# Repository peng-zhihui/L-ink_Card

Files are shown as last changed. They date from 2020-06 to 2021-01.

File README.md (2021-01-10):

# [L-ink]电子墨水屏NFC智能卡片
> 这是为了解决个人使用IC卡时遇到的一些痛点设计的一个迷你NFC智能卡片，基于STM32L051和ST25DV。
>
> 想着既然要自制这玩意那就往炫酷了做，于是很自觉地把电子墨水屏也加上了，顺手也写了个配套APP用于显示内容定制。
>
> 总之是个比较有意思的小项目，方案不算复杂，第一版设计也存在一些值得改进的地方，后续有空会继续优化方案设计的。

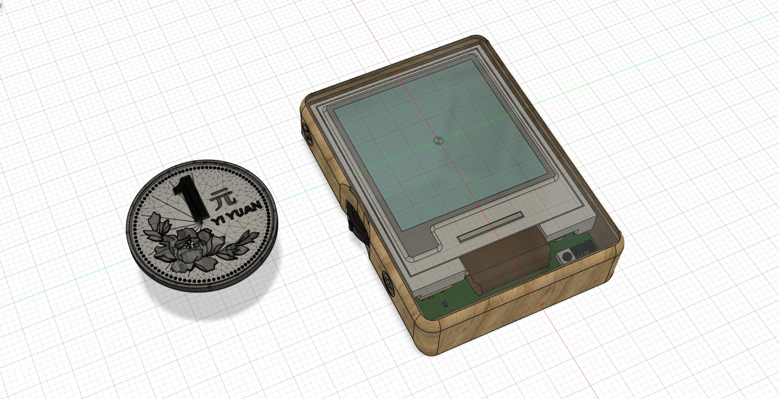
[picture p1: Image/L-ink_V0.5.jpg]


## 演示视频

B站指路：https://www.bilibili.com/video/BV1Cf4y1y7KT/

## 项目文件说明

* **Hardware**：source里面是电路原理图和PCB文件，使用Altium Designer打开；release里面是gerber文件可以直接发给厂家打样，也包含了元器件BOM表（部分IC不太常用可能要单独购买）。
* **Firmware**：STM32L051的固件，我提供了Clion和Keil两个版本的工程文件，源码内容是一致的，分两个版本只是因为个人对Clion爱得深沉。
* **3D Model**：屏幕架和外壳的3D文件，step格式一般3D建模软件都能打开编辑，STL格式用于直接3D打印。
* **DAP-Link**：自己设计的下载调试器的硬件和固件源码，也包括预编译的hex固件，如果你有J-Link或者ST-Link之类的下载器就不用这个了。
* **Android**：配套的APP安装包。

## 固件编译说明

STM32因为使用了L0系列的MCU，所以如果你是第一次在你的电脑上开发STM32L0，那么需要先装一下L0的固件支持包，有两种方式：

1. 使用STM32CubMX安装：

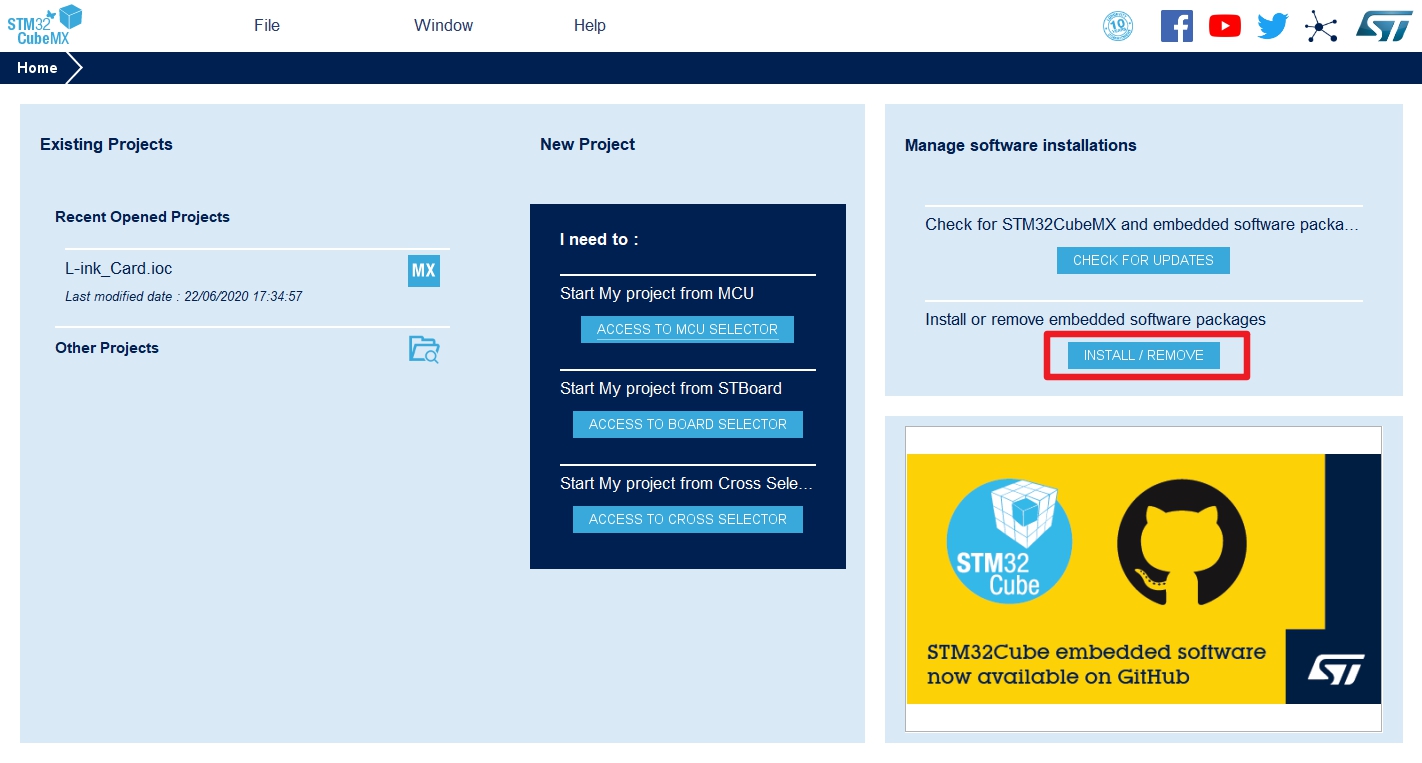
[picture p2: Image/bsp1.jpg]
   

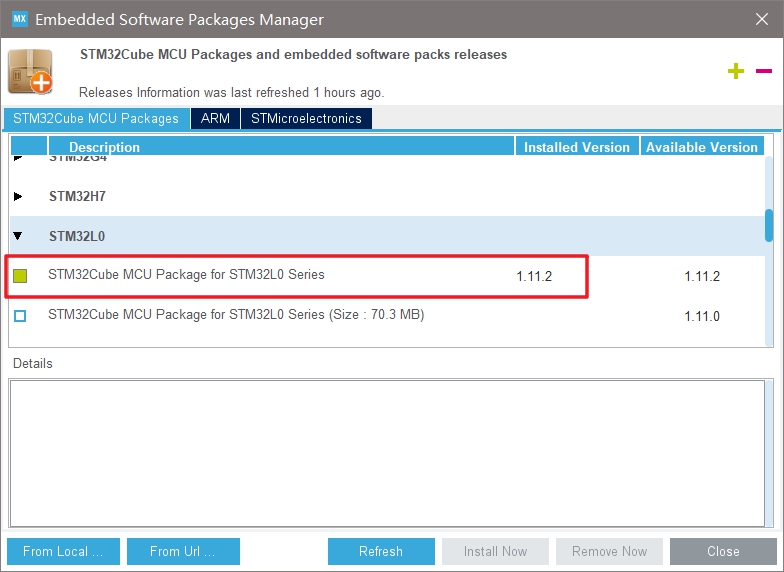
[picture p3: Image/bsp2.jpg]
   

2. 使用Keil的Package Installer安装：

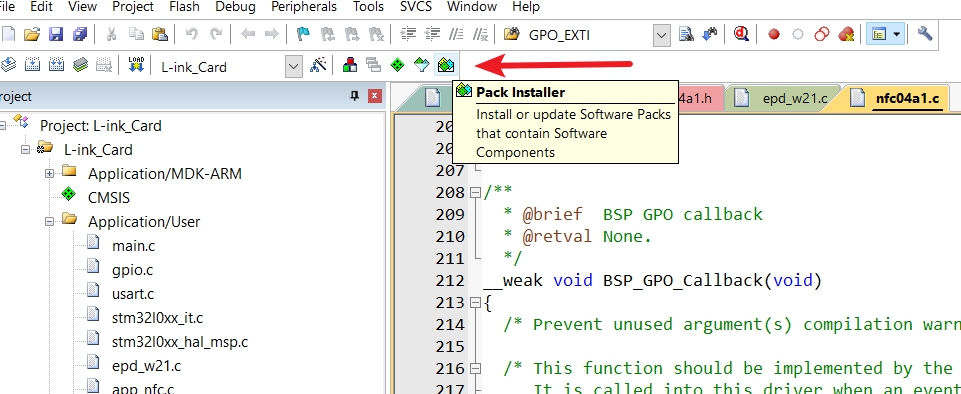
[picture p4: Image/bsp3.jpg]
   

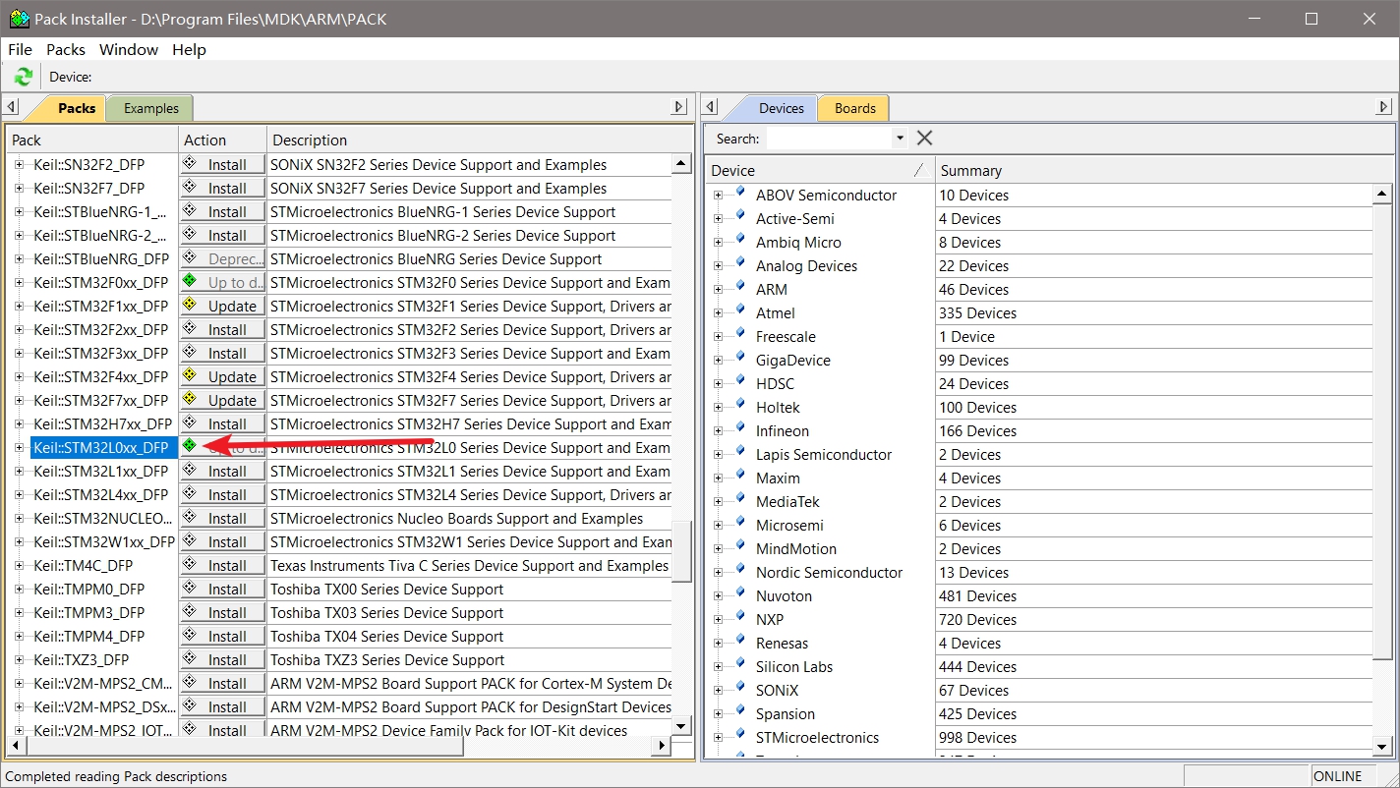
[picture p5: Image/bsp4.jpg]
   

然后就不会报头文件的错误了。

有几点注意的：

* 如果想在Clion中编译工程的话可以参考我这篇教程：https://zhuanlan.zhihu.com/p/145801160
* Clion中OpenOCD默认是使用ST-Link下载，其他下载器自己修改工程目录下的stlink.cfg文件

## 关于硬件方案

硬件方案比较简单，主要IC就两个--STM32和ST25DV，电子墨水屏是200x200的单色屏幕，我是买的微雪的（注意如果是买的几年前的库存，那驱动芯片会有点区别导致代码不通用，只要是新款的应该都没问题）。

ST25DV作为NFC的PHY通过I2C总线和STM32通信，主要作用有两个：能量采集以及NFC通信。注意，ST25DV只是负责和手机进行NFC通信，而不负责IC卡的读写功能，因为**ST25DV只支持ISO 15693的RFID协议，而我们常用的IC卡（M1卡）是ISO 14443协议的**，所以并不能直接使用这颗芯片进行IC卡模拟。

IC卡的模拟功能这一版中实现得比较简单，就是直接集成了多颗UID芯片（很便宜，1~2元一片），然后和ST25DV共用NFC天线，卡片的切换是通过拨轮换挡实现的。好处在于，你可以把L-ink当作多张独立卡片的合集处理，复制和刷卡都是很直接的（使用PM3或者PN532等模块读取原卡信息并写入L-link）。当然缺点就是添加的卡片一多，按键的数量就要增加（因为每一档对应一张卡）。

所以我也在改进方案，后面可能会使用支持ISO 14443协议的ST95或者ST25T系列的芯片来实现软件层面的IC卡模拟功能。

另外下一个版本的硬件方案**我会把黑白的电子墨水屏换成彩色的**。

## 关于配套APP

Android APP目前只是实现了功能，这是基于我以前做的一个算法验证框架APP改的，UI还没有重新做设计，可以等后续更新。

工程文件的话我后面可以把其中的核心功能模块封装成Module，然后给个Sample Project供参考使用，工作太忙等我缓过这阵子先~

## 教程整理中...

有问题先看Issue（包括已经close的），另外

#### 跟项目工程无关的问题不要发在Issues里面！跟项目工程无关的问题不要发在Issues里面！跟项目工程无关的问题不要发在Issues里面！

聊天内容可以给我发评论或者私信（B站、知乎），我看到的话基本都会回复，issue里面发的话所有watch项目的人都会收到邮件，会对大家产生困扰的！

---

**以下是[simonire](https://github.com/simonire)修改的版本，适配新款的屏幕驱动，修改拨轮为五维按键，有需要的可以参考：**

https://github.com/simonire/L-ink_Card



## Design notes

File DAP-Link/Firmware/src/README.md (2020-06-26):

DAPLink (https://armmbed.github.io/DAPLink/)

Arm Mbed DAPLink is an open-source software project that enables programming and debugging application software running on Arm Cortex CPUs. Commonly referred to as interface firmware, DAPLink runs on a secondary MCU that is attached to the SWD or JTAG port of the application MCU. This configuration is found on nearly all development boards. Enumerating as a USB composite device, it creates a bridge between your development computer and the CPU debug access port. DAPLink enables developers with:
* MSC - drag-n-drop programming flash memory
* CDC - virtual com port for log, trace and terminal emulation
* HID - CMSIS-DAP compliant debug channel
* WEBUSB HID - CMSIS-DAP compliant debug channel

More features are planned and will show up gradually over time. The project is constantly under heavy development by Arm, its partners, numerous hardware vendors and the open-source community around the world. DAPLink has superseded the mbed CMSIS-DAP interface firmware project. You are free to use and contribute. Enjoy!

For more detailed usability information [see the users guide.](docs/USERS-GUIDE.md)

## Compatibility
There are many ARM microcontroller-based Hardware Interface Circuits (HICs) that DAPLink interface firmware runs on. These can be found as standalone boards (debugger) or as part of a development kit. Some branded circuits that are known to be IO compatible are:
* [NXP OpenSDA based on K20, K22 and KL26](http://www.nxp.com/products/software-and-tools/run-time-software/kinetis-software-and-tools/ides-for-kinetis-mcus/opensda-serial-and-debug-adapter:OPENSDA)
* [NXP LPC-Link2 based on LPC11U35 or LPC4322](https://www.nxp.com/support/developer-resources/hardware-development-tools/lpcxpresso-boards:LPCXPRESSO-BOARDS)
* [Segger J-Link OB based on Atmel SAM3U](https://www.segger.com/products/debug-probes/j-link/models/j-link-ob/)

## Releases
There are many board builds (board = HIC + target combination) created from this repository. Quarterly releases will contain new features and bugfixes. Standalone bugfixes are released once reported, verified and fixed. Both quarterly and bugfix releases will result in the build number being incremented. Many development kits and products ship with DAPLink interface firmware or are capable of running DAPLink firmware. **[The current release builds and instructions for updating DAPLink interface firmware is hosted on the DAPLink release site.](https://armmbed.github.io/DAPLink/)** Release notes and previous release builds can be found under GitHub releases.

## Contribute

We welcome contributions to DAPLink in any area. Look for an interesting feature or defect [under
issues](https://github.com/ARMmbed/DAPLink/issues), or start a new thread to engage with the
developers and maintainers.

Please see the [contribution guidelines](CONTRIBUTING.md) for detailed requirements for
contributions.

To report bugs, please [create an issue](https://github.com/ARMmbed/DAPLink/issues/new) in the
GitHub project.

## Develop
Information for setting up a development environment, running the tests or creating a release build [can be found in the developers guide.](docs/DEVELOPERS-GUIDE.md)

## License
DAPLink is licensed with the permissive Apache 2.0 license. See the [LICENSE](LICENSE) file for the
full text of the license.

Copyright © 2006-2019 Arm Ltd

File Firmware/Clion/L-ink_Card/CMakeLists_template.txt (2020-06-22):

#THIS FILE IS AUTO GENERATED FROM THE TEMPLATE! DO NOT CHANGE!
SET(CMAKE_SYSTEM_NAME Generic)
SET(CMAKE_SYSTEM_VERSION 1)
cmake_minimum_required(VERSION 3.7)

# specify cross compilers and tools
SET(CMAKE_C_COMPILER_WORKS 1)
SET(CMAKE_C_COMPILER arm-none-eabi-gcc)
SET(CMAKE_CXX_COMPILER_WORKS 1)
SET(CMAKE_CXX_COMPILER arm-none-eabi-g++)
set(CMAKE_ASM_COMPILER arm-none-eabi-gcc)
set(CMAKE_AR arm-none-eabi-ar)
set(CMAKE_OBJCOPY arm-none-eabi-objcopy)
set(CMAKE_OBJDUMP arm-none-eabi-objdump)
set(SIZE arm-none-eabi-size)

SET(LINKER_SCRIPT ${CMAKE_SOURCE_DIR}/STM32L051K8Tx_FLASH.ld)

#Uncomment for hardware floating point
#SET(FPU_FLAGS "-mfloat-abi=hard -mfpu=fpv4-sp-d16")
#add_definitions(-DARM_MATH_CM4 -DARM_MATH_MATRIX_CHECK -DARM_MATH_ROUNDING -D__FPU_PRESENT=1)

#Uncomment for software floating point
#SET(FPU_FLAGS "-mfloat-abi=soft")

SET(COMMON_FLAGS
        "-mcpu=cortex-m0 ${FPU_FLAGS} -mthumb -mthumb-interwork -ffunction-sections -fdata-sections \
    -g -fno-common -fmessage-length=0 -specs=nosys.specs -specs=nano.specs")

SET(CMAKE_CXX_FLAGS_INIT "${COMMON_FLAGS} -std=c++11")
SET(CMAKE_C_FLAGS_INIT "${COMMON_FLAGS} -std=gnu99")
SET(CMAKE_EXE_LINKER_FLAGS_INIT "-Wl,-gc-sections,--print-memory-usage -T ${LINKER_SCRIPT}")

PROJECT(L-ink_Card C CXX ASM)
set(CMAKE_CXX_STANDARD 11)

#add_definitions(-DARM_MATH_CM4 -DARM_MATH_MATRIX_CHECK -DARM_MATH_ROUNDING -D__FPU_PRESENT=1)
add_definitions(-DUSE_HAL_DRIVER -DSTM32L051xx)

file(GLOB_RECURSE SOURCES "startup/*.*" "Packs/*.*" "Drivers/*.*" "Src/*.*" "BSP/*.*")

include_directories(Drivers/BSP/ST25DV Drivers/BSP/E-Paper-Display Inc Drivers/STM32L0xx_HAL_Driver/Inc Drivers/STM32L0xx_HAL_Driver/Inc/Legacy Drivers/CMSIS/Device/ST/STM32L0xx/Include Drivers/CMSIS/Include Drivers/BSP/Components/ST25DV Drivers/BSP/NFC04A1 Drivers/BSP/Drivers/BSP/NFC04A1)

add_executable(${PROJECT_NAME}.elf ${SOURCES} ${LINKER_SCRIPT})

set(CMAKE_EXE_LINKER_FLAGS
        "${CMAKE_EXE_LINKER_FLAGS} -Wl,-Map=${PROJECT_BINARY_DIR}/${PROJECT_NAME}.map")

set(HEX_FILE ${PROJECT_BINARY_DIR}/${PROJECT_NAME}.hex)
set(BIN_FILE ${PROJECT_BINARY_DIR}/${PROJECT_NAME}.bin)

add_custom_command(TARGET ${PROJECT_NAME}.elf POST_BUILD
        COMMAND ${CMAKE_OBJCOPY} -Oihex $<TARGET_FILE:${PROJECT_NAME}.elf> ${HEX_FILE}
        COMMAND ${CMAKE_OBJCOPY} -Obinary $<TARGET_FILE:${PROJECT_NAME}.elf> ${BIN_FILE}
        COMMENT "Building ${HEX_FILE}
Building ${BIN_FILE}")

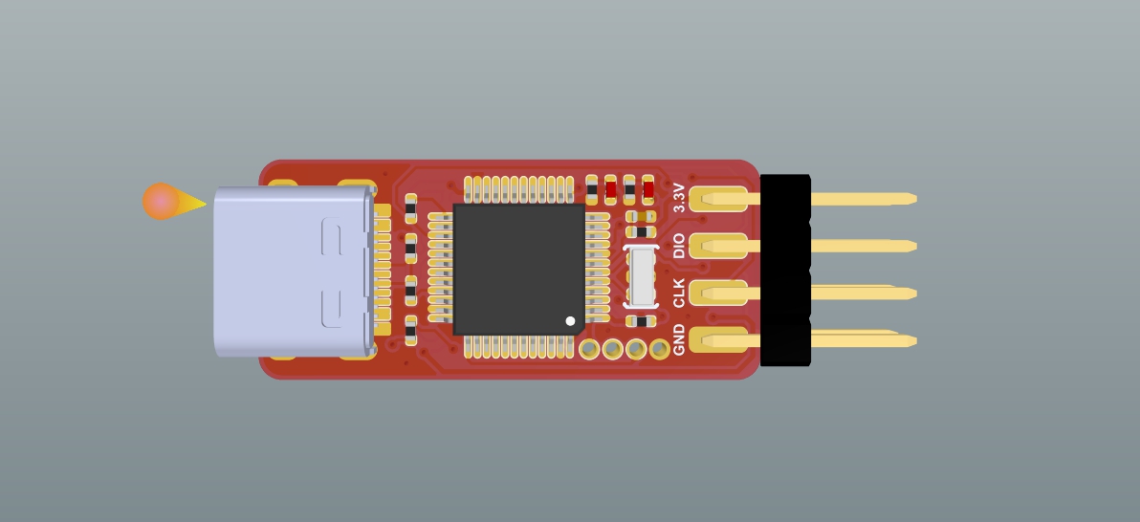
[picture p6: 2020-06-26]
DAP-Link/image.jpg

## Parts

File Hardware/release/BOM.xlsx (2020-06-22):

Comment | Description | Designator | Footprint | LibRef | Quantity
Battery | Battery | Battery1 | CR2032-1 | Battery | 1
10uF | Capacitor | C1 | CAP_0402 | 电容-0402 | 1
10nF | Capacitor | C2 | CAP_0402 | 电容-0402 | 1
0.1uF | Capacitor | C3, C6, C7 | CAP_0402 | 电容-0402 | 3
1uF | Capacitor | C4, C5, C8, C9, C10, C11, C13, C14 | CAP_0402 | 电容-0402 | 8
4.7uF | Capacitor | C12 | 0603-CAP | 电容-0603 | 1
color? | LED | D1 | LED_0402_BLUE | LED_0402 | 1
二极管-5819W | 40V | D2, D3, D4 | SOD-123 | 二极管-5819W | 3
FFC_0.5_24 | FFC | FFC1 | FFC_0.5_24_INK | FFC_0.5_24_INK | 1
跳线 | Resistor | J1 | 0402-0R | 跳线 | 1
TACT 2P | Button | K1 | ButtonTACT_3x4x2_180H | ButtonTACT_3x4x2_180 | 1
68uH | 磁珠 | L1 | 2520-L | 电感-2520 | 1
4.7uH | 磁珠 | L2 | 0805-L | 电感-0805 | 1
HDR1x4_2.0 |  | P1 | HDR 4_2 | HDR1x4_2.0 | 1
MOSFET-N | N-Channel MOSFET | Q1 | SOT23-3 | MOSFET-N | 1
10K | Resistor | R1, R6, R11 | RES_0402 | 电阻-0402 | 3
1K5 | Resistor | R2, R3 | RES_0402 | 电阻-0402 | 2
20K | Resistor | R4 | RES_0402 | 电阻-0402 | 1
1K | Resistor | R5, R7 | RES_0402 | 电阻-0402 | 2
3K | Resistor | R8 | RES_0402 | 电阻-0402 | 1
NC | Resistor | R9 | RES_0402 | 电阻-0402 | 1
0R | Resistor | R10 | RES_0402 | 电阻-0402 | 1
3R | Resistor | R12 | RES_0402 | 电阻-0402 | 1
WHEEL_SWITCH | LDO | S1 | WHEEL_SWITCH | WHEEL_SWITCH | 1
ST25DV16K-JFR6D3 | RFID Transponder IC 13.56MHz ISO 15693 I?2C 1.8V ~ 5.5V 12-UFDFN Exposed Pad | U1 | PSON50P-302X302X60-13N | ST25DV16K-JFR6D3 | 1
STM32L051K8 |  | U2 | QFN-32 | STM32L051K8 | 1
TPS61221DCKT | Boost Switching Regulator IC Positive Fixed 3.3V 1 Output 200mA _Switch_ 6-TSSOP, SC-88, SOT-363 | U3 | SOT65P210X110-6N | TPS61221DCKT | 1

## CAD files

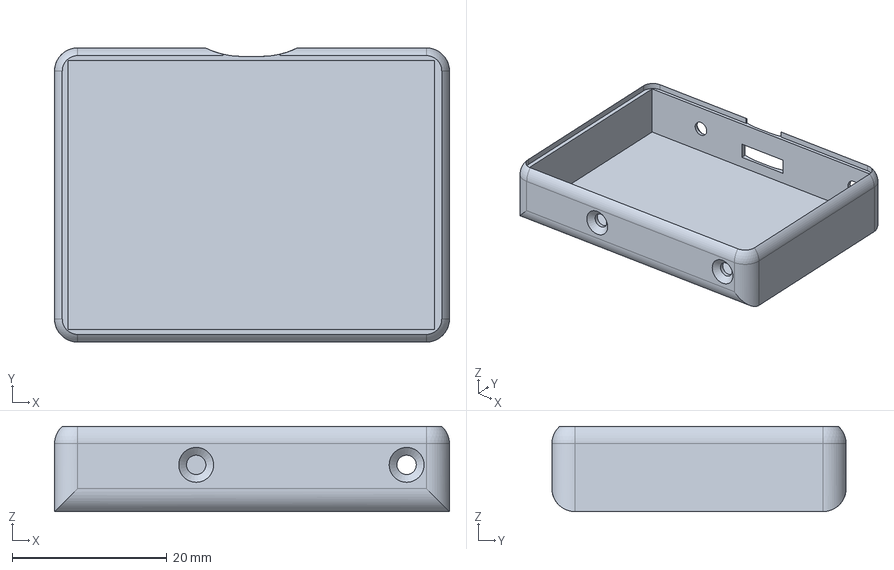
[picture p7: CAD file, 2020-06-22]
3D Model/1.discrete version/case.step
51.0 x 38.0 x 11.0 mm

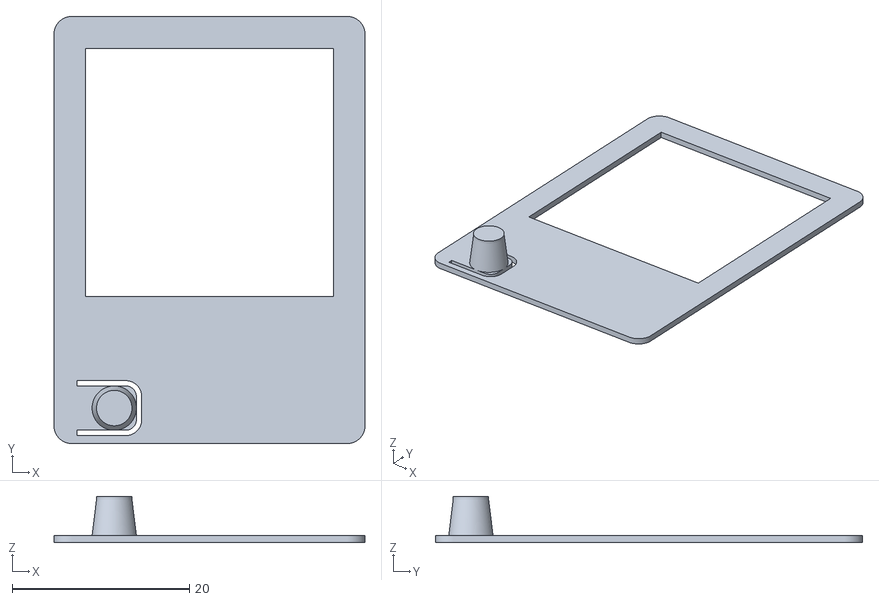
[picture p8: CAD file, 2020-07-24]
3D Model/2.unibody version/L-ink-up.STL.stl
35.1 x 48.2 x 5.20

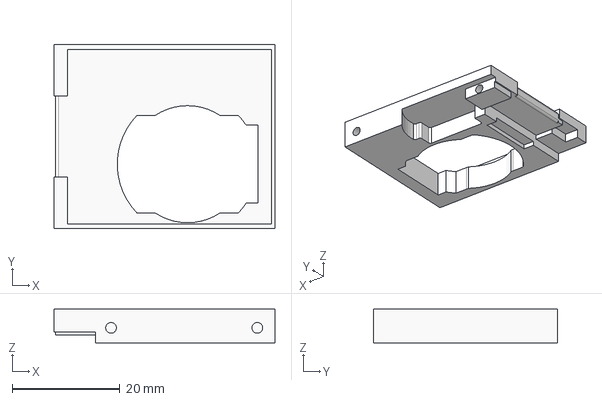
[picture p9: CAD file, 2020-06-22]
3D Model/1.discrete version/stand.step
41.0 x 34.2 x 6.30 mm

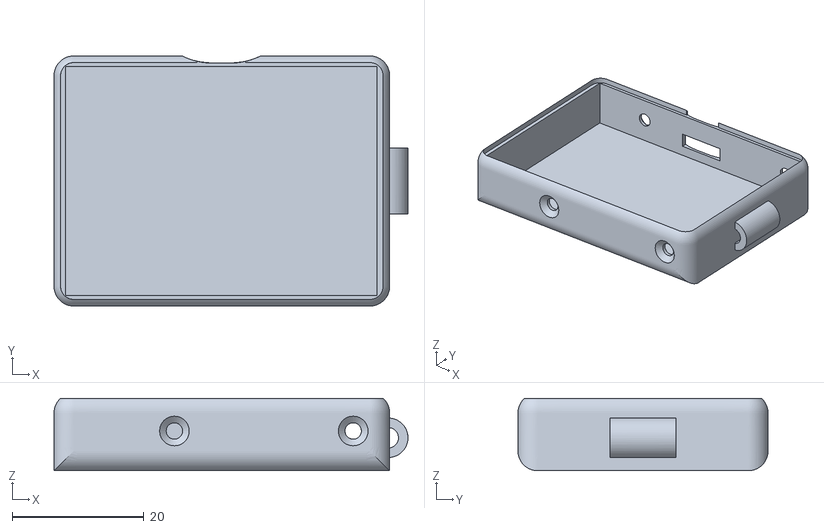
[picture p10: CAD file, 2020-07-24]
3D Model/2.unibody version/case with hook.stl
53.8 x 38.0 x 11.0

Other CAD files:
3D Model/2.unibody version/stand.stl
3D Model/1.discrete version/case.stl
3D Model/1.discrete version/stand.stl

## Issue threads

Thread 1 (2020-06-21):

感谢大佬开源，关注大佬很久了，视频都是跪着看完的~~

luxunchina, 2020-06-21:
这个迷你NFC卡片超酷的啊，有木有？可以复制任意卡片的功能我真是酸了，好想有一个，奈何动手能力极差，希望各位关注此项目的老板做好后给个链接，我想直接买个成品，跪谢~

WHYEX3, 2020-06-21:
3分钟前？readme热乎乎

San12341, 2020-06-21:
我也想直接买成品。

WHYEX3, 2020-06-21:
> 我也想直接买成品。

+1，如果教程我能看懂的话且成本低，我想自己搞一个

peng-zhihui, 2020-06-21:
感谢关注~项目也还是有一些不完善的地方的，后面有空我会继续更新方案的哈

ahdiua, 2020-06-22:
> 感谢关注~项目也还是有一些不完善的地方的，后面有空我会继续更新方案的哈

三连啦，就等大佬发教程

XenoAmess, 2020-06-22:
> 感谢关注~项目也还是有一些不完善的地方的，后面有空我会继续更新方案的哈

硬件和C我这边帮不上忙
如果安卓端放源码的话 可以试试。。。

xdeng, 2020-06-22:
求成品链接，我要买十个。急需。

peng-zhihui, 2020-06-22:
不属于Issue的不要发在这里哈~

Closed 2020-06-22.

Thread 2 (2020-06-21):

大佬能否分享一下android app工程文件

hanjianwei92, 2020-06-21:
大佬能否分享一下app的工程文件

baolintian, 2020-06-21:
+1

peng-zhihui, 2020-06-21:
> 大佬能否分享一下app的工程文件

工程文件的话因为这是我以前做的一个框架改的，而这个框架有用在我们公司的项目里面，所以不知道好不好分享出来。不过我后面可以把其中的核心功能模块封装成库，然后给个Sample Project供参考，等我忙过这阵子吧。

bosssyyyy, 2020-06-21:
大佬能否上传一下ASCII版本的ad文件，目前没有购买安装ad无法转换文件类型

Closed 2020-06-22.

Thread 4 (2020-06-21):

main函数里面的所有头文件报错（file not found）是什么原因呀？

Xuyinsong, 2020-06-21:

peng-zhihui, 2020-06-21:
keil工程还是clion，应该是你工程配置的问题，先保证基础工程（比如新建一个LED点灯工程）能跑通再说。

Xuyinsong, 2020-06-21:
我用的是clion，就是按照您上次分享的博文配置的，有在板子上试过LED灯和串口是可以的。我下载工程文件后就直接用clion打开的，然后就出现了找不到文件的错误，我是第一次用这个，所以配置的问题不是很明白。

peng-zhihui, 2020-06-21:
Clion里面tools-cmake-reset cache... 然后重新编译试试看，另外因为芯片是STM32L0，需要在STM32CubeMX软件的首页选择“INSTALL or REMOVE embedded software...”里面安装L0的支持包

Xuyinsong, 2020-06-22:
可以了，嘿嘿！文件放到桌面就可以编译了，在硬盘的文件夹就会报错，不知道什么原因。

orzMaster, 2020-06-22:
你是不是放在中文目录下了.

Xuyinsong, 2020-06-22:
是的，可能是这个原因

Closed 2020-06-22.

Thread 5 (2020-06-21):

对nfc有个疑问

Guet-Bantao, 2020-06-21:
任意复制卡片的话，不会冲突吗？
比如多个卡片信息都存在同一扇区

peng-zhihui, 2020-06-21:
仔细看一下硬件工程文件，简单地说目前IC卡的信息是存在每个单独的UID芯片（很便宜大概1~2元一个）上的，ST25有两个作用，一个是能量采集，一个是负责作为手机和MCU通信的桥梁（NFC-PHY）；也就是可以理解为L-ink里面是有多个芯片，共用一个线圈，靠开关切换。之所以这么设计，是因为ST25DV支支持ISO 15693协议，而我们常用的IC卡是ISO 14443协议的，所以并不好直接进行模拟。当然也不排除以后会更新方案完善IC模拟功能，现阶段这个方案对我来说是够用的啦。

peng-zhihui, 2020-06-21:
> 任意复制卡片的话，不会冲突吗？
> 比如多个卡片信息都存在同一扇区

仔细看一下硬件工程文件，简单地说目前IC卡的信息是存在每个单独的UID芯片（很便宜大概1~2元一个）上的，ST25有两个作用，一个是能量采集，一个是负责作为手机和MCU通信的桥梁（NFC-PHY）；也就是可以理解为L-ink里面是有多个芯片，共用一个线圈，靠开关切换。之所以这么设计，是因为ST25DV支支持ISO 15693协议，而我们常用的IC卡是ISO 14443协议的，所以并不好直接进行模拟。当然也不排除以后会更新方案完善IC模拟功能，现阶段这个方案对我来说是够用的啦。

jagobaby33, 2020-06-22:
目前市面上的门禁系统大部分只是读取卡片的uid，所以可以方便复制，如果碰到cpu加密或者hid的iclass卡，应该就没办法了

Closed 2020-06-22.

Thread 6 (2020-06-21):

请问怎么把nfc 复制进去???

Wuanson, 2020-06-21:
好像没有看到具体的操作流程,不是按住某个键 ,然后把卡靠近,就可以了????

peng-zhihui, 2020-06-21:
是使用读卡器读取原卡和复制到L-ink里面的，你可以把L-ink当作一个组合了多张IC白卡的设备，就正常复制就行了。我是使用PM3，也可以买个PN532之类的模块，二十多块钱很便宜的。

Wuanson, 2020-06-21:
明白了,谢谢大佬讲解.是我理解错了.哈哈哈

doube1008, 2020-07-21:
> 我是使用PM3，也可以买个PN532之类的模块，二十多块钱很便宜的。

能放个链接么 看淘宝PM3都是大几百的

Closed 2020-06-21.

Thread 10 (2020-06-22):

大佬求教

Shuhaoalex, 2020-06-22:
大佬我是CS专业的，有编程方面的能力，但看你的项目还是一脸懵逼。想求教一下如果想从零基础开始到能设计出像这样的项目，大概需要怎么去点科技树。。。。

XenoAmess, 2020-06-22:
目测主要得点单片机相关的技能点
如果你模电和数电课学的很开心的话可以考虑深入。。。
反正我是放弃硬件了233

peng-zhihui, 2020-06-22:
这个可以看一下我往期的视频和知乎的文章，不属于Issue的不要发在这里哈

Closed 2020-06-22.

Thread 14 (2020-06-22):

我用立创app导入,报错UTF-8编码问题

wangbokun, 2020-06-22:
文件需为UTF-8编码的ASCII格式文件，这个可以调整吗

liangling11411, 2020-06-22:
这个用AD打开没什么问题，我用我用立创导入也有编码问题

peng-zhihui, 2020-06-22:
找个AD软件转换一下吧，立创的我没怎么用过

wangbokun, 2020-06-23:
用AD软件的话，硬件去哪里下单制作， 因为立创有在线下单定做硬件，比较方便,对于我这种小白用户而言.

BH6AOV, 2020-06-23:
utf-8的ASCII在 #17
打样的话导出pcb设计文件给商家就行

wangbokun, 2020-06-23:
a

> utf-8的ASCII在 #17
> 打样的话导出pcb设计文件给商家就行
老哥666，我去试试.

Closed 2020-06-22.

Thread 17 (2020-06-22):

麻烦大佬上传ascii编码的Altium文件

bosssyyyy, 2020-06-22:
麻烦上传一份ascii编码的ad文件，目前我使用的编辑软件不支持ad二进制文件导入。

BH6AOV, 2020-06-22:
您用的立创EDA吧😅我也是，目前在网上找到的官方解决方案没一个成功的，我已经被逼着开始下AD17了233333

bosssyyyy, 2020-06-22:
是(  eda对新手比较友好(((   为了魔改一下两层板去折腾安装ad🌚

BH6AOV, 2020-06-22:
我也是折腾的没办法了(((((((
立创的EDA确实对我这个新手很友好，就是听前辈说立创设计出来的文件有时候去别的软件上会出问题2333333

BH6AOV, 2020-06-22:
http://club.szlcsc.com/article/details_44111_1.html
这个是立创官方给的解决方法，但是我试了之后发现并没有什么卵用🙄

bosssyyyy, 2020-06-22:
那个方案是针对ascii编码下没选择utf-8解决的，这个是二进制编码(好像是)，需要转成ascii。不知道hex直接转有没有用(盲猜没有用，文件头尾什么的也给转了)

BH6AOV, 2020-06-22:
是的，，，我放弃抵抗了，在网上找了个ad17的iso正在下载着呢，3.67GB不挂梯子都下不动（挂了也没快多少）睡醒了应该就差不多下完了

Sorakage033, 2020-06-22:
用AD17转换了一下，转换成ASCII格式会损失一部分信息，直接导入进立创EDA会报DRC错误
链接：https://pan.baidu.com/s/1sIx4CawBqthK2uwkYVPijw
提取码：dp1h

BH6AOV, 2020-06-22:
> 用AD17转换了一下，转换成ASCII格式会损失一部分信息，直接导入进立创EDA会报DRC错误
> 链接：https://pan.baidu.com/s/1sIx4CawBqthK2uwkYVPijw
> 提取码：dp1h

老哥，稳！

wangbokun, 2020-06-23:
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

立创的零件不全呀，只有三个匹配，14个不行，大佬们，还有其他渠道可以打印板子吗?

BH6AOV, 2020-06-23:
> 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
>
> 立创的零件不全呀，只有三个匹配，14个不行，大佬们，还有其他渠道可以打印板子吗?

他说的是有14个型号没匹配上让你手动选一下不是说没有啊23333333

wangbokun, 2020-06-23:
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

嗯嗯.  这个倒是的，我看到有些可以选，我是硬件小白，不知道选哪个替换合适，会不会出现不兼容.

BH6AOV, 2020-06-23:
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

立创里面那些同规格同封装的器件区别基本就是生产厂家和价格的区别23333，只要封装、参数一样理论上是不会出现不兼容的

wangbokun, 2020-06-23:
嗯嗯，好的，那我就准备下个单试试. 电池座那个推荐的产品就有问题，直接给推荐的是5v家用那种电池座，我给换掉了.

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

Sorakage033, 2020-06-23:
> 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
>
> 立创的零件不全呀，只有三个匹配，14个不行，大佬们，还有其他渠道可以打印板子吗?

打板的话不用pcbdoc，直接在嘉立创上传gerber文件就行了

Closed 2020-06-22.

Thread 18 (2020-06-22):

啊 这个实在是太好玩了   我要尝试做一个试试

qi765235401, 2020-06-22:
膜拜大佬！

hwdef, 2020-06-23:
这种无意义的issue。。。。为什么要发呢。。。

XenoAmess, 2020-06-23:
> 这种无意义的issue。。。。为什么要发呢。。。

因为作者做了个视频到B站。。。
然后B站用户怎么说呢小孩子挺多的2333

hwdef, 2020-06-23:
@XenoAmess
如果是因为做视频发到了b站的话，，，这种“啊 这个实在是太好玩了 我要尝试做一个试试”，发到视频评论也行啊。。。。
为什么要来污染issue呢。。。。。

peng-zhihui, 2020-06-23:
项目无关的问题不要发Issue哈，看来我得去readme说明一下...

Closed 2020-06-23.

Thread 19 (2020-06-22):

关于复制加密M1卡的问题

BH6AOV, 2020-06-22:
请问大佬，有些加密了的手机无法复制的那种M1卡要如何复制啊，手持PN532。家里小区门禁卡手机没法复制，fcuk也跑不动

hwdef, 2020-06-23:
仔细看视频，加密卡不能复制是因为手机系统限制，，，这个开源硬件并没有限制。。。。另外不是这个开源硬件相关的问题发到issue里也不好吧。。

BH6AOV, 2020-06-23:
是的，现在的问题不是说问如何复制，问的是怎么复制进L-ink。
在 #7 里up提到用的是PM3和PN532，配套也就是fcuk来跑，问题是有的加密的卡fcuk是跑不出来的

peng-zhihui, 2020-06-23:
拿不到原卡数据的话可能没办法，可以换个设备试试看，我用PM3目前是没有遇到过解不出的卡的

BH6AOV, 2020-06-23:
> 拿不到原卡数据的话可能没办法，可以换个设备试试看，我用PM3目前是没有遇到过解不出的卡的

感谢解答，回头我去试试

Closed 2020-06-23.

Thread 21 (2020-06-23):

关于S1的型号

irongu, 2020-06-23:
bom和sch中都没有s1的准确型号，在某宝上搜了一下拨轮开关、滚轮开关之类的关键词，找到的都是编码器或者有定位柱的自复位开关，明显与footprint不符。
所以请问能否提供一下s1的型号或者更详细的描述，以便于正确的找到对应元件，谢谢。

peng-zhihui, 2020-06-23:
搜 拨轮开关

fu至本段内容₴6jlF1EYHktZ₴咑幵👉淘tao寳👈或点几炼接https://m.tb.cn/h.VLnWz3Z?sm=e9f89f 至流览器【MP3 MP4 手机 拨轮按键 小头拨轮开关 6脚贴片开关 (2个)】

Closed 2020-06-23.

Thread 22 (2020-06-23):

STM32L051和ST25DV的具体型号

Lauv-who, 2020-06-23:
我在官网看到有很多型号，不知道要买哪个[](url)
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希望能解答下，谢谢

wangbokun, 2020-06-23:
> 我在官网看到有很多型号，不知道要买哪个
> 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
> 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希望能解答下，谢谢

大佬，你这个是在哪里下单的呢.我也准备弄一个.

Lauv-who, 2020-06-23:
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

我没下单，不知道能不能买以及购买数量的限制，产地是有中国的

Teng-NUKE, 2020-06-23:
BOM表里有具体型号和封装

Lauv-who, 2020-06-23:
> BOM表里有具体型号和封装

谢谢

peng-zhihui, 2020-06-23:
ST25DV64K，STM32L051K8U6

peng-zhihui, 2020-06-23:
> 我在官网看到有很多型号，不知道要买哪个
> 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
> 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希望能解答下，谢谢

ST25DV64K，STM32L051K8U6

Lauv-who, 2020-06-23:
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

谢谢大佬

doublemarkpro, 2020-06-25:
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

您好，看原理图RFID芯片用的是ST25DV16K，这里您回复又是64K，以哪个为准呢?

peng-zhihui, 2020-06-25:
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

其实都可以，区别只是EEPROM大小不同而已，最好是买64K哈

doublemarkpro, 2020-06-25:
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

好的，元器件已买，pcb自己简单修改了一下已经交去做板，3d打印也交给第三方做去了，另外请教一下，您b站视频中的最后是盖上了一块亚克力外壳吗？这个有无开源尺寸图呢？厚度需要做几个毫米的？谢谢。

Lauv-who, 2020-06-25:
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

大佬在哪里配的单呀，找了很多家都配不齐，谢谢

Closed 2020-06-25.

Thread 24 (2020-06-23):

pcb挖槽位置

Lauv-who, 2020-06-23:
这个在哪开呀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

peng-zhihui, 2020-06-23:
IC0和IC1右边那两个框

Lauv-who, 2020-06-23:
> IC0和IC1右边那两个框

了解，谢谢

Lauv-who, 2020-06-23:
> IC0和IC1右边那两个框

店家说文件没有体现挖空的😥大佬给看下
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

wangbokun, 2020-06-24:
我也遇到同样的问题，店家说需要PCB文件上有开槽，才可以，

fengboo, 2020-06-24:
大佬的PCB上只放了一个board cutout的多边形，没用keepout或机械层画边界，工厂只认keepout或机械层边界，多边形没用。

Lauv-who, 2020-06-24:
> 大佬的PCB上只放了一个board cutout的多边形，没用keepout或机械层画边界，工厂只认keepout或机械层边界，多边形没用。

这我也不会画呀😂小白太难了

wangbokun, 2020-06-24:
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
不知道这个是不是挖槽成功

Closed 2020-06-23.

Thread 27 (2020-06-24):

墨水屏盖板

Lauv-who, 2020-06-24:
盖板是亚克力的吗？具体尺寸是多少，以及开孔的位置，谢谢大佬💪

peng-zhihui, 2020-06-24:
盖板1mm的切割就行了，外壳我设计地比较简单没有开孔，用B-7000胶水粘合的（这是粘手机屏幕的胶，二次开启后可以不留残胶挺好用的）

Lauv-who, 2020-06-24:
> 盖板1mm的切割就行了，外壳我设计地比较简单没有开孔，用B-7000胶水粘合的（这是粘手机屏幕的胶，二次开启后可以不留残胶挺好用的）

谢谢

csr865, 2020-06-25:
请问pcb图在哪，，

Lauv-who, 2020-06-25:
> 请问pcb图在哪，，

请认真阅读项目文件说明

Hardware：source里面是电路原理图和PCB文件，使用Altium Designer打开；release里面是gerber文件可以直接发给厂家打样，也包含了元器件BOM表（部分IC不太常用可能要单独购买）。

Closed 2020-06-24.

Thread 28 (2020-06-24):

Q1的MOS管和贴片滑轮有无具体型号？

doublemarkpro, 2020-06-24:
BOM上的Q1没有具体型号，另外滑轮我看pcb是贴片的，有具体型号吗？

liangling11411, 2020-06-24:
麻烦看一下已经closed的issue，里面都有人问了
https://github.com/peng-zhihui/L-ink_Card/issues/21
https://github.com/peng-zhihui/L-ink_Card/issues/23

Closed 2020-06-24.

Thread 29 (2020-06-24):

开槽位置请教

wangbokun, 2020-06-24:
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
是在这个位置开槽吗？ 看到下面有蓝色的条，可以直接在这里开槽吗？

liangling11411, 2020-06-24:
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
是这里（黄笔圈的地方），你直接这样说就行了
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
预览图：（圈住的地方开槽）
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

Lauv-who, 2020-06-24:
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

在嘉立创下单的话 上传release还是source都可以吗？上传后的具体参数能不能发个图看一下小白不太懂 谢谢

liangling11411, 2020-06-24:
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
是release文件夹下的gerber文件夹，把里面的东西打成压缩包（.zip/.rar)
直接发给pcb生产厂家就行了
我的话没有买钢网，如果焊工不好可以整个钢网辅助一下
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

Lauv-who, 2020-06-24:
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

谢谢您，因为我是小白，所以打算同时下单smt焊接

liangling11411, 2020-06-24:
嗯嗯，玩的开心，没问题了就把issue close一下吧（右下角）

Lauv-who, 2020-06-24:
> 嗯嗯，玩的开心，没问题了就把issue close一下吧（右下角）

谢谢，这个不是我发的issue😀

wangbokun, 2020-06-24:
挖槽那个事情怎么弄的？就给客服说一下就行？不用该文件吗？

liangling11411, 2020-06-24:
> 挖槽那个事情怎么弄的？就给客服说一下就行？不用该文件吗？
先把Gerber文件交给厂家，到时候厂家会回问你开槽的事，你直接说IC0和IC1右边两个框开槽就行了
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

wangbokun, 2020-06-24:
好的，明白了，多谢多谢，

Closed 2020-06-24.

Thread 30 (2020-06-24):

纯小白，能不能告诉下芯片是不是要写东西进去啊，怎么写进去啊？

minemc24236, 2020-06-24:
如题O(∩_∩)O

peng-zhihui, 2020-06-24:
百度一下吧，用jlink或者stlink下载，或者等后面出详细教程（如果有哪个同学实践过程有空写教程也可以联系我帮你发出来~）

csr865, 2020-06-25:
请问下手机上怎么下载文件夹

minemc24236, 2020-06-26:
用电脑吧，软件什么的都是电脑的，手机没法用的

csr865, 2020-06-27:
我想问下用什么刷固件名字型号发下谢谢了

jiangyou233, 2020-06-27:
> 我想问下用什么刷固件名字型号发下谢谢了

天… 我这怎么收到了邮件提醒……  有问题不要这里留言啦   主控用的STM32  需要STLINK 或者Jlink dap下载器进行下载……

iwtywai, 2020-06-27:
up不是发了dap-link的软硬件吗，所以为什么不自己找找

iwtywai, 2020-06-27:
就在同一个项目里

jiangyou233, 2020-06-27:
> 就在同一个项目里

别了 别了 还是纯小白还是买一个下载器吧  这个DAP还是需要下载固件的…… 到时候DAP焊接调试劝退

iwtywai, 2020-06-27:
> > 就在同一个项目里
>
> 别了 别了 还是纯小白还是买一个下载器吧 这个DAP还是需要下载固件的…… 到时候DAP焊接调试劝退
淘宝十几块 调试爽歪歪

Closed 2020-06-24.

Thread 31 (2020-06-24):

up主有BOM清单么?

jkjkiiiii, 2020-06-24:
芯片的型号和拨片还能找到, 电子墨水屏将就找到, 但是很多电阻的阻值、二极管的大小并未提供, 想要复现有点困难. :sob: 求大佬提供BOM清单

spideymooon, 2020-06-27:
你好，bom清单有了？

spideymooon, 2020-06-27:
@jkjkiiiii 你好，你有bom清单了吗？能否分析一下

BH6AOV, 2020-06-27:
> @jkjkiiiii 你好，你有bom清单了吗？能否分析一下

BOM清单UP在文件里有发，自己找一下吧

spideymooon, 2020-06-27:
> > @jkjkiiiii你好，你有bom清单了吗？能否分析一下
>
> BOM清单up在文件里有发，自己找一下吧

好，谢谢

iwtywai, 2020-06-27:
Hardware/release/BOM.xlsx

jkjkiiiii, 2020-06-27:
> 你好，bom清单有了？

虽然有up主发了清单,但是很多还是写的不清楚, 对于我们这种没自己采购过原件的人很不友好(谁让我想做呢:stuck_out_tongue_winking_eye:),我这里有一份比较详细的清单列表+补充说明,可以送给你作为参考
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
如果还嫌图片看的不清可以私聊

spideymooon, 2020-06-27:
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

我的天，太感谢了，就是正愁着有些东西不清楚.蟹蟹！

jikeshen, 2020-06-29:
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

请问拨动开关尺寸是什么，谢谢

jkjkiiiii, 2020-06-29:
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

拨动开关我自己去单独买的,视频里截图然后到淘宝问就有

Closed 2020-06-24.

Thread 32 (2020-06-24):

关于Q1和U3的型号问题

Skylarrkuo, 2020-06-24:
请问Q1用SI2318DS，U3用TPS61221DCKR可以吗

Skylarrkuo, 2020-06-24:
还有就是电容的电压应该怎么选，淘宝上同一uf有不同的电压（小白一枚）

TaXue-DuBa, 2020-06-25:
电容电压指的是最大耐压值。。差不多的就可

TaXue-DuBa, 2020-06-25:
> 还有就是电容的电压应该怎么选，淘宝上同一uf有不同的电压（小白一枚）

电容电压指的是最大耐压值。。差不多的就可以

iwtywai, 2020-06-28:
Mosfet只要是N-都行
电容耐压5V以上

peng-zhihui, 2020-07-01:
LDO只要输出电压一致就行，电容在这个应用中所有型号都能满足，因为工作电压很低（3.3V）

Closed 2020-07-01.

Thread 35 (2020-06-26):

要不要加个北斗的定位模块，实现自动切换卡片

zmykl, 2020-06-26:
我没细看，想问下mcu有应该还有空闲的io口吧，打算搞个北斗的定位模块，实现靠近相应经纬度坐标之后自动切换到对应的卡片，这样逼格更加高也不需要主动去切换了，最近有空的时候我会做下，到时大家一起交流交流

iwtywai, 2020-06-26:
个人觉得可行，但供电要单独考虑，毕竟eh的电太少了不够用，（就算io不够用的话，都有独立供电了还要什么低能耗）
；）

caicai0, 2020-06-26:
能识别读卡器的不同就好了

iwtywai, 2020-06-26:
前提是读卡器发送的信息不同

XenoAmess, 2020-06-26:
能耗其实 感觉 没几个人在意能耗。。。

zmykl, 2020-06-26:
为了节省功耗肯定要做时间判断的，用加速度传感器或者水银开关来触发，之后唤醒MCU检验时间，每次唤醒后判断下时间是否是大于等于上次切换卡片的十分钟后，是的话获取经纬度进行判断刷新，经纬度差异不大就直接休眠，接近某个坐标点2km内，就切换到对应的卡片上。这样基本上可以兼顾功耗和方便性。获取经纬度刷新的时间有半分钟足够了，实际功耗不会很大。

iwtywai, 2020-06-26:
还可以把纽扣电池换成过充过放保护板接上电池组，再加个usb充电

XenoAmess, 2020-06-26:
> 还可以把纽扣电池换成过充过放保护板接上电池组，再加个usb充电

USB充电是个好东西

BH6AOV, 2020-06-27:
但是如果大门门禁和办公室门禁靠得太近的话定位精度不够也就没法正常工作了啊，2km的范围还是有点太大了，UP视频里两次刷卡的距离明显不超过2km（谁家公司大楼会从大门到办公室建2km的走廊啊）

zmykl, 2020-06-27:
> 但是如果大门门禁和办公室门禁靠得太近的话定位精度不够也就没法正常工作了啊，2km的范围还是有点太大了，UP视频里两次刷卡的距离明显不超过2km（谁家公司大楼会从大门到办公室建2km的走廊啊）

我只是针对我自己的使用需求设计出的切换流程，每个人都有自己的需求，自己实现就行了

BH6AOV, 2020-06-27:
> > 但是如果大门门禁和办公室门禁靠得太近的话定位精度不够也就没法正常工作了啊，2km的范围还是有点太大了，UP视频里两次刷卡的距离明显不超过2km（谁家公司大楼会从大门到办公室建2km的走廊啊）
>
> 我只是针对我自己的使用需求设计出的切换流程，每个人都有自己的需求，自己实现就行了

如果能实现的话也挺不错的，支持一下

iwtywai, 2020-06-27:
大家一起搞个合作项目？

BH6AOV, 2020-06-27:
我小白，啥都不会（摊手）

iwtywai, 2020-06-27:
我就会画原理图和写简单程序，pcb画的很丑(<_>)

zhangFanML, 2020-06-28:
位置记录容易实现吗?

iwtywai, 2020-06-28:
我的想法是设置三个功能：读卡，记录位置，关联卡和位置信息，其中关联的话应该是要做成一对多的

RishonLi, 2020-06-28:
> 只要一个电池能撑一个月 就完全能接受

钮扣电池不便宜呀

poisonousfish, 2020-06-28:
先不提各个地区精度问题，根据我的使用GPS经验来说，定位并非说一下就能准确的东西，而是需要开机后一段时间通过多次数据进行计算才能变的准确的,所以低功耗就告别了。

15839619751, 2020-06-28:
每天充一次电我都能接受，另外，可以加太阳能啊

ChuangYu1897, 2020-06-29:
> 每天充一次电我都能接受，另外，可以加太阳能啊

太阳能可以有

BH6AOV, 2020-06-29:
233333333越做越复杂了

kmno4-beep, 2020-06-29:
听说开源项目只要有钱有时间就能跟着做，特意注册一个号来看看大家是怎么一起做的（）

Twillight-7, 2020-06-29:
前来观摩大佬，

Twillight-7, 2020-06-29:
前来观摩大佬

iwtywai, 2020-06-29:
先做起来再说，之后再加功能或免用户干预

XenoAmess, 2020-06-29:
还是先保证安全性吧 确定别人拿同样的手机app没法修改你这个固件上的内容吗。。。

pengzi007, 2020-07-01:
1. 不知道压电转换或机械能转换的功率够不够，如果够的话也可以加进去，现在很多门铃的按钮都是可以直接发电的。
2. 另外如果有比较小的指纹模块也可以集成进来，别人捡到的话也没法用。
当然了，加这些新功能的前提是新加的module要足够小。

peng-zhihui, 2020-07-01:
想法没问题，但是实现起来不太可行。北斗和GPS在室内定位都不可靠的，最简单的场景，同一栋楼的两个房间，除非是高精度的室内定位，否则无法区分的。

iwtywai, 2020-07-01:
如果是加上加速度传感器和陀螺仪辅助呢？

peng-zhihui, 2020-07-02:
> 如果是加上加速度传感器和陀螺仪辅助呢？

这属于惯导应用，不要说低功耗设备，就是机器人上的SLAM系统目前都达不到这个效果。惯导应用最成功的是在导弹和火箭上，用的是一颗上百万万的光纤陀螺仪。

zmykl, 2020-07-02:
我觉得这个只要用水银开关或者震动开关触发唤醒就可以了，没必要上加速度传感器的

发自我的小米手机
在 稚晖 <notifications@github.com>，2020年7月2日 15:48写道：

如果是加上加速度传感器和陀螺仪辅助呢？

这属于惯导应用，不要说低功耗设备，就是机器人上的SLAM系统目前都达不到这个效果。惯导应用最成功的是在导弹和火箭上，用的是一颗上百万万的光纤陀螺仪。

—
You are receiving this because you authored the thread.
Reply to this email directly, view it on GitHub<https://github.com/peng-zhihui/L-ink_Card/issues/35#issuecomment-652845629>, or unsubscribe<https://github.com/notifications/unsubscribe-auth/ANOKA6VCV7CPTW2AMKSCWRTRZQ3URANCNFSM4OJGLXYA>.

kururu111, 2020-07-02:
能不能加个刷一次卡就自己切换成下一张的功能，因为每个人每天的行程差不多都是固定的，只要按顺序让卡片自己切换卡的类型，在app上可以编辑换卡的顺序应该可以吧?

iwtywai, 2020-07-02:
这个可以有，改下程序的事

or2me, 2020-07-06:
> 能不能加个刷一次卡就自己切换成下一张的功能，因为每个人每天的行程差不多都是固定的，只要按顺序让卡片自己切换卡的类型，在app上可以编辑换卡的顺序应该可以吧?或者在linkcard加上时钟模块应该可以玩出更多花样。

就你这个比较靠谱 不要光想着空间维度 时间维度明显简单多了啊 毕竟大部分人的工作生活是规律的

imyip, 2020-07-08:
我觉得滑轮切换, 显示器显示当前卡的编号就好了 ...

hsuehnan, 2020-07-16:
> 我觉得滑轮切换, 显示器显示当前卡的编号就好了 ...

我觉得也是，应该不用多个按键吧，而且功耗这个，不会太介意的，就是不知道交通卡能不能用

iwtywai, 2020-07-16:
我觉得我太难了，到现在连个门禁卡都没有破开，用的pn532

doskoi, 2020-07-18:
GPS相关的芯片基本上只有晴天的户外才有信号

QuietCao, 2020-07-21:
> 我觉得滑轮切换, 显示器显示当前卡的编号就好了 ...

我觉得连显示器都不需要，弄几个灯来显示编号就行了

Glover120213, 2020-07-21:
敬爱的稚晖君：
   我是一名来自常州的初中生，非常喜欢您的项目；
   对于这个问题，我觉得可以增加北斗模块，但是如果运用在自动换卡片上好像有点大材小用，可以针对北斗定位开发项目；
   其次，我有一个想法，就是加入时钟模块，然后将卡片给老人和小孩（这样他们可以利用NFC自己乘车出去玩，还能用卡片进小区门，还可以用它看时间，走丢了有北斗定位）；
   最后，有一些朋友提出可以去掉电子屏，我觉得如果想在这个卡片上开发一些新的有意思的功能，显示器还是要的；如果去掉显示屏，那是不是可以考虑用一开始不加电池的方案，做成精简版？
   祝您身体健康，万事如意！
   此致，
敬礼！
By Gs―Your friend all the time!
Tips:发送自 Windows 10 版邮件<https://go.microsoft.com/fwlink/?LinkId=550986>应用

发件人: QuietCao<mailto:notifications@github.com>
发送时间: 2020年7月21日 12:24
收件人: peng-zhihui/L-ink_Card<mailto:L-ink_Card@noreply.github.com>
抄送: Subscribed<mailto:subscribed@noreply.github.com>
主题: Re: [peng-zhihui/L-ink_Card] 要不要加个北斗的定位模块，实现自动切换卡片 (#35)

我觉得滑轮切换, 显示器显示当前卡的编号就好了 ...

我觉得连显示器都不需要，弄几个灯来显示编号就行了

―
You are receiving this because you are subscribed to this thread.
Reply to this email directly, view it on GitHub<https://github.com/peng-zhihui/L-ink_Card/issues/35#issuecomment-661624849>, or unsubscribe<https://github.com/notifications/unsubscribe-auth/AO5QAS2E2MQJTGPH67SYAV3R4UJ55ANCNFSM4OJGLXYA>.

Glover120213, 2020-07-21:
敬爱的稚晖君：
   我是一名来自常州的初中生，非常喜欢您的项目；
   对于这个问题，我觉得可以增加北斗模块，但是如果运用在自动换卡片上好像有点大材小用，可以针对北斗定位开发项目；
   其次，我有一个想法，就是加入时钟模块，然后将卡片给老人和小孩（这样他们可以利用NFC自己乘车出去玩，还能用卡片进小区门，还可以用它看时间，走丢了有北斗定位）；
   最后，有一些朋友提出可以去掉电子屏，我觉得如果想在这个卡片上开发一些新的有意思的功能，显示器还是要的；如果去掉显示屏，那是不是可以考虑用一开始不加电池的方案，做成精简版？
   祝您身体健康，万事如意！
   此致，
敬礼！

zhangFanML, 2020-07-21:
有趣

发送自 Windows 10 版邮件应用

发件人: Glover120213
发送时间: 2020年7月21日 13:07
收件人: peng-zhihui/L-ink_Card
抄送: zhangFanML; Comment
主题: Re: [peng-zhihui/L-ink_Card] 要不要加个北斗的定位模块，实现自动切换卡片 (#35)

敬爱的稚晖君：
我是一名来自常州的初中生，非常喜欢您的项目；
对于这个问题，我觉得可以增加北斗模块，但是如果运用在自动换卡片上好像有点大材小用，可以针对北斗定位开发项目；
其次，我有一个想法，就是加入时钟模块，然后将卡片给老人和小孩（这样他们可以利用NFC自己乘车出去玩，还能用卡片进小区门，还可以用它看时间，走丢了有北斗定位）；
最后，有一些朋友提出可以去掉电子屏，我觉得如果想在这个卡片上开发一些新的有意思的功能，显示器还是要的；如果去掉显示屏，那是不是可以考虑用一开始不加电池的方案，做成精简版？
祝您身体健康，万事如意！
此致，
敬礼！
—
You are receiving this because you commented.
Reply to this email directly, view it on GitHub, or unsubscribe.

printlin, 2020-07-24:
我可以做软件开发相关的工作，STM32和APP包括服务器程序都可以，要是有硬件大佬正在继续尝试项目的延续，可以联系我。

iwtywai, 2020-07-24:
> 我可以做软件开发相关的工作，STM32和APP包括服务器程序都可以，要是有硬件大佬正在继续尝试项目的延续，可以联系我。

我有一个问题想要请教，可以加一下好友吗？我的qq是2745076015

jiangyou233, 2020-07-24:
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

首先 不加电池 哪里来的供电那  不要来太阳能啥的啦  时钟有电池供电的话 可以一直跑的 公交卡很多都是CPU卡 不能复制

iwtywai, 2020-07-24:
把公交卡里的芯片拆除来焊上去🤤

Glover120213, 2020-07-24:
我是看稚晖在视频里的第一个方案，直接利用芯片供电采集，当时不是因为供电不足不成立么，现在去掉了大部分用电器，是不是可以考虑重新使用那个方案来达到简化结构
By Gs―Your friend all the time!
Tips:发送自 Windows 10 版邮件<https://go.microsoft.com/fwlink/?LinkId=550986>应用

发件人: jiangyou233<mailto:notifications@github.com>
发送时间: 2020年7月24日 22:10
收件人: peng-zhihui/L-ink_Card<mailto:L-ink_Card@noreply.github.com>
抄送: Glover120213<mailto:glover120213@outlook.com>; Comment<mailto:comment@noreply.github.com>
主题: Re: [peng-zhihui/L-ink_Card] 要不要加个北斗的定位模块，实现自动切换卡片 (#35)

敬爱的稚晖君：
我是一名来自常州的初中生，非常喜欢您的项目；
对于这个问题，我觉得可以增加北斗模块，但是如果运用在自动换卡片上好像有点大材小用，可以针对北斗定位开发项目；
其次，我有一个想法，就是加入时钟模块，然后将卡片给老人和小孩（这样他们可以利用NFC自己乘车出去玩，还能用卡片进小区门，还可以用它看时间，走丢了有北斗定位）；
最后，有一些朋友提出可以去掉电子屏，我觉得如果想在这个卡片上开发一些新的有意思的功能，显示器还是要的；如果去掉显示屏，那是不是可以考虑用一开始不加电池的方案，做成精简版？
祝您身体健康，万事如意！
此致，
敬礼！

首先 不加电池 哪里来的供电那 不要来太阳能啥的啦 时钟有电池供电的话 可以一直跑的 公交卡很多都是CPU卡 不能复制

―
You are receiving this because you commented.
Reply to this email directly, view it on GitHub<https://github.com/peng-zhihui/L-ink_Card/issues/35#issuecomment-663557648>, or unsubscribe<https://github.com/notifications/unsubscribe-auth/AO5QASYOKQWKDHLUB5TAP73R5GI43ANCNFSM4OJGLXYA>.

iwtywai, 2020-07-24:
现在整个供电不仍然是energy harvesting吗？电池是给墨水屏用的

jiangyou233, 2020-07-24:
> 现在整个供电不仍然是energy harvesting吗？电池是给墨水屏用的

不是 看原理图 电池通过TPS61221 转为3.3V

jiangyou233, 2020-07-24:
> 我是看稚晖在视频里的第一个方案，直接利用芯片供电采集，当时不是因为供电不足不成立么，现在去掉了大部分用电器，是不是可以考虑重新使用那个方案来达到简化结构 By Gs―Your friend all the time! Tips:发送自 Windows 10 版邮件<[https://go.microsoft.com/fwlink/?LinkId=550986>应用](https://go.microsoft.com/fwlink/?LinkId=550986>%E5%BA%94%E7%94%A8) 发件人: jiangyou233<mailto:notifications@github.com> 发送时间: 2020年7月24日 22:10 收件人: peng-zhihui/L-ink_Card<mailto:L-ink_Card@noreply.github.com> 抄送: Glover120213<mailto:glover120213@outlook.com>; Comment<mailto:comment@noreply.github.com> 主题: Re: [peng-zhihui/L-ink_Card] 要不要加个北斗的定位模块，实现自动切换卡片 (#35) 敬爱的稚晖君： 我是一名来自常州的初中生，非常喜欢您的项目； 对于这个问题，我觉得可以增加北斗模块，但是如果运用在自动换卡片上好像有点大材小用，可以针对北斗定位开发项目； 其次，我有一个想法，就是加入时钟模块，然后将卡片给老人和小孩（这样他们可以利用NFC自己乘车出去玩，还能用卡片进小区门，还可以用它看时间，走丢了有北斗定位）； 最后，有一些朋友提出可以去掉电子屏，我觉得如果想在这个卡片上开发一些新的有意思的功能，显示器还是要的；如果去掉显示屏，那是不是可以考虑用一开始不加电池的方案，做成精简版？ 祝您身体健康，万事如意！ 此致， 敬礼！ 首先 不加电池 哪里来的供电那 不要来太阳能啥的啦 时钟有电池供电的话 可以一直跑的 公交卡很多都是CPU卡 不能复制 ― You are receiving this because you commented. Reply to this email directly, view it on GitHub<[#35 (comment)](https://github.com/peng-zhihui/L-ink_Card/issues/35#issuecomment-663557648)>, or unsubscribe<https://github.com/notifications/unsubscribe-auth/AO5QASYOKQWKDHLUB5TAP73R5GI43ANCNFSM4OJGLXYA>.

开始通过线圈充电给供电的  后来发现读卡器供电大小不一，充电时间也有长短 所以放弃  我没记错的话

iwtywai, 2020-07-24:
那不就是energy harvesting吗...

Fir-Geek, 2020-07-24:
> 那不就是energy harvesting吗...

看下原理图 真相会浮出水面的

Glover120213, 2020-07-24:
好像是哎，但是我觉得可以改得大众化一点……那电池最好改造成充电电池或者设计得便于拆卸那种吧……不然这么好的东西，做好送给一些不懂电路的人，回头长久使用的话对于他们来说好像有点麻烦
By Gs―Your friend all the time!
Tips:发送自 Windows 10 版邮件<https://go.microsoft.com/fwlink/?LinkId=550986>应用

发件人: jiangyou233<mailto:notifications@github.com>
发送时间: 2020年7月24日 22:55
收件人: peng-zhihui/L-ink_Card<mailto:L-ink_Card@noreply.github.com>
抄送: Glover120213<mailto:glover120213@outlook.com>; Comment<mailto:comment@noreply.github.com>
主题: Re: [peng-zhihui/L-ink_Card] 要不要加个北斗的定位模块，实现自动切换卡片 (#35)

我是看稚晖在视频里的第一个方案，直接利用芯片供电采集，当时不是因为供电不足不成立么，现在去掉了大部分用电器，是不是可以考虑重新使用那个方案来达到简化结构 By Gs DYour friend all the time! Tips:发送自 Windows 10 版邮件<https://go.microsoft.com/fwlink/?LinkId=550986>应用<https://go.microsoft.com/fwlink/?LinkId=550986%3E%E5%BA%94%E7%94%A8> 发件人: jiangyou233mailto:notifications@github.com 发送时间: 2020年7月24日 22:10 收件人: peng-zhihui/L-ink_Cardmailto:L-ink_Card@noreply.github.com 抄送: Glover120213mailto:glover120213@outlook.com; Commentmailto:comment@noreply.github.com 主题: Re: [peng-zhihui/L-ink_Card] 要不要加个北斗的定位模块，实现自动切换卡片 (#35<https://github.com/peng-zhihui/L-ink_Card/issues/35>) 敬爱的稚晖君： 我是一名来自常州的初中生，非常喜欢您的项目； 对于这个问题，我觉得可以增加北斗模块，但是如果运用在自动换卡片上好像有点大材小用，可以针对北斗定位开发项目； 其次，我有一个想法，就是加入时钟模块，然后将卡片给老人和小孩（这样他们可以利用NFC自己乘车出去玩，还能用卡片进小区门，还可以用它看时间，走丢了有北斗定位）； 最后，有一些朋友提出可以去掉电子屏，我觉得如果想在这个卡片上开发一些新的有意思的功能，显示器还是要的；如果去掉显示屏，那是不是可以考虑用一开始不加电池的方案，做成精简版？ 祝您身体健康，万事如意！ 此致， 敬礼！ 首先 不加电池 哪里来的供电那 不要来太阳能啥的啦 时钟有电池供电的话 可以一直跑的 公交卡很多都是CPU卡 不能复制  D You are receiving this because you commented. Reply to this email directly, view it on GitHub<#35 (comment)<https://github.com/peng-zhihui/L-ink_Card/issues/35#issuecomment-663557648>>, or unsubscribehttps://github.com/notifications/unsubscribe-auth/AO5QASYOKQWKDHLUB5TAP73R5GI43ANCNFSM4OJGLXYA.

开始通过线圈充电给供电的 后来发现读卡器供电大小不一，充电时间也有长短 所以放弃 我没记错的话

―
You are receiving this because you commented.
Reply to this email directly, view it on GitHub<https://github.com/peng-zhihui/L-ink_Card/issues/35#issuecomment-663579223>, or unsubscribe<https://github.com/notifications/unsubscribe-auth/AO5QASZERMKM5BDZ2TY6GA3R5GOE3ANCNFSM4OJGLXYA>.

iwtywai, 2020-07-24:
可以考虑一下过充过放保护板+可充电电池+usb，只要留个口就可以

NBchitu, 2020-08-15:
我提供下自己的思路：
1、根据时间段来自动学习并存储刷卡习惯，前面学习一段时间后设备就记录下你的使用习惯，加入点简单的AI学习的功能，如根据时间、当天第几次刷卡等特征值来对当前刷卡机做一个预测；
2、针对1中预测失败的情况，设备马上切换到预测概率第2大的卡进行刷卡操作，也就是实现自动轮询枚举
以上是否可行大家可以探讨下。

iwtywai, 2020-08-15:
想法是好的，但是用stm训练ai不现实，根据st官方的网站https://www.st.com/content/st_com/zh/about/innovation---technology/artificial-intelligence.html，arm cortex m是只能运行预训练的神经网络的

iwtywai, 2020-08-15:
如果只是根据时间来计算的话倒是有可能实现

huarongze, 2020-10-11:
>
>
> 我可以做软件开发相关的工作，STM32和APP包括服务器程序都可以，要是有硬件大佬正在继续尝试项目的延续，可以联系我。

多年的硬件工程师，一起讨论下项目的延续，Q422968316

SNGDude, 2020-12-31:
有点远了吧兄弟们，pcb图好说，关键这么叠罗汉不是成手机了。就这么大接触面积一块eink还要上太阳能，还要加北斗定位，室内京东那你用wifi定位+Celluar，这耗电量。

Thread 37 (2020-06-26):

UID硬件连接

782884341, 2020-06-26:
如何把uid芯片集成在PCB上，是可以直接焊在ST25DV的引脚上面和NFC公用天线吗

iwtywai, 2020-06-27:
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如果我没有理解错的话，应该是中间这两个开窗的位置

782884341, 2020-06-27:
那如果要扩展更多的卡，是不是得要修改PCB，增加UID位

iwtywai, 2020-06-27:
emmm好像是，毕竟up也说这个st25dv模拟不了15xxx的卡，所以模拟完全是靠共用天线的芯片实现的

peng-zhihui, 2020-06-28:
对的，可以自己添加uid的卡位，不用考虑线圈遮挡整个背面都是可以添加的。另外下一版我会加入软件模拟IC功能，卡多的话建议等后续更新。

Closed 2020-06-28.

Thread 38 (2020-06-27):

关于导出Gerber

BH6AOV, 2020-06-27:
在立创上用UTF-8存的ASCII的pcb设计文件准备导出gerber去打样了，但是发现网络和DRC有一大堆报错，是直接忽略就行吗
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

iwtywai, 2020-06-27:
在Hardware文件夹有up给的gerber啊

BH6AOV, 2020-06-27:
> 在Hardware文件夹有up给的gerber啊

立创打不开的

BH6AOV, 2020-06-27:
> 在Hardware文件夹有up给的gerber啊

具体见#17

iwtywai, 2020-06-27:
找个打板的把gerber扔过去就行

BH6AOV, 2020-06-27:
> 找个打板的把gerber扔过去就行

我试试直接扔下单助手上

iwtywai, 2020-06-27:
记得打包.zip

BH6AOV, 2020-06-27:
> 记得打包.zip

妥

BH6AOV, 2020-06-27:
> 找个打板的把gerber扔过去就行

立创那边直接gerber解析超时了

iwtywai, 2020-06-27:
可以多试几次，或者直接在淘宝找一家打板，我是在淘宝打的

BH6AOV, 2020-06-27:
> 可以多试几次，或者直接在淘宝找一家打板，我是在淘宝打的

多少钱啊。。。我能给PCB的预算非常少

iwtywai, 2020-06-27:
我打的无铅黑油，50元5张板

minemc24236, 2020-06-27:
立创5元的，50打针土豪

minemc24236, 2020-06-27:
我是像楼主你这么打的，我看报错是地线和天线，也就没管而且就5元吗，大不了再打一版awa

iwtywai, 2020-06-27:
（我当时打板子gerber文件up还没传，所以用不了jlc）

ZKLgayhub, 2020-06-27:
1.图1,底层贴片层多出来的开窗要在底层阻焊层开上窗吗 2，图2，箭头位的锣槽输出文件仅在底层字符层有框，就按底层字符层框的大小5*4MM锣出方槽吧

求问，是PCB厂家发过来的，本人小白完全不懂

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

BH6AOV, 2020-06-27:
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

@peng-zhihui

BH6AOV, 2020-06-27:
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

#29

peng-zhihui, 2020-06-28:
解析超市不用管，是嘉立创软件的问题，直接提交确认就行

Closed 2020-06-28.

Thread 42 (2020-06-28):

外壳怎么办啊  有没有帮忙的 我这边可以出邮费和材料费   或者我做好电路板互换！

jiangyou233, 2020-06-28:
我这边不知道怎么加工外壳 有没有互助的呀！

shaoyu1207, 2020-06-28:
可以3D打印

jiangyou233, 2020-06-28:
> 可以3D打印

上某宝吗 材料贵吗

jiangyou233, 2020-06-28:
> 可以3D打印

上某宝吗 东西贵吗……

iwtywai, 2020-06-28:
十几块的事

shaoyu1207, 2020-06-28:
不贵，某宝上面直接打印一下就行，有的店铺首单是只要交运费的

jiangyou233, 2020-06-28:
> 不贵，某宝上面直接打印一下就行，有的店铺首单是只要交运费的

OK感谢 问题关了

jiangyou233, 2020-06-28:
> 十几块的事

OK感谢 问题关了

GeorgeMicro, 2020-07-23:
还有兴趣换嘛 我有3D打印机

agentZhang, 2022-03-31:
> 我这边不知道怎么加工外壳 有没有互助的呀！

您好请问您愿意出电路板吗我想购买一个，或者可不可以给我您的email我们再讨论

agentZhang, 2022-03-31:
谢谢您的回复，我这边看了一下未来工厂好像是做3d打印的，这个我不需要，现在想要一个焊好的电路板

发自我的iPhone

------------------ 原始邮件 ------------------
发件人: ruinanzhu ***@***.***&gt;
发送时间: 2022年3月31日 20:06
收件人: peng-zhihui/L-ink_Card ***@***.***&gt;
抄送: agentZhang ***@***.***&gt;, Comment ***@***.***&gt;
主题: 回复：[peng-zhihui/L-ink_Card] 外壳怎么办啊  有没有帮忙的 我这边可以出邮费和材料费   或者我做好电路板互换！ (#42)

 未来工厂，几十块钱就能搞定发自我的华为手机-------- 原始邮件 --------发件人： agentZhang ***@***.***&gt;日期： 2022年3月31日周四 19:45收件人： peng-zhihui/L-ink_Card ***@***.***&gt;抄送： Subscribed ***@***.***&gt;主    题： Re: [peng-zhihui/L-ink_Card] 外壳怎么办啊  有没有帮忙的 我这边可以出邮费和材料费   或者我做好电路板互换！ (#42)

 我这边不知道怎么加工外壳 有没有互助的呀！

 您好请问您愿意出电路板吗我想购买一个，或者可不可以给我您的email我们再讨论

 —Reply to this email directly, view it on GitHub, or unsubscribe.You are receiving this because you are subscribed to this thread.Message ID: ***@***.***&gt;
—
Reply to this email directly, view it on GitHub, or unsubscribe.
You are receiving this because you commented.Message ID: ***@***.***&gt;

Closed 2020-06-28.

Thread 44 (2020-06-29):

那磁珠那个是用磁珠呢还是用电感呢> 你好，bom清单有了？

782884341, 2020-06-29:
> 你好，bom清单有了？

虽然有up主发了清单,但是很多还是写的不清楚, 对于我们这种没自己采购过原件的人很不友好(谁让我想做呢:stuck_out_tongue_winking_eye:),我这里有一份比较详细的清单列表+补充说明,可以送给你作为参考
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
如果还嫌图片看的不清可以私聊

_Originally posted by @jkjkiiiii in https://github.com/peng-zhihui/L-ink_Card/issues/31#issuecomment-650559239_

wangbokun, 2020-06-29:
你是在哪个站买的元件.

jiangyou233, 2020-06-29:
> 你是在哪个站买的元件.

哈哈 我也想知道 感觉那个NFC芯片有点小贵

jkjkiiiii, 2020-06-29:
磁珠

doublemarkpro, 2020-06-30:
这个ST25DV64K是真难买，淘宝几家都是7-10天，索性就在立创商场买了

yelvlab, 2020-07-01:
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

FPC座子是抽屉式还是翻盖式的

Lauv-who, 2020-07-01:
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

这个备注貌似是我做的 哈哈

jkjkiiiii, 2020-07-01:
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

Thanks♪(･ω･)ﾉ感谢, 借用一下你的备注. 看来我们在淘宝选择了同一家店铺, 他们家电阻电容都是100个起卖, 我跟他们说能不能我50个电阻你50个电阻, 店员说不可以.hhhhhh

Lauv-who, 2020-07-01:
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

是的一套下来好几百 我已经焊坏三个板子了 😥

im12, 2020-07-01:
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

算下来一套成本93吧，我已经做完了

Lauv-who, 2020-07-01:
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

大佬怎么焊的

yelvlab, 2020-07-01:
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

大佬，你的24p fpc是抽屉式的还是下翻盖的，然后ST25DV是立创商城还是淘宝买的啊，然后UID芯片呢

im12, 2020-07-01:
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

锡膏加风枪，和稚晖大佬视频里的差不多吧，我没做钢网，直接用针筒点的锡膏

Lauv-who, 2020-07-01:
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

我买了焊台 6脚的拨片开关焊的连锡 坏了3板子 我去买个风枪 谢谢大佬

im12, 2020-07-01:
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

24p我用的是抽屉式的，理论上翻盖的也可以用，只要是下接的都行；ST25DV是淘宝上一家家问过来终于有一家有现货就买了，04K到64K都可以用，up的程序里只用了其中的mailbox，没用eprom，所以大小无所谓，up好像是在贸泽电子买的，我上去看了确实有货还不贵，可以考虑；最后UID芯片的话，我没有写卡设备也不想做啥卡模拟，就直接买了几颗NTAG213的芯片做nfc标签了，实现功能的话比如一刷直接连上我家WiFi这种

peng-zhihui, 2020-07-01:
多谢分享哈

laucong, 2020-07-23:
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

你好，想问下波动开关的型号是什么呢，淘宝买的时候店家说需要提供型号~

GaoChen-git, 2020-08-07:
> 多谢分享哈
UP，你的UID芯片型号是啥呀？

GaoChen-git, 2020-08-07:
> > 多谢分享哈
> > UP，你的UID芯片型号是啥呀？

然后写卡还需要买其他模块吗？有啥步骤方法？

mdhuang555, 2020-09-22:
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

可以买个电容电阻样品册，这样就什么型号的电阻电容都有了

ice-shimmer, 2020-10-20:
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

大佬我没啥焊接基础，某宝有没有这种代购材料+焊接的服务啊

iwtywai, 2020-10-20:
可以在嘉立创下smt订单的

ice-shimmer, 2020-10-20:
> 可以在嘉立创下smt订单的

搜嘎，多谢大佬

jkjkiiiii, 2020-10-20:
不会很便宜就是了:laughing:

PANZERUI, 2020-11-26:
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

怎么联系您呢，有没有VX啥的

SaleJuice, 2021-04-07:
我想知道水墨屏是什么型号的呢？有人知道吗？

ruinanzhu, 2021-04-07:
微雪1.54寸两色墨水屏-------- 原始邮件 --------发件人： SaleJuice ***@***.***>日期： 2021年4月7日周三 10:56收件人： peng-zhihui/L-ink_Card ***@***.***>抄送： Subscribed ***@***.***>主    题： Re: [peng-zhihui/L-ink_Card] 那磁珠那个是用磁珠呢还是用电感呢> 你好，bom清单有了？ (#44)

我想知道水墨屏是什么型号的呢？有人知道吗？

—You are receiving this because you are subscribed to this thread.Reply to this email directly, view it on GitHub, or unsubscribe.

liu-x-sh, 2021-04-15:
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

想问下拨盘电位器有推进链接或者型号嘛？为什么我淘宝买了几个都不合适？

Ceoha, 2021-05-09:
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

有人做成功了吗

OCEANOUXIN, 2021-11-25:
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

请问有文档吗，感谢

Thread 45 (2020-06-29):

BOM清单购买问题

wangbokun, 2020-06-29:
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
还有九款元件没找到在哪里买，哪位大神给知道.

wangbokun, 2020-06-29:
电池扣我的链接好像是错的，上面找的是个圆形的， 看别人发的是这款:
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

购买链接如下:

https://item.taobao.com/item.htm?spm=a1z10.3-c.w4002-21822726391.28.7644315aWrBTWI&id=592903534595

wangbokun, 2020-06-29:
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

Blueanr, 2020-06-29:
1、墨水屏 200x200单色微雪4、
10、 立创商城难道没有0Ω0402的电阻卖吗

Blueanr, 2020-06-29:
1、墨水屏 200x200单色微雪4、
10、 立创商城难道没有0Ω0402的电阻卖吗

jiangyou233, 2020-06-29:
r9怎么破  不接吗？

Blueanr, 2020-06-29:
1、墨水屏 200x200单色微雪
3、BOM单里0603的电容我只看到有一个C12 4.7uf
4、STM32L0随便买
8、立创商城（淘宝）难道没有ST25DV16K-JFR6D3卖吗
9、开关
10、 立创商城（淘宝）难道没有0Ω0402的电阻卖吗
11、4pin插座
12、立创商城（淘宝）难道没有68uH2520的电感卖吗
14、立创商城（淘宝）难道没有TPS61221DCKT卖吗

yelvlab, 2020-06-30:
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

分享一下我的精力
> 8 发货都很慢，倒不是找不到
> 9 我是tb搜贴片拨轮，然后找的6脚的
> 12 高频电感我是tb买的

ruinanzhu, 2020-07-01:
有没有大佬做完出售一个

jiangyou233, 2020-07-01:
物料成本将近70   还没算人工

ruinanzhu, 2020-07-01:
> 物料成本将近70 还没算人工

我自己做5个得快500成本，还不包括找同事帮忙焊板子请吃饭的钱

Sloan-Lin, 2020-07-01:
话说找嘉立创做PCB和SMT的话整个板做好要多少钱？（纯小白发言）

csr865, 2020-07-02:
bom表中有几个参数不完整怎么回事

csr865, 2020-07-02:
有5个没有具体封装型号

BH6AOV, 2020-07-02:
这是我在立创的购买清单，有的型号不太一样但是是理论可以通换的，成本已经尽我所能压到最低了233333

购买类型 | 商品编号 | 物料编码 | 商品分类 | 名称 | 商品型号 | 品牌 | 封装规格 | 单个毛重 | 购买数量 | 商品单价 | 金额
-- | -- | -- | -- | -- | -- | -- | -- | -- | -- | -- | --
常规 | C557591 |   | 轻触开关 | 轻触开关 3*4*2 两脚小龟不带柱 250gf 黑色塑胶按钮 | TS342A2P-WZ | SHOU HAN(首韩) | SMD | 0.000126 | 20 | ￥0.184220 | ￥3.68
常规 | C262567 |   | FFC，FPC连接器 | FPC 0.5MM 24P 拉抽式 H2.0mm 下接 | AFC07-S24FCA-00 | JS(钜硕电子) | P=0.5mm | 0.000570 | 10 | ￥0.568392 | ￥5.68
常规 | C541858 |   | 排针排母 | 排针 间距2.0mm 4P 单排直插 | PZ200V-11-04P | XFCN(台湾兴飞) | Through Hole,P=2.00mm | 0.000127 | 50 | ￥0.088426 | ￥4.42
常规 | C487769 |   | MOS(场效应管) | UTC   场效应管 | 2N7002KG-AE2-R | UTC(友顺) | SOT23-3 | 0.000017 | 20 | ￥0.132145 | ￥2.64
常规 | C64885 |   | 肖特基二极管 | B5819W   SL | B5819W | MDD | SOD-123 | 0.000035 | 40 | ￥0.106373 | ￥4.25
常规 | C401112 |   | 发光二极管 | LED贴片0402高亮蓝色光 | MHT136UBCT | MEIHUA(美华科技) | 0402 | 0.000020 | 10 | ￥0.227351 | ￥2.27
常规 | C70378 |   | 电池盒/电池座 | CR2032电池 镀金贴片卧式底座 | BS-8-1 | Q&J | 贴片 | 0.001300 | 10 | ￥1.0728 | ￥10.73
常规 | C5407 |   | 电池 | 3V  纽扣电池 | CR2032 | 天球 | 20×3.2 | 0.004280 | 10 | ￥0.745056 | ￥7.45
常规 | C140214 |   | 贴片电阻 | 10KΩ(103)   ±5% | RC-02W103JT | FH(风华) | 0402 | 0.000022 | 100 | ￥0.003227 | ￥0.32
常规 | C140224 |   | 贴片电阻 | 0Ω(000)   ±5% | RC-02000JT | FH(风华) | 0402 | 0.000022 | 100 | ￥0.003476 | ￥0.35
常规 | C83062 |   | 贴片电容 | 10nF(103) ±10% 50V | 0402B103K500 | 华新科(Walsin) | 0402 | 0.000010 | 100 | ￥0.008623 | ￥0.86
常规 | C99226 |   | 贴片电容 | 4.7uF(475) ±10% 16V | 0603B475K160NT | FH(风华) | 0603 | 0.000030 | 20 | ￥0.212655 | ￥4.25
常规 | C387941 |   | 贴片电容 | 100nF(104) ±10% 10V | 0402B104K100CT | 华新科(Walsin) | 0402 | 0.000010 | 100 | ￥0.009396 | ￥0.94
常规 | C106833 |   | 贴片电容 | 10uF(106) ±20% 6.3V | 0402X106M6R3 | 华新科(Walsin) | 0402 | 0.000010 | 20 | ￥0.197150 | ￥3.94
常规 | C144761 |   | 贴片电阻 | 3KΩ(3001)   ±1% | AC0402FR-073KL | YAGEO(国巨) | 0402 | 0.000009 | 100 | ￥0.008709 | ￥0.87
常规 | C379996 |   | 贴片电感 | 4.7uH   ±20% | MIP20124R7MBP | INPAQ(台湾佳邦) | 0805 | 0.000044 | 20 | ￥0.213947 | ￥4.28
常规 | C25545 |   | 贴片电阻 | 20KΩ   ±5% | 0402WGJ0203TCE | UNI-ROYAL(厚声) | 0402 | 0.000009 | 100 | ￥0.003126 | ￥0.31
常规 | C25930 |   | 贴片电阻 | 1.5KΩ   ±5% | 0402WGJ0152TCE | UNI-ROYAL(厚声) | 0402 | 0.000009 | 100 | ￥0.003279 | ￥0.33
常规 | C107372 |   | 贴片电容 | 1uF(105) ±10% 6.3V | CL05A105KQ5NNNC | SAMSUNG(三星) | 0402 | 0.000013 | 100 | ￥0.013405 | ￥1.34
常规 | C279987 |   | 贴片电阻 | 1KΩ(102)   ±5% | CR-02JL6----1K | 光颉(Viking) | 0402 | 0.000009 | 100 | ￥0.001970 | ￥0.20
常规 | C166647 |   | 贴片电阻 | 3Ω(3R0)   ±5% | RTT023R0JTH | RALEC(旺诠) | 0402 | 0.000009 | 100 | ￥0.003609 | ￥0.36
赠品 | C500622 |   | 其余赠品 | SOP16封装音频功率放大器方案验证板 | SOP16封装音频功率放大器方案验证板 | LC(立创) | - | 0.003830 | 1 | ￥0 | ￥0
  |   |   |   |   |   |   |   |   |   | 合计 | ￥59.47

pcwuyu, 2020-07-06:
有没有大佬做好成品出售的？有的话联系我呗，一个就成

halflesson, 2020-07-23:
拨动的开关型号是啥样的呀，淘宝怎么搜索呢

iwtywai, 2020-07-23:
在risym家搜贴片拨轮就行

xiaxichen, 2023-09-23:
你好 C83062 C99226 的替代品是什么呢？

Rulsion, 2023-09-23:
已收到，放心

Blueanr, 2023-09-23:
> 你好 C83062 C99226 的替代品是什么呢？

随便找两个封装一样参数相同的电容就行了

xiaxichen, 2023-10-28:
请问一下这个芯片买哪个呢？

> > 你好 C83062 C99226 的替代品是什么呢？
>
> 随便找两个封装一样参数相同的电容就行了

Blueanr, 2023-10-28:
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
根据这两个参数随便买

Blueanr, 2023-10-28:
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
根据这两个参数随便买
0402封装10nf电容和0603封装4.7uf电容

xiaxichen, 2023-10-28:
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

对这个我买到了 谢谢 好心人， 主要是除了这些电容我还需要买什么呢？

Closed 2020-07-13.

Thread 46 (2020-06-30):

ST25DV的购买问题

liangling11411, 2020-06-30:
有没有人有ST25DV64K的购买地址，在网上搜都说没货。

lewin0301, 2020-06-30:
都是20天以后发货

lewin0301, 2020-06-30:
立创商城有,具体到收货多久不知道

liangling11411, 2020-06-30:
好不容易在阿里巴巴上找到了，但要10天配货，放出来帮助一下大家吧
【ST25DV16K-JFR6D3【IC RFID TRANSP 13.56MHZ 12UFDFPN】】复制￥zS02ezN96VCap￥，打开【手机阿里】或【支付宝-点首页进行搜索】查看：https://qr.1688.com/share.html?secret=m35uFKSs

Closed 2020-06-30.

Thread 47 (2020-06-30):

请教关于方案设计方面的问题，有关ST25DV、拨轮、天线和开口

yelvlab, 2020-06-30:
> 这个应该不算是无关问题吧，并且不是很懂，特地来请教

### 最大的疑惑：底部两个开口的作用

看底部两个开口旁边还有焊盘，同时看原理图里面给的网络标识是ant，同时接到拨轮里面，这部分没太看懂，请大佬解答下，或者哪里有相关资料

im12, 2020-06-30:
波轮是一个多入单出的开关，本来ant是闭环的天线，UP切断了加入了开关，平时按下接入的是ST25DV，往一边拨接入中间开孔的一个UID芯片，断开ST25DV，另一边一样，相当于一个线圈天线给多个芯片做天线用
波轮开关的原理图可以参考这个厂家的介绍：http://www.jian-fu.com/product/content?id=664

yelvlab, 2020-07-01:
嗯，大致明白了，之前不了解要有UID芯片

Closed 2020-07-01.

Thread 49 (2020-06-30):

求助帖

jimianjun, 2020-06-30:
谁那有购买过的商铺的吗？我是个纯小白，元件都没接触过，谁可以指导下我吗，我无从下手啊，目前外壳和屏幕购买了，板子制作，元件购买，遇到了重重阻碍，可以联系下我不，wx就是用户名，求加

lewin0301, 2020-06-30:
电子元件淘宝买啊

jimianjun, 2020-06-30:
> 电子元件淘宝买啊

我知道呀，太难了，要么没有，要么不确定，可以教我走下路不，你搞成了没，教下我吧

lewin0301, 2020-06-30:
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

我也是小白，我是按照bom表挨个搜的

jimianjun, 2020-06-30:
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

然后呢，都到了吗？商家没疑问什么吗？你是搞回来自己贴片？

lewin0301, 2020-06-30:
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

我加你微信了，我是才买的电子元件，今天刚打的板

liangling11411, 2020-06-30:
> 谁那有购买过的商铺的吗？我是个纯小白，元件都没接触过，谁可以指导下我吗，我无从下手啊，目前外壳和屏幕购买了，板子制作，元件购买，遇到了重重矛盾，可以联系下我不，wx就是用户名，求加
可以去tb搜一下配单的商家，你直接把bom表发给客服就行了，如果有元件不知道型号可以看看以前的issue，如果客服说没有哪个元件（比如那个st25dv）就自己买，很简单的

jimianjun, 2020-06-30:
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

那你这还新手啊

jimianjun, 2020-06-30:
> > 谁那有购买过的商铺的吗？我是个纯小白，元件都没接触过，谁可以指导下我吗，我无从下手啊，目前外壳和屏幕购买了，板子制作，元件购买，遇到了重重矛盾，可以联系下我不，wx就是用户名，求加
> > 可以去tb搜一下配单的商家，你直接把bom表发给客服就行了，如果有元件不知道型号可以看看以前的问题，如果客服说没有这个元素（某些那个st25dv）就自己买，很简单的

元件应该没问题能凑全，回来自己贴片不会哈，还有后续的写固件，还有用什么数据线连板子，想学习无从下手，😭

liangling11411, 2020-06-30:
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

可以去嘉立创开个钢网，也不复杂（就是有点小贵）写固件可以看看https://github.com/peng-zhihui/L-ink_Card/issues/30 和 https://github.com/peng-zhihui/L-ink_Card/issues/6

Blueanr, 2020-06-30:
？？？纯小白买回来了会焊？？0402都没米粒大你有风枪吗？？

liangling11411, 2020-06-30:
> ？？？纯小白买回来了会焊？？0402都没米粒大你有风枪吗？？

啊这，也是（虽然我有）

lewin0301, 2020-06-30:
> ？？？纯小白买回来了会焊？？0402都没米粒大你有风枪吗？？

我公司有啊

TaXue-DuBa, 2020-07-03:
> 谁那有购买过的商铺的吗？我是个纯小白，元件都没接触过，谁可以指导下我吗，我无从下手啊，目前外壳和屏幕购买了，板子制作，元件购买，遇到了重重阻碍，可以联系下我不，wx就是用户名，求加

板子制作去嘉立创，每个月两次，每次5元5块，元器件可以立创商城或者淘宝

BH6AOV, 2020-07-03:
<a href="https://github.com/peng-zhihui/L-ink_Card/issues/45#issuecomment-653030940">我在立创商城的购买清单都在这了</a>，另外提一句，建议CR2032去1688买，比商城里便宜

lvshuy, 2020-07-09:
> [我在立创商城的购买清单都在这了](https://github.com/peng-zhihui/L-ink_Card/issues/45#issuecomment-653030940)，另外提一句，建议CR2032去1688买，比商城里便宜

感谢感谢，很详细了~

467815891a, 2020-07-20:
某宝有卖成品的呀，你这也太小白了

whthend, 2020-08-01:
为啥要手动焊接呢？嘉立创不是有smt贴片的选项嘛？

TaXue-DuBa, 2020-08-06:
> 为啥要手动焊接呢？嘉立创不是有smt贴片的选项嘛？

。。贵啊，而且未必所有原件都有SMT啊，有些东西还是要自己贴的

dorlolo, 2020-10-13:
我外壳在淘宝订的带挂孔版本，买了两套。店铺老板给了我半价50元（无喷漆纯白色）。感觉老板人不错，帮老板留个微信q2576695321，加她好友也给半价优惠（声明：最后请从淘宝下单，毕竟网上认识的，不要直接汇款）。

另外问一下 2520-L 68uH和6引脚拨动开关哪家店铺都有货的？我不想多花邮费，最好一家店铺购买。预算一直在蹭蹭蹭网上涨。。

huajianmao, 2020-10-19:
https://item.taobao.com/item.htm?spm=a230r.1.14.1.40c422f1amQmIO&id=623134077131&ns=1&abbucket=11#detail

JH0220, 2022-04-30:
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

您好 想请教一下 嘉立创打板这个尺寸是多少啊

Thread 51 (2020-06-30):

关于L1 2520 68uh电感问题

asdsartfg, 2020-06-30:
找边全网都没有2520磁珠68uh电感，0.68uh的到是有，请问你们是怎么解决的？

im12, 2020-06-30:
把磁珠去了找吧，2520是绕线电感的规格，磁珠可能没这么大的

asdsartfg, 2020-06-30:
> 把磁珠去了找吧，2520是绕线电感的规格，磁珠可能没这么大的

问题是，绕线和磁珠不是同一个东西啊

im12, 2020-07-01:
这个设计中都是作电感用的

peng-zhihui, 2020-07-01:
https://detail.tmall.com/item.htm?id=35828958171 我是用这个

Closed 2020-07-01.

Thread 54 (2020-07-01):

小伙伴们，来组队一起做啊

xiaoyun-TaiChi, 2020-07-01:
咱么可以组个队。，大多数元器件都无法单独购买。每个人也不都擅长硬件焊接
我们可以分工嘛，有兴趣的可以加群144538834，加群问题，

加群目的=DIY

jiangyou233, 2020-07-01:
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
为啥要弄个加群问题啊 简直多此一举 根本加不进去

Skywatch2019, 2020-07-03:
楼上的群根本进不去，大家进这个群：983599608  一起来研究吧

iwtywai, 2020-07-03:
输大写“DIY”不就是了嘛

xiaoyun-TaiChi, 2020-07-03:
> 楼上的群根本进不去，大家进这个群：983599608一起来研究吧

大写的DIY是不会输入吗？进个群咋都进不来

xiaoyun-TaiChi, 2020-07-03:
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

大写**DIY**

Skywatch2019, 2020-07-03:
群主不通过  不是我不会输入好么。。。

Closed 2020-07-18.

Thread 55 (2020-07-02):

关于墨水屏和图纸

BH6AOV, 2020-07-02:
请问墨水屏买三色的是不是也可以用？
在微雪官网发现墨水屏有<a href="http://www.waveshare.net/shop/1.54inch-e-Paper.htm">黑白的</a>和<a href="http://www.waveshare.net/shop/1.54inch-e-Paper-B.htm">红黑白三色的</a>两种，而且价格差的并不多，考虑到以后可能的彩色墨水屏兼容我想直接买红黑白三色的，但是不知道能不能用，希望可以解答一下
关联问题 #15

还有请问方不方便提供一下有元件编号的图纸，焊元件的时候对应不上元件位置有点难受，SchDoc看太不懂（悲）

liangling11411, 2020-07-03:
第一版不能用彩色墨水屏，因为驱动不一样
元件编号的图纸可以加一下qq群：144538834，（加群问题：加群目的=DIY）里面有大佬画出来了

Closed 2020-07-13.

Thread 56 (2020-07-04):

l-link_card，ic卡问题

jimianjun, 2020-07-04:
pcb板子上挖的那两个洞是做什么用的，st25d芯片可以直接模拟ic卡吗？还是需要在那两个洞里面添加两个ic芯片吗？可以添加几张卡进里面？有人懂吗？问了好几个人都不知道

iwtywai, 2020-07-04:
目前up的版本是添加两张卡，是由与st25dv共用天线的ic芯片实现的，这两个洞的确要加芯片才行，不直接模拟的原因是一个是iso15693，一个是iso14443，标准不同，下次发issue记得先看之前的

jimianjun, 2020-07-04:
> 目前up的版本是添加两张卡，是由与st25dv共用天线的ic芯片实现的，这两个洞的确要加芯片才行，不直接模拟的原因是一个是iso15693，一个是iso14443，标准不同，下次发issue记得先看之前的

我理解是这样的，st25dv的作用是跟手机nfc传输图像显示在显示屏上面是吗？那是他、25dv的储存大小，04k，16k，64k，这大小有什么用呢？那两个洞放的就是普通门禁卡里面的那芯片吗？可以uid，cuid，这种芯片？你说的iso 15693，14443，两种协议是什么意思，st25支持两种协议，还是洞支持一个15693一个14443，还是芯片协议随便放只要不是ID，我是小白啊，麻烦你了

iwtywai, 2020-07-04:
st25dv在整个板子上应该就是传输数据的，容量大小我没太明白，up说选哪种都行。那两个洞放的就是普通门禁卡里面的那芯片，可以uid，cuid。iso 15693是25dv的协议，14443是uid芯片的，两种协议不一样，所以不能直接只用25dv。

jimianjun, 2020-07-04:
> st25dv在整个板子上应该就是传输数据的，容量大小我没太明白，up说选哪种都行。那两个洞放的就是普通门禁卡里面的那芯片，可以uid，cuid。iso 15693是25dv的协议，14443是uid芯片的，两种协议不一样，所以不能直接只用25dv。

懂了，就是这card是用的st25dv芯片，只能传输 15693的协议，也只能添加两个15693芯片的uid卡，cuid卡，普通s50卡，可不可以直接用这个芯片生成 模拟15693协议的门禁卡，就跟手机一样，可以随便生成几张门禁卡，手机的限制就是卡号不可更改，直接用芯片生成模拟卡

iwtywai, 2020-07-04:
> > st25dv在整个板子上应该就是传输数据的，容量大小我没太明白，up说选哪种都行。那两个洞放的就是普通门禁卡里面的那芯片，可以uid，cuid。iso 15693是25dv的协议，14443是uid芯片的，两种协议不一样，所以不能直接只用25dv。
>
> 懂了，就是这card是用的st25dv芯片，只能传输 15693的协议，也只能添加两个15693芯片的uid卡，cuid卡，普通s50卡，可不可以直接用这个芯片生成 模拟15693协议的门禁卡，就跟手机一样，可以随便生成几张门禁卡，手机的限制就是卡号不可更改，直接用芯片生成模拟卡

还不是，那uid芯片是14443，和正常卡一样把卡信息刷进去，直接拿读写器。至于要拿25dv模拟15693，我不确定行不行，还没看过文档，up只是用了个25dv的功能。这和手机的随便生成还是不一样的，这个设备目前只能在两张卡之间切换，多张卡+直接模拟还要等up出第二版。

jimianjun, 2020-07-04:
懂了懂了

jimianjun, 2020-07-04:
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

st25d芯片和ic卡芯片其实是独立的，只是共用了一个天线而已，所有14443和15693其实都可以，只要你的读卡器支持对吧，拨轮开关的作用就是两张卡之间切换而已

iwtywai, 2020-07-04:
对，但我不知道15693的芯片能不能用，up用的14443，我个人觉得可以

guanzi008, 2020-07-23:
有没有成品做出来的，我现在一头雾水。
有没有愿意出售成品的我的wx是odatacc

feichaijiemi, 2020-07-23:
进群：144538834

------------------&nbsp;原始邮件&nbsp;------------------
发件人:                                                                                                                        "peng-zhihui/L-ink_Card"                                                                                    <notifications@github.com&gt;;
发送时间:&nbsp;2020年7月24日(星期五) 凌晨0:38
收件人:&nbsp;"peng-zhihui/L-ink_Card"<L-ink_Card@noreply.github.com&gt;;
抄送:&nbsp;"Subscribed"<subscribed@noreply.github.com&gt;;
主题:&nbsp;Re: [peng-zhihui/L-ink_Card] l-link_card，ic卡问题 (#56)

有没有成品做出来的，我现在一头雾水。
 有没有愿意出售成品的我的wx是odatacc

—
You are receiving this because you are subscribed to this thread.
Reply to this email directly, view it on GitHub, or unsubscribe.

XiaobaoAlex, 2020-08-18:
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

我理解是这样，25dv只是用来接收手机传来的的信息的，接收的信息在墨水屏上显示，25dv通过拨盘和两个uid芯片共用天线,实际上如果只是需要门禁功能，只要两个uid芯片和天线就行了，是这样嘛？

iwtywai, 2020-08-18:
是的，我也试了一下，只装上nfc芯片然后用跳线连接贴片拨轮的焊盘是可以使用的

syf2005, 2022-04-12:
交通一卡通大概率是CPU模拟卡，基本不可能破解写入uid卡片

---- 在 星期四, 2022-04-07 17:33:24 张瑞鑫 ***@***.***> 写到 ----

是的，我也试了一下，只装上nfc芯片然后用跳线连接贴片拨轮的焊盘是可以使用的
 uid芯片怎么写入其他卡片的信息呢？只用两个uid芯片模拟两个卡片，比如说模拟我的交通一卡通。怎么用两个小uid芯片模拟自己的交通一卡通。

—
Reply to this email directly, https://github.com/peng-zhihui/L-ink_Card/issues/56#issuecomment-1091427127, or https://github.com/notifications/unsubscribe-auth/AM5PBUC6SH3HPJWTUKAABVTVD2TWJANCNFSM4OQGTYLQ.
You are receiving this because you are subscribed to this thread.

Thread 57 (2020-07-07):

关于安卓APP

boxlab, 2020-07-07:
请问您有考虑过将安卓APP开源么？希望有机会观摩学习一下

TaXue-DuBa, 2020-07-08:
> 请问您有考虑过将安卓APP开源么？希望有机会观摩学习一下

不是说那个APP是他们公司的APP吗

cy6909, 2020-07-08:
想问问为啥我手机用不了这个app呀

peng-zhihui, 2020-07-08:
这个APP是我做的哈，不过因为有用在公司的项目里面，所以原APP不太好开源，但是我后面会封装好另外一个Sample工程发出来的

ruinanzhu, 2020-07-08:
> 这个APP是我做的哈，不过因为有用在公司的项目里面，所以原APP不太好开源，但是我后面会封装好另外一个Sample工程发出来的

大佬，能不能给个联系方式，我们众筹凑单批量了一些，想寄给你一个我们做的，我们做了一点点优化

Closed 2020-07-08.

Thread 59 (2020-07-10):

Keil 5程序刷入问题 与 IC_0 IC_1 具体型号问题

huajijam, 2020-07-10:
下载器：Jlink OB 系统:win10 2004
Jlink OB驱动，stm32L0 前置已下
直接打开"%Project%\Firmware\Keil\L-ink_Card\MDK-ARM\L-ink_Card.uvprojx"点击Flash时报错
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

huajijam, 2020-07-10:
另 在选购背部IC_0 IC_1时不知如何选择，有成品的大佬劳烦给个建议

peng-zhihui, 2020-07-18:
1. 先成功编译一遍工程
2. 直接tb搜索UID芯片，有很多

Closed 2020-07-18.

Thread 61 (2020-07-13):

BOM表里面的LDO的疑问

dremofly, 2020-07-13:
BOM的excel文件里面有一个叫做WHEEL_SWITCH的LDO，但是我在原理图和PCB里面似乎都没有见到元件。烦请有经验的大佬指点一下。

doublemarkpro, 2020-07-14:
那是波轮开关，详见 #21
并不是叫Switch的都是LDO……八杆子打不着

dremofly, 2020-07-14:
> 那是波轮开关，详见 #21
> 并不是叫Switch的都是LDO……八杆子打不着

明白了，原来是拨轮开关啊。我就说都有DC-DC converter了，怎么还需要LDO

Closed 2020-07-18.

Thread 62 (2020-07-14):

关于背部IC01 IC02的问题

Fir-Geek, 2020-07-14:
## 关于背部IC01 IC02的问题
不太懂他们俩的意义是什么
看到有个issue里面提到这句话 对此十分不解
> 背部的两个IC就是门禁卡内部的IC
---
想问一下 **他们俩存在的意义是什么？** 我记得up在视频里提到 L-ink是可以**复制**加密卡的 既然可以复制 何必再装这两个IC呢？
#### 在此先谢过 感激不尽！

Blueanr, 2020-07-14:
不是复制啊，这个项目就相当于用一个开关切换两张不同卡片，卡片的数据需要你读取出来并自己写入内部的芯片中...其实有点鸡肋

Fir-Geek, 2020-07-14:
了解了 感谢@Blueanr 的解答
#### 还有一个问题
up在PCB文件中指出，**应该把中间IC的两个槽挖空**，但是我看up**视频中的PCB并没有挖空**
#### 这个何解呢

peng-zhihui, 2020-07-18:
看readme说明，这一版的设计是这样的；挖空不挖空都可以，因为芯片很薄不影响。

Fir-Geek, 2020-07-20:
了解了，感谢@peng-zhihui 大佬解答！

Closed 2020-07-18.

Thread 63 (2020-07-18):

关于PCB天线的问题

stig3, 2020-07-18:
按照设计，中间两个IC位置因该是留给自行购买UID芯片焊接上去，然后自己复制IC卡用的
所以，哪怕只焊接这两个IC加一个开关应该也可以使用门禁功能，是这样吧？

另外，看视频的时候，似乎这个天线是针对IC卡13.5MHz频率设计的
那如果我这里焊上两个125K的ID芯片，不知道能不能用？
据我所知，ID卡和IC卡的线圈是不一样的。
有没有人试过？

peng-zhihui, 2020-07-18:
1. 是的，这一版是可以的，下一版会改用别的方式实现
2. 天线不一样，ID卡线圈密很多，一般很少用PCB天线做，有兴趣的话可以自己留个焊盘焊个天线上去即可，跟IC卡的PCB线圈不冲突。

Closed 2020-07-18.

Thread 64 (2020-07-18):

生成Hex报错

BH6AOV, 2020-07-18:
Keil5生成Hex时报错了，报错如下
```
Rebuild started: Project: L-ink_Card
*** Using Compiler 'V5.06 update 6 (build 750)', folder: 'C:\Keil_v5\armkeil\ARM\ARMCC\Bin'
Rebuild target 'L-ink_Card'
assembling startup_stm32l051xx.s...
startup_stm32l051xx.s: Error: A9555E: Failed to check out a license.LICENSE ERROR (R207(2): REGISTRY READ ERROR)
startup_stm32l051xx.s:
startup_stm32l051xx.s: Check that your license details are correct in the License Management dialog of MDK. Additional information is available at:
startup_stm32l051xx.s:  http://www.keil.com/support/man/docs/license/license_management.htm
startup_stm32l051xx.s:  If you need further help, provide this complete error report to your supplier or license.support@arm.com.
startup_stm32l051xx.s:  - ARMLMD_LICENSE_FILE: unset
startup_stm32l051xx.s:  - LM_LICENSE_FILE: unset
startup_stm32l051xx.s:  - ARM_TOOL_VARIANT: unset
startup_stm32l051xx.s:  - ARM_PRODUCT_PATH: unset
startup_stm32l051xx.s:  - Product location: C:\Keil_v5\armkeil\ARM\sw\mappings
startup_stm32l051xx.s:  - Toolchain location: C:\Keil_v5\armkeil\ARM\ARMCC\Bin
startup_stm32l051xx.s:  - Selected tool variant: mdk_std
startup_stm32l051xx.s:  - Checkout feature: LIC0=KA...-.....-.....
startup_stm32l051xx.s:  - Feature version: 5.0201709
startup_stm32l051xx.s:  - Keil error code: 1
startup_stm32l051xx.s: Product: MDK Plus 5.31
startup_stm32l051xx.s: Component: ARM Compiler 5.06 update 6 (build 750)
startup_stm32l051xx.s: Tool: ArmAsm [4d35ec]
compiling main.c...
Error: C9555E: Failed to check out a license.LICENSE ERROR (R207(2): REGISTRY READ ERROR)
Check that your license details are correct in the License Management dialog of MDK. Additional information is available at:
 http://www.keil.com/support/man/docs/license/license_management.htm
 If you need further help, provide this complete error report to your supplier or license.support@arm.com.
 - ARMLMD_LICENSE_FILE: unset
 - LM_LICENSE_FILE: unset
 - ARM_TOOL_VARIANT: unset
 - ARM_PRODUCT_PATH: unset
 - Product location: C:\Keil_v5\armkeil\ARM\sw\mappings
 - Toolchain location: C:\Keil_v5\armkeil\ARM\ARMCC\Bin
 - Selected tool variant: mdk_std
 - Checkout feature: LIC0=KA...-.....-.....
 - Feature version: 5.0201709
 - Keil error code: 1
Product: MDK Plus 5.31
Component: ARM Compiler 5.06 update 6 (build 750)
Tool: ArmCC [4d3637]
compiling gpio.c...
Error: C9555E: Failed to check out a license.LICENSE ERROR (R207(2): REGISTRY READ ERROR)
Check that your license details are correct in the License Management dialog of MDK. Additional information is available at:
 http://www.keil.com/support/man/docs/license/license_management.htm
 If you need further help, provide this complete error report to your supplier or license.support@arm.com.
 - ARMLMD_LICENSE_FILE: unset
 - LM_LICENSE_FILE: unset
 - ARM_TOOL_VARIANT: unset
 - ARM_PRODUCT_PATH: unset
 - Product location: C:\Keil_v5\armkeil\ARM\sw\mappings
 - Toolchain location: C:\Keil_v5\armkeil\ARM\ARMCC\Bin
 - Selected tool variant: mdk_std
 - Checkout feature: LIC0=KA...-.....-.....
 - Feature version: 5.0201709
 - Keil error code: 1
Product: MDK Plus 5.31
Component: ARM Compiler 5.06 update 6 (build 750)
Tool: ArmCC [4d3637]
compiling usart.c...
Error: C9555E: Failed to check out a license.LICENSE ERROR (R207(2): REGISTRY READ ERROR)
Check that your license details are correct in the License Management dialog of MDK. Additional information is available at:
 http://www.keil.com/support/man/docs/license/license_management.htm
 If you need further help, provide this complete error report to your supplier or license.support@arm.com.
 - ARMLMD_LICENSE_FILE: unset
 - LM_LICENSE_FILE: unset
 - ARM_TOOL_VARIANT: unset
 - ARM_PRODUCT_PATH: unset
 - Product location: C:\Keil_v5\armkeil\ARM\sw\mappings
 - Toolchain location: C:\Keil_v5\armkeil\ARM\ARMCC\Bin
 - Selected tool variant: mdk_std
 - Checkout feature: LIC0=KA...-.....-.....
 - Feature version: 5.0201709
 - Keil error code: 1
Product: MDK Plus 5.31
Component: ARM Compiler 5.06 update 6 (build 750)
Tool: ArmCC [4d3637]
compiling stm32l0xx_it.c...
Error: C9555E: Failed to check out a license.LICENSE ERROR (R207(2): REGISTRY READ ERROR)
Check that your license details are correct in the License Management dialog of MDK. Additional information is available at:
 http://www.keil.com/support/man/docs/license/license_management.htm
 If you need further help, provide this complete error report to your supplier or license.support@arm.com.
 - ARMLMD_LICENSE_FILE: unset
 - LM_LICENSE_FILE: unset
 - ARM_TOOL_VARIANT: unset
 - ARM_PRODUCT_PATH: unset
 - Product location: C:\Keil_v5\armkeil\ARM\sw\mappings
 - Toolchain location: C:\Keil_v5\armkeil\ARM\ARMCC\Bin
 - Selected tool variant: mdk_std
 - Checkout feature: LIC0=KA...-.....-.....
 - Feature version: 5.0201709
 - Keil error code: 1
Product: MDK Plus 5.31
Component: ARM Compiler 5.06 update 6 (build 750)
Tool: ArmCC [4d3637]
compiling stm32l0xx_hal_msp.c...
Error: C9555E: Failed to check out a license.LICENSE ERROR (R207(2): REGISTRY READ ERROR)
Check that your license details are correct in the License Management dialog of MDK. Additional information is available at:
 http://www.keil.com/support/man/docs/license/license_management.htm
 If you need further help, provide this complete error report to your supplier or license.support@arm.com.
 - ARMLMD_LICENSE_FILE: unset
 - LM_LICENSE_FILE: unset
 - ARM_TOOL_VARIANT: unset
 - ARM_PRODUCT_PATH: unset
 - Product location: C:\Keil_v5\armkeil\ARM\sw\mappings
 - Toolchain location: C:\Keil_v5\armkeil\ARM\ARMCC\Bin
 - Selected tool variant: mdk_std
 - Checkout feature: LIC0=KA...-.....-.....
 - Feature version: 5.0201709
 - Keil error code: 1
Product: MDK Plus 5.31
Component: ARM Compiler 5.06 update 6 (build 750)
Tool: ArmCC [4d3637]
compiling epd_w21.c...
Error: C9555E: Failed to check out a license.LICENSE ERROR (R207(2): REGISTRY READ ERROR)
Check that your license details are correct in the License Management dialog of MDK. Additional information is available at:
 http://www.keil.com/support/man/docs/license/license_management.htm
 If you need further help, provide this complete error report to your supplier or license.support@arm.com.
 - ARMLMD_LICENSE_FILE: unset
 - LM_LICENSE_FILE: unset
 - ARM_TOOL_VARIANT: unset
 - ARM_PRODUCT_PATH: unset
 - Product location: C:\Keil_v5\armkeil\ARM\sw\mappings
 - Toolchain location: C:\Keil_v5\armkeil\ARM\ARMCC\Bin
 - Selected tool variant: mdk_std
 - Checkout feature: LIC0=KA...-.....-.....
 - Feature version: 5.0201709
 - Keil error code: 1
Product: MDK Plus 5.31
Component: ARM Compiler 5.06 update 6 (build 750)
Tool: ArmCC [4d3637]
compiling app_nfc.c...
Error: C9555E: Failed to check out a license.LICENSE ERROR (R207(2): REGISTRY READ ERROR)
Check that your license details are correct in the License Management dialog of MDK. Additional information is available at:
 http://www.keil.com/support/man/docs/license/license_management.htm
 If you need further help, provide this complete error report to your supplier or license.support@arm.com.
 - ARMLMD_LICENSE_FILE: unset
 - LM_LICENSE_FILE: unset
 - ARM_TOOL_VARIANT: unset
 - ARM_PRODUCT_PATH: unset
 - Product location: C:\Keil_v5\armkeil\ARM\sw\mappings
 - Toolchain location: C:\Keil_v5\armkeil\ARM\ARMCC\Bin
 - Selected tool variant: mdk_std
 - Checkout feature: LIC0=KA...-.....-.....
 - Feature version: 5.0201709
 - Keil error code: 1
Product: MDK Plus 5.31
Component: ARM Compiler 5.06 update 6 (build 750)
Tool: ArmCC [4d3637]
compiling stm32l0xx_hal_exti.c...
Error: C9555E: Failed to check out a license.LICENSE ERROR (R207(2): REGISTRY READ ERROR)
Check that your license details are correct in the License Management dialog of MDK. Additional information is available at:
 http://www.keil.com/support/man/docs/license/license_management.htm
 If you need further help, provide this complete error report to your supplier or license.support@arm.com.
 - ARMLMD_LICENSE_FILE: unset
 - LM_LICENSE_FILE: unset
 - ARM_TOOL_VARIANT: unset
 - ARM_PRODUCT_PATH: unset
 - Product location: C:\Keil_v5\armkeil\ARM\sw\mappings
 - Toolchain location: C:\Keil_v5\armkeil\ARM\ARMCC\Bin
 - Selected tool variant: mdk_std
 - Checkout feature: LIC0=KA...-.....-.....
 - Feature version: 5.0201709
 - Keil error code: 1
Product: MDK Plus 5.31
Component: ARM Compiler 5.06 update 6 (build 750)
Tool: ArmCC [4d3637]
compiling custom_bus.c...
Error: C9555E: Failed to check out a license.LICENSE ERROR (R207(2): REGISTRY READ ERROR)
Check that your license details are correct in the License Management dialog of MDK. Additional information is available at:
 http://www.keil.com/support/man/docs/license/license_management.htm
 If you need further help, provide this complete error report to your supplier or license.support@arm.com.
 - ARMLMD_LICENSE_FILE: unset
 - LM_LICENSE_FILE: unset
 - ARM_TOOL_VARIANT: unset
 - ARM_PRODUCT_PATH: unset
 - Product location: C:\Keil_v5\armkeil\ARM\sw\mappings
 - Toolchain location: C:\Keil_v5\armkeil\ARM\ARMCC\Bin
 - Selected tool variant: mdk_std
 - Checkout feature: LIC0=KA...-.....-.....
 - Feature version: 5.0201709
 - Keil error code: 1
Product: MDK Plus 5.31
Component: ARM Compiler 5.06 update 6 (build 750)
Tool: ArmCC [4d3637]
compiling st25dv_reg.c...
Error: C9555E: Failed to check out a license.LICENSE ERROR (R207(2): REGISTRY READ ERROR)
Check that your license details are correct in the License Management dialog of MDK. Additional information is available at:
 http://www.keil.com/support/man/docs/license/license_management.htm
 If you need further help, provide this complete error report to your supplier or license.support@arm.com.
 - ARMLMD_LICENSE_FILE: unset
 - LM_LICENSE_FILE: unset
 - ARM_TOOL_VARIANT: unset
 - ARM_PRODUCT_PATH: unset
 - Product location: C:\Keil_v5\armkeil\ARM\sw\mappings
 - Toolchain location: C:\Keil_v5\armkeil\ARM\ARMCC\Bin
 - Selected tool variant: mdk_std
 - Checkout feature: LIC0=KA...-.....-.....
 - Feature version: 5.0201709
 - Keil error code: 1
Product: MDK Plus 5.31
Component: ARM Compiler 5.06 update 6 (build 750)
Tool: ArmCC [4d3637]
compiling st25dv.c...
Error: C9555E: Failed to check out a license.LICENSE ERROR (R207(2): REGISTRY READ ERROR)
Check that your license details are correct in the License Management dialog of MDK. Additional information is available at:
 http://www.keil.com/support/man/docs/license/license_management.htm
 If you need further help, provide this complete error report to your supplier or license.support@arm.com.
 - ARMLMD_LICENSE_FILE: unset
 - LM_LICENSE_FILE: unset
 - ARM_TOOL_VARIANT: unset
 - ARM_PRODUCT_PATH: unset
 - Product location: C:\Keil_v5\armkeil\ARM\sw\mappings
 - Toolchain location: C:\Keil_v5\armkeil\ARM\ARMCC\Bin
 - Selected tool variant: mdk_std
 - Checkout feature: LIC0=KA...-.....-.....
 - Feature version: 5.0201709
 - Keil error code: 1
Product: MDK Plus 5.31
Component: ARM Compiler 5.06 update 6 (build 750)
Tool: ArmCC [4d3637]
compiling nfc04a1.c...
Error: C9555E: Failed to check out a license.LICENSE ERROR (R207(2): REGISTRY READ ERROR)
Check that your license details are correct in the License Management dialog of MDK. Additional information is available at:
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
iwtywai, 2020-07-18:
它说是读不了注册表，看看能不能管理员模式运行，或者重新安装、注册一下软件

BH6AOV, 2020-07-18:
> 它说是读不了注册表，看看能不能管理员模式运行，或者重新安装、注册一下软件

了解了，我试一下管理员模式

BH6AOV, 2020-07-18:
> 它说是读不了注册表，看看能不能管理员模式运行，或者重新安装、注册一下软件

并没有什么区别。。。软件前几天才装的最新版，也是才注册的。。。不应该啊

peng-zhihui, 2020-07-18:
keil的license到期了，需要重新激活，激活需要在管理员模式下进行。

BH6AOV, 2020-07-18:
> keil的license到期了，需要重新激活，激活需要在管理员模式下进行。

看了下我激活的那个证书写的到2024年11月才过期啊管理员模式装的，不过是注册机生成的

iwtywai, 2020-07-18:
我记得203几年的是没有问题的，找找看那个试试？

BH6AOV, 2020-07-18:
> 我记得203几年的是没有问题的，找找看那个试试？

我没有(﹁"﹁)方便给个链不

iwtywai, 2020-07-18:
没存...😭

BH6AOV, 2020-07-18:
> 没存...😭

😭我再找找

yelvlab, 2020-08-27:
> > 没存...😭
>
> 😭我再找找

https://blog.csdn.net/Mculover666/article/details/89469764
我重新装的531，好久没用过keil了，我用jlink烧了，安卓应用也提示正在传输图片，然后后续就没有任何反应了，头大

Closed 2025-01-20.

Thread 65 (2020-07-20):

关于DAP-LINK适用性问题

mumxi, 2020-07-20:
该烧录器是不是只能烧写STM32L0系列的芯片，STM32F7系列不能烧写，求大佬解答，如何更改程序

peng-zhihui, 2020-07-22:
适用于所有Cortex-M系列芯片，跟Jlink的使用是基本一样的，多了个虚拟 调试串口的功能，以及虚拟U盘拖拽烧录的功能（这个拖拽烧录是只能指定一个芯片的，我这个固件设置的是F103）

mumxi, 2020-07-23:
稚晖君你好，首先非常感谢您能抽时间答疑解惑，帮助我了解DAP-LINK的相关问题，其次还想问您如果想要指定其他芯片，固件应该怎么改动，万分希望您能指点一下。谢谢，祝您生活愉快，工作顺利！

------------------&nbsp;原始邮件&nbsp;------------------
发件人:                                                                                                                        "peng-zhihui/L-ink_Card"                                                                                    <notifications@github.com&gt;;
发送时间:&nbsp;2020年7月22日(星期三) 下午5:25
收件人:&nbsp;"peng-zhihui/L-ink_Card"<L-ink_Card@noreply.github.com&gt;;
抄送:&nbsp;"?哥脫ㄋ，你随意"<2530406776@qq.com&gt;;"Author"<author@noreply.github.com&gt;;
主题:&nbsp;Re: [peng-zhihui/L-ink_Card] 关于DAP-LINK适用性问题 (#65)

适用于所有Cortex-M系列芯片，跟Jlink的使用是基本一样的，多了个虚拟 调试串口的功能，以及虚拟U盘拖拽烧录的功能（这个拖拽烧录是只能指定一个芯片的，我这个固件设置的是F103）

—
You are receiving this because you authored the thread.
Reply to this email directly, view it on GitHub, or unsubscribe.

Closed 2020-07-22.

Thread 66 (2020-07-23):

传输问题

TopRookie, 2020-07-23:
你好，up 可以大概描述下 数据是怎么从手机传输过去的么。通过什么技术呢

iwtywai, 2020-07-23:
用的是25dv的mailbox功能

TopRookie, 2020-07-23:
你好 麻烦可以丢些相关连接看下么，刚刚搜了下 maibox好像是邮箱不知道是不是我搜错了，但我看你文档和视频 好像是和NFC 有关

------------------&nbsp;原始邮件&nbsp;------------------
发件人: "iwtywai"<notifications@github.com&gt;;
发送时间: 2020年7月23日(星期四) 上午10:24
收件人: "peng-zhihui/L-ink_Card"<L-ink_Card@noreply.github.com&gt;;
抄送: "wo+"<564528143@qq.com&gt;; "Author"<author@noreply.github.com&gt;;
主题: Re: [peng-zhihui/L-ink_Card] 传输问题 (#66)

 用的是25dv的mailbox功能
—
You are receiving this because you authored the thread.
Reply to this email directly, view it on GitHub, or unsubscribe.

iwtywai, 2020-07-23:
mailbox就是个缓冲区，和手机通讯的数据会存进去，up程序中的st25dv mailbox process就是处理它的

TopRookie, 2020-07-23:
好的 谢谢 后边搜出来点东西了 &nbsp;

------------------&nbsp;原始邮件&nbsp;------------------
发件人: "iwtywai"<notifications@github.com&gt;;
发送时间: 2020年7月23日(星期四) 上午10:42
收件人: "peng-zhihui/L-ink_Card"<L-ink_Card@noreply.github.com&gt;;
抄送: "wo+"<564528143@qq.com&gt;; "Author"<author@noreply.github.com&gt;;
主题: Re: [peng-zhihui/L-ink_Card] 传输问题 (#66)

 mailbox就是个缓冲区，和手机通讯的数据会存进去，up程序中的st25dv mailbox process就是处理它的
—
You are receiving this because you authored the thread.
Reply to this email directly, view it on GitHub, or unsubscribe.

Closed 2020-07-24.

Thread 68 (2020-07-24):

OLED屏需求

zzmzaizai, 2020-07-24:
UP UP UP 能不能加个分支，增加对OLED屏的支持呢？

stig3, 2020-07-25:
这本身是个低功耗项目，OLED的话，电池尺寸不可能小的
与当初的设想有冲突
如果真的需要，可以自己fork然后修改一版出来

Leonwenbin, 2020-07-29:
OLED功耗太大，那点电难顶

FLAVORED-YOGHURT, 2020-08-14:
水墨屏只有在更改显示内容的时候才会耗电，平时显示是不耗电的。一块纽扣电池无法支持OLED屏多久的。

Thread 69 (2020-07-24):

安卓工程似乎安装不了运行系统有要求吗？

DukeHouse, 2020-07-24:
对运行环境有要求吗？如题

Leonwenbin, 2020-07-29:
> 对运行环境有要求吗？如题
我装了试了一下，APP是可以用的。你问的问题读起来不是那么好理解，标点符号又不收费，哈哈。

DukeHouse, 2020-07-29:
抱歉，打字急了，我在安卓7.0和10.0上分别试过不可以运行显示包解析错误，很有可能是我操作有误，up是在什么版本测试的呢？非常感谢

Leonwenbin, 2020-07-30:
> 抱歉，打字急了，我在安卓7.0和10.0上分别试过不可以运行显示包解析错误，很有可能是我操作有误，up是在什么版本测试的呢？非常感谢

我是andriod10.0

DukeHouse, 2020-07-30:
好的，谢谢稚辉君，今天在小伙伴的手机上安装起来了，Android studio的模拟器貌似不太聪明的样子

Leonwenbin, 2020-07-30:
> 好的，谢谢稚辉君，今天在小伙伴的手机上安装起来了，Android studio的模拟器貌似不太聪明的样子

哥们，俺不是稚晖君，俺也是粉丝哈哈哈

DukeHouse, 2020-07-30:
头像认错了居然，大型误会现场，抱歉抱歉

xseruer, 2020-08-06:
包解析错误，大概率是下载的文件不完整（以前手机浏览器下载apk老报这个错），建议用电脑下载 用adb install 安装。
注意：首次启动需要授权，否则会蹦掉。

Closed 2022-03-12.

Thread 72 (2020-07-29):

有没有人试过用Pn532和stm32通信

Ashe233, 2020-07-29:
如果能行不就可以用电脑传图了嘛

TaohongMaxwell, 2020-08-05:
理论上可以，只要两边协议相同（说人话就是两者串通好了），什么平台都可以互传数据。
解决方案是编程，使二者发送和接收的频率相同，在程序里安排好就行了。但目测开发工程量较大。

本人是通信学院的学生，舍友上学期做的课设就是无线传输的。

DWtiangu, 2020-08-31:
这个问题不大，PN532支持IIC以及ISP，你可以选择其中的一种接口，然后写好驱动就可以实现信息传输了

Yinke7, 2021-03-09:
完全可以啊，网上有PN532的各种demo，包括raspberry ，stm32，arduino 连接：https://github.com/Yinke7/PN532

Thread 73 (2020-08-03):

这套可以复制公交卡吗

Pig-Brother, 2020-08-03:

Blueanr, 2020-08-03:
不可以，但是你可以把你手上公车卡的芯片抠出来放进去

TaohongMaxwell, 2020-08-05:
理论上可以强行复制，但不一定能正常使用，风险很大，不建议复制公交卡。

Queeneren, 2020-08-29:
手机都可以用nfc坐公交，为啥这个不行呢？麻烦具体说说

Blueanr, 2020-08-29:
> 手机都可以用nfc坐公交，为啥这个不行呢？麻烦具体说说
这世上哪有这么多为什么不为什么的，这个项目就没有复制、克隆的功能！！不能复制！不能克隆！
这个项目就只是单纯的用一个开关切换两张卡片，两张m1卡的内容都还是通过其他外设读出key之后再写进去的！！屏幕、和手机的通信什么的只是锦上添花可有可无的功能，没有模拟卡的功能！！！
你要是真的非常非常非常非常想用这玩意儿刷公交，解决方案上面也给了，你把你公交卡的芯片扣出来焊在他的线圈上，你就能通过那个开关切换卡片！
到目前我还没听说过能破解CPU卡的，你用头来复制？

Closed 2020-09-04.

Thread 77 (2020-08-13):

编译时没有出错，但是下载时报错Error: Flash Download failed  -  "Cortex-M0+"。具体错误信息如下，用的j-link。谢谢各位

BrokenHalberd, 2020-08-13:
Erase Done.
***JLink Error: Can not read register 15 (R15) while CPU is running
**JLink Warning: CPU could not be halted
***JLink Error: Could not read memory location 0x20000000 when trying to clear soft RAM BP
***JLink Error: Can not read register 20 (CFBP) while CPU is running
**JLink Warning: CPU could not be halted
***JLink Error: CPU is not halted
***JLink Error: Can not read register 15 (R15) while CPU is running
**JLink Warning: CPU could not be halted
***JLink Error: Could not read memory location 0x20000000 when trying to clear soft RAM BP
Programming Failed!
Error: Flash Download failed  -  "Cortex-M0+"
***JLink Error: Could not read memory location 0x20000000 when trying to clear soft RAM BP
Flash Load finished at 15:00:39

Closed 2020-08-14.

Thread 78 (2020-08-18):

通过PM3读取到的原卡信息如何写入uid芯片中？

XiaobaoAlex, 2020-08-18:
大致了解到PM3可以破解原卡的信息，但是通过何种方式将这读取的信息写入uid芯片中呢，能否说得详细具体些，谢谢

iwtywai, 2020-08-18:
用有nfc烧写功能的设备都是可以的，例如可以使用pn532连接上位机操作烧写dump文件到卡，也可以用手机上的mifare classic tool

XiaobaoAlex, 2020-08-19:
> 用有nfc烧写功能的设备都是可以的，例如可以使用pn532连接上位机操作烧写dump文件到卡，也可以用手机上的mifare classic tool

请问烧写到芯片是要和天线连接后，也就是焊在板子上后再烧写嘛？如果是，那就是用拨盘来选择要烧写的芯片？

iwtywai, 2020-08-19:
是的

XiaobaoAlex, 2020-08-19:
> 是的

谢谢

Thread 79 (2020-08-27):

【求助】墨水屏没有一点点反应，不知该如何下手

yelvlab, 2020-08-27:
拖了几个月终于焊好了，然后装的531的keil，PJ到了2032年，成功用jlink烧录

```
Build started: Project: L-ink_Card
*** Using Compiler 'V5.06 update 6 (build 750)', folder: 'd:\Keil_v5\ARM\ARMCC\Bin'
Build target 'L-ink_Card'
"L-ink_Card\L-ink_Card.axf" - 0 Error(s), 0 Warning(s).
Build Time Elapsed:  00:00:00
Load "L-ink_Card\\L-ink_Card.axf"
Set JLink Project File to "D:\user\hulk\Desktop\Keil\L-ink_Card\MDK-ARM\JLinkSettings.ini"
* JLink Info: Device "STM32L051K8" selected.

JLink info:
------------
DLL: V6.70e, compiled Apr 17 2020 17:55:05
Firmware: J-Link ARM-OB STM32 compiled Aug 22 2012 19:52:04
Hardware: V7.00
S/N : 20140522
Feature(s) : RDI,FlashDL,FlashBP,JFlash,GDBFull

* JLink Info: Found SW-DP with ID 0x0BC11477
* JLink Info: Found SW-DP with ID 0x0BC11477
* JLink Info: Unknown DP version. Assuming DPv0
* JLink Info: Scanning AP map to find all available APs
* JLink Info: AP[1]: Stopped AP scan as end of AP map has been reached
* JLink Info: AP[0]: AHB-AP (IDR: 0x04770031)
* JLink Info: Iterating through AP map to find AHB-AP to use
* JLink Info: AP[0]: Core found
* JLink Info: AP[0]: AHB-AP ROM base: 0xF0000000
* JLink Info: CPUID register: 0x410CC601. Implementer code: 0x41 (ARM)
* JLink Info: Found Cortex-M0 r0p1, Little endian.
* JLink Info: FPUnit: 4 code (BP) slots and 0 literal slots
* JLink Info: CoreSight components:
* JLink Info: ROMTbl[0] @ F0000000
* JLink Info: ROMTbl[0][0]: E00FF000, CID: B105100D, PID: 000BB4C0 ROM Table
* JLink Info: ROMTbl[1] @ E00FF000
* JLink Info: ROMTbl[1][0]: E000E000, CID: B105E00D, PID: 000BB008 SCS
* JLink Info: ROMTbl[1][1]: E0001000, CID: B105E00D, PID: 000BB00A DWT
* JLink Info: ROMTbl[1][2]: E0002000, CID: B105E00D, PID: 000BB00B FPB
ROMTableAddr = 0xF0000000
* JLink Info: Reset: Halt core after reset via DEMCR.VC_CORERESET.
* JLink Info: Reset: Reset device via AIRCR.SYSRESETREQ.

Target info:
------------
Device: STM32L051K8Tx
VTarget = 3.300V
State of Pins:
TCK: 0, TDI: 0, TDO: 1, TMS: 0, TRES: 1, TRST: 1
Hardware-Breakpoints: 4
Software-Breakpoints: 8192
Watchpoints:          2
JTAG speed: 4000 kHz

Erase Done.
Programming Done.
Verify OK.
Flash Load finished at 17:40:05
```

然后我的墨水屏没有任何反应，LED也没有，代码一知半解的，看不太懂，不知道该如何下手，两个IC芯片已经没问题了，可以读写，然后ST25那个NFC芯片手机有反应，打开L-ink那个安卓应用，二值化、模糊处理和标签那些东西手机只会提示一个”正在传输图片，请不要拿走卡片“，我尝试了用纽扣电池加上按键，也尝试了烧录线供电，墨水屏和LED都是没有反应。我也不确定烧录好后的状态，是不是会刷一下屏幕。

如上所述，我该从哪里入手，或者有没有大佬给一份直接墨水屏亮屏的代码，LED我尝试凭借记忆写了一下，也没反应，我也不知道是我没写对还是芯片有问题(正常来说，keil的debugger里面的SWD可以识别，芯片应该是正常的)。

huajijam, 2020-08-27:
同无反应，已确定屏幕为V2 两块板子两块屏幕都测试过了，元件也测试过了，但我是能传输成功但是传输成功之后无显示

yelvlab, 2020-08-28:
> 同无反应，已确定屏幕为V2 两块板子两块屏幕都测试过了，元件也测试过了，但我是能传输成功但是传输成功之后无显示

我也是V2屏幕

yelvlab, 2020-08-28:
> 同无反应，已确定屏幕为V2 两块板子两块屏幕都测试过了，元件也测试过了，但我是能传输成功但是传输成功之后无显示

老哥，你的问题好了么，我的已经好了，用了另外一个大佬改过的代码，可能有些差异，不适配

huajijam, 2020-08-29:
> > 同无反应，已确定屏幕为V2 两块板子两块屏幕都测试过了，元件也测试过了，但我是能传输成功但是传输成功之后无显示
>
> 老哥，你的问题好了么，我的已经好了，用了另外一个大佬改过的代码，可能有些差异，不适配

哪个？给个链？

yelvlab, 2020-08-31:
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

老哥，加一下群，我没找到github地址，群里一位大佬的  144538834

Closed 2020-08-28.

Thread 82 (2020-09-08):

关于nfc写图功能

cdromcdrom, 2020-09-08:
做了link，写好了卡，发现了一个巨大的问题。
我没有nfc。。的手机。。。。
各位大佬们，有没有什么办法用pm532往link里面写图？
拜托了QAQ

Vandoul, 2020-09-15:
买个nfc模块

cdromcdrom, 2020-09-19:
不行啊。。。有模块我怎么发图？是电脑

lty13123, 2021-04-07:
老哥 我在做卡上有些问题 本科生电子小白  能不能加个联系方式跟你请教一下

cdromcdrom, 2022-07-22:
> 老哥 我在做卡上有些问题 本科生电子小白 能不能加个联系方式跟你请教一下

emmmmmmmmm你现在还需要吗

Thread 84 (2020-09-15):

彩色屏的硬件方案啥时候有？

Suaodiwang, 2020-09-15:

grander1, 2020-09-30:
彩屏太耗电了吧，不实用

12121-12121, 2021-01-26:
> 彩屏太耗电了吧，不实用

不耗电呀，彩色墨水屏不刷新的时候也不好电，就是刷新时耗电比黑白的多一点点，不过影响不大。

lryyddy, 2021-11-28:
鸽了

UNIONDONG, 2022-05-30:
> > 彩屏太耗电了吧，不实用
>
> 不耗电呀，彩色墨水屏不刷新的时候也不好电，就是刷新时耗电比黑白的多一点点，不过影响不大。

哈喽，同学你好，彩色屏你尝试过了吗？

Rulsion, 2022-05-30:
已收到，放心

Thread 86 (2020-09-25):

怎么把源文件（GerBer也行）上传到嘉立创上啊

chen-yixing8, 2020-09-25:
在立创下单助手上搞了半天都没弄好，自己再弄的GerBer也没弄好，文件也压缩了，就是不知道哪出问题了

chen-yixing8, 2020-09-25:
#38

Closed 2020-09-25.

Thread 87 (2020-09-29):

有无可能把手机充值交通卡的功能，也做上去呢？

dxkrs, 2020-09-29:
我猜大致要承载一个安卓系统了？我试过用蓝牙连接一个NFC设备来充值ETC卡。另外，某些APP通过手机NFC充值会有优惠的（狗头

BH6AOV, 2020-10-06:
违法

MooWantFree, 2020-10-26:
充值公交卡需要对公交卡进行较为频繁的写卡功能，很明显这个设备不具有任何写卡功能。
另外即使可以写卡，充值协议也是私有的，只有大厂才可能有（微信、小米）

PikuZheng, 2020-12-17:
可以把这玩意当作一个普通的公交卡，用手机app来对它充值。这个和手机给自身的nfc虚拟卡充值原理不同。

12121-12121, 2021-01-26:
从技术上讲是可以的，但是涉及到法律问题。

polarisNoSnow, 2022-04-05:
充值肯定会连接那边的系统后台，记录相关数据。其次，就算刷卡不会和后台比对数据，我相信写卡数据都是加密的，需要公私钥。当然，理论上可以将另一用户的所有卡片数据复制过来，那就没意义了，相当于补卡而已（就和现在手机nfc复制功能一样），所以个人充值没戏。手机里面ic充值必然都是和对方公司签了合同，发了秘钥，才能进行修改操作的。

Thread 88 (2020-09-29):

关于 NRST 引脚上拉电阻问题

CloverGit, 2020-09-29:
通过阅读 [STM32L051K8 datasheet](https://www.st.com/resource/zh/datasheet/stm32l051k8.pdf) 第 84 页，发现在 图.27 中， NRST 引脚应该是有内部上拉，为什么在 L-ink Card 中又增加了一个阻值 10K 的外部上拉电阻 R6 呢?

mojinpan, 2021-02-04:
这个一方面是习惯性的做法,不是所有的mcu都内置上拉的,而且加了上拉 也不会有太大问题,所以一般都没有预留.另外一方面虽然内置了上拉,但是外置上拉电阻配合对地的电容能构成一个对电源的低通滤波,对高频干扰和启动时的抖动有很好的抑制,所以加上可靠性一般会更好.总结下来就是加上电阻大概没有错,而且大不了可以不焊,所以大家都不一定仔细看规格书,直接默认加上

Closed 2022-06-30.

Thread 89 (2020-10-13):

关于3D打印的问题

dorlolo, 2020-10-13:
3D Models文件夹里面有一个叫stand.stl这个文件里面的模型做什么用的？
我是把2.unibody version文件夹里的东西全部都在网上下单打印了，到货就试一下，如果有人知道希望留个言。等到货了我也说明一下。

yelvlab, 2020-10-15:
`1.discrete version` 目录里面的是稚晖的早期版本，解决了有没有的问题，然后两个文件一个是外壳，一个是内部支撑。

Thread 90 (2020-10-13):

关于拨轮开关控制卡片切换的疑惑

wei762359599, 2020-10-13:
你好  相请教一下卡片的切换是具体怎么通过拨轮开关控制的呢，通过看原理图，扳动拨轮开关只是将天线切换不用的连接，是对应ST25DV16K-JFR6D3芯片的AC0和AC1的是否连接来传输不同储存区的卡片信息吗？
表述的可能不是很清楚，但主要想知道通过拨轮开关切换卡片信息具体是怎么实现的。
希望看到的大佬们能够百忙之中抽时间解答一下这个疑惑。

ZwenChen, 2020-10-20:
好像还需要加UID芯片才能刷卡，ST25DV只能与手机互传信息，我也不太明白可以私下交流一下。

wei762359599, 2020-11-02:
> 好像还需要加UID芯片才能刷卡，ST25DV只能与手机互传信息，我也不太明白可以私下交流一下。

感谢  是这样的 一开始以为是可以用ST25DV来模拟卡

Closed 2020-11-02.

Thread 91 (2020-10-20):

所有文件都下载不了！

endofcool, 2020-10-20:
所有文件都下载不了，怎么回事？

dzllicht, 2020-10-23:
Try download with Motrix.

PikuZheng, 2020-12-17:
githubusercontent是托管在亚马逊云上的 部分地区需要科学上网（尤其是电信

pdsflck, 2021-08-18:
下载GitHub桌面版，我试了可以

zzl487876, 2021-12-16:
> 下载GitHub桌面版，我试了可以

我用手机怎么也不行啊

Rulsion, 2021-12-16:
已收到，放心

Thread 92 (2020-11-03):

目前这个方案支持id卡吗

corogoo, 2020-11-03:
小区还有单元们都是用的id卡，目前这个方案支持id卡吗

xidameng, 2020-11-25:
readme 里面有写吧，现在只支持IC卡

reedlxm, 2020-12-09:
理论上ID卡应该更简单，只要有芯片。只是不知道能不能公用天线。另外就是下一代模拟芯片的可能不支持

我手头也是3张IC，2张ID

reedlxm, 2020-12-10:
另外我觉得如果不能兼容ID卡的话，这个项目的意义也不是很大。毕竟IC卡都可以用小米手环之类的手机全功能nfc模拟。也就加密卡麻烦一点，关键点也在pm3上面。
ID卡和IC卡应该是不能共用天线，频率不同。不知道能不能改一改加一套天线

corogoo, 2020-12-12:
想了一下 我飞线弄一个id的线圈吧 以后正面ic  背面 id

PikuZheng, 2020-12-17:
> 想了一下 我飞线弄一个id的线圈吧 以后正面ic 背面 id

搞个T5577贴上去 除了又厚了一点没毛病 线圈频率不同不耽误用ic

supersensen, 2021-01-29:
万能宝上搜T5577 ID卡，可读写复制，两三块钱一个，可以带天线一起直接塞在里面，125Khz频率与CUID互不影响。闲的话跟CUID天线共地焊在拨动开关的一个档位上也行。

Yinke7, 2021-03-09:
> > 想了一下 我飞线弄一个id的线圈吧 以后正面ic 背面 id
>
> 搞个T5577贴上去 除了又厚了一点没毛病 线圈频率不同不耽误用ic

你这个方法可以，就直接硬搞

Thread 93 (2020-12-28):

为什么我下载不了呢

liliangliyangjia, 2020-12-28:
Unable to connect

Firefox can't establish a connection to the server at raw.githubusercontent.com.

    The site could be temporarily unavailable or too busy. Try again in a few moments.
    If you are unable to load any pages, check your computer's network connection.
    If your computer or network is protected by a firewall or proxy, make sure that Firefox is permitted to access the Web.

AspartameJ, 2021-01-24:
网络问题

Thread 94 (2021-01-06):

如果我不需要模拟门禁卡的功能，只需要用一块墨水瓶，然后加上NFC的功能呢？

12121-12121, 2021-01-06:
这样可能有点偏离初衷了，，，
但我是这样想的，借题发挥吧。如果我不需要模拟门禁卡的功能，只需要一块墨水瓶加上NFC功能，实现用手机一碰就能把手机里的照片传到墨水瓶上，功耗问题应该不用着重考虑，请问这样该怎么实现呢，用树莓派或者arduino行吗？pcb我实在不会画，还有我从网上百度了，没人做这个，都是做相册什么的。
我是初中生，刚接触这方面，水平还不够，请多多指教！

12121-12121, 2021-01-06:
> 这样可能有点偏离初衷了，，，
> 但我是这样想的，借题发挥吧。如果我不需要模拟门禁卡的功能，只需要一块墨水屏加上NFC功能，实现用手机一碰就能把手机里的照片传到墨水瓶上，功耗问题应该不用着重考虑，请问这样该怎么实现呢，用树莓派或者arduino行吗？pcb我实在不会画，还有我从网上百度了，没人做这个，都是做相册什么的。
> 我是初中生，刚接触这方面，水平还不够，请多多指教！

fml927, 2021-01-26:
树莓派加个显示器和NFC设备 应该就，只是得自己捣鼓下

Yinke7, 2021-03-09:
微雪官网上有你这种，一个墨水屏加NFC的，指路：https://www.waveshare.net/shop/1.54inch-NFC-Powered-e-Paper-BW.htm

csr865, 2021-05-03:
> 这样可能有点偏离初衷了,,,
> 但我是这样想的，借题发挥吧。如果我不需要模拟门禁卡的功能，只需要一块墨水瓶加上NFC功能，实现用手机一碰就能把手机里的照片传到墨水瓶上，导致问题应该不用着重考虑，请问这样该怎么实现呢，用树莓派或者arduino行吗？pcb我实在不会画，还有我从网上百度了，没人做这个，都是做相册什么的。
> 我是初中生，刚接触这方面，水平还不够，请多多指教！

确实而且对结构差别并不大，就加了两个UID芯片而已

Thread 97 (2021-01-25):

PCB设计图打不开

UDMark, 2021-01-25:
下载下来的pcb设计图用AD19打不开呢，一直提示file type not recognised. 有大佬知道什么问题么？

12121-12121, 2021-01-26:
不会呀，我用AD20完全没问题

Closed 2021-01-26.

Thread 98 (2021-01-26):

关于用手机NFC写图

12121-12121, 2021-01-26:
请问怎么使用安卓手机的NFC功能？华为手机行吗？
怎么和卡片进行通信？以及怎么传图片？
谢谢！

fml927, 2021-01-26:
L-ink_Card/Android/下面不就是APK么

12121-12121, 2021-01-26:
> L-ink_Card/Android/下面不就是APK么

谢谢您的回答，不过我是说如何在Android Studio中进行软件开发，安卓小白，还有些不懂，还请多多指教

mojinpan, 2021-02-16:
@@12121-12121 我已经搞定nfc传输图片到ink上,而且移植到了更大的ink上,但是作者的app没有开源,自己对安卓app的开发也是一无所知,看看有没有志同道合的朋友一起实现这个功能,我的qq:4764971

mojinpan, 2021-02-16:
@peng-zhihui 大神能开源APP吗,或者改一下app支持图片分辨率的设置,以便在不同的ink上使用,感谢!!!

fingerart, 2022-11-06:
@12121-12121 可通过Android发现TAG，然后使用SDK（[https://www.st.com/en/embedded-software/stsw-st25sdk001.html](https://www.st.com/en/embedded-software/stsw-st25sdk001.html)）传输数据，里面有Android的示例。

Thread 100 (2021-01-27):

ic卡问题

12121-12121, 2021-01-27:
pcb板子上挖的那两个洞是做什么用的？st25d芯片可以直接模拟ic卡吗？还是需要在那两个洞里面添加两个ic芯片共用天线吗？可以添加几张卡进里面？

QY7, 2021-01-28:
文档里面有写，std25d的协议不一样，不支持模拟IC。挖的洞是用来放UID芯片的，和板子共用天线。旧版本的挖了两个洞，能添加两张卡

12121-12121, 2021-02-01:
> 文档里面有写，std25d的协议不一样，不支持模拟IC。挖的洞是用来放UID芯片的，和板子共用天线。旧版本的挖了两个洞，能添加两张卡

那请问新版本呢？

Yinke7, 2021-03-09:
> > 文档里面有写，std25d的协议不一样，不支持模拟IC。挖的洞是用来放UID芯片的，和板子共用天线。旧版本的挖了两个洞，能添加两张卡
>
> 那请问新版本呢？

我也移植等着【稚晖君】更新版本，目前我已经做了 ST95 的方案, 能读UID，但是不知道怎么用软件模拟IC卡。。。

NaClFishwulala, 2022-02-09:
所以我想问一下IC卡的读写代码是不是不包含在源码里面

Rulsion, 2022-02-09:
已收到，放心

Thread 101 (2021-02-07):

基于L-ink_card的改进版<目前的问题>求帮助

lyjuestc, 2021-02-07:
利用st95来做软件层面的模拟卡，同时实现对nfc卡的读取。st95正好支持多种协议的卡片读写功能和卡片模拟功能。

目前的问题：参考st95官方评估板做了一套板子，能够读取nfc卡的uid，但是无法读取卡的扇区数据，错误返回为传输错误，但是能够读取uid，读写芯片寄存器都可以成功。

有没有大佬做过类似的NFC项目，指导一下。。。。

这是st95评估板代码中的数据读取代码。运行到这里每次都是error。
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

求帮助啊、、。。。。。。

Yinke7, 2021-03-09:
Sorry, your problem is too simple. I hope it will be better for you to solve it  by yourself

HouqiLi, 2022-04-12:
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

你好，请问有ST95的demo吗？你的问题解决没有？

wdon9, 2022-07-21:
同问

wdon9, 2022-07-21:
@lyjuestc HELLO，问题解决了吗？

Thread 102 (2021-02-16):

请求开发apk传送图片的分辨率设置,以适配不同屏幕

mojinpan, 2021-02-16:
@peng-zhihui 大神,是否修改一下app,提供分辨率的设置,以适配不同屏幕?

有没有其他朋友希望用手机app通过nfc刷图片到ink上的,希望有朋友一起来做类似的移植,目前已经将L-ink_Card移植到4.2寸墨水屏上了,但是没有合适的app来实现图片的传送,有兴趣的朋友可以一起来折腾(QQ:4764971)

peng-zhihui, 2021-02-16:
有空我把app里的通信部分封装成lib发出来吧

发自我的iPhone

------------------ 原始邮件 ------------------
发件人: mojinpan <notifications@github.com&gt;
发送时间: 2021年2月16日 23:05
收件人: peng-zhihui/L-ink_Card <L-ink_Card@noreply.github.com&gt;
抄送: 稚晖 <593245898@qq.com&gt;, Mention <mention@noreply.github.com&gt;
主题: 回复：[peng-zhihui/L-ink_Card] 请求开发apk传送图片的分辨率设置,以适配不同屏幕 (#102)

@peng-zhihui 大神,是否修改一下app,提供分辨率的设置,以适配不同屏幕?

有没有其他朋友希望用手机app通过nfc刷图片到ink上的,希望有朋友一起来做类似的移植,目前已经将L-ink_Card移植到4.2寸墨水屏上了,但是没有合适的app来实现图片的传送,有兴趣的朋友可以一起来折腾(QQ:4764971)

—
You are receiving this because you were mentioned.
Reply to this email directly, view it on GitHub, or unsubscribe.

mojinpan, 2021-02-16:
最好能在app上增加一下分辨率的设置,方便我们这些不太懂安卓app的嵌入式开发者,这样只要搞定stm32部分的移植就可以实现灵魂的注入了,感谢大神! @peng-zhihui

agentZhang, 2022-05-13:
>

求发！

CarpenterMc, 2022-07-19:
同求适配不同尺寸墨水屏的手机app

Rulsion, 2022-07-19:
已收到，放心

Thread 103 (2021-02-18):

Cilon下载不成功，DapLink和ST-Link V2都试过了，显示

Tony-Tang0723, 2021-02-18:
F:\OpenOCD\openocd-20201228\OpenOCD-20201228-0.10.0\bin\openocd.exe -c "tcl_port disabled" -s F:\OpenOCD\openocd-20201228\OpenOCD-20201228-0.10.0\share\openocd\scripts -c "gdb_port 3333" -c "telnet_port 4444" -f board\st_nucleo_f103rb.cfg -c "program \"C:/tony/L-ink_Card-master/L-ink_Card-master/Firmware/Clion/L-ink_Card/cmake-build-debug/L-ink_Card.elf\"" -c reset -c shutdown
 [0m [0mOpen On-Chip Debugger 0.10.0 (2020-12-28) [https://github.com/sysprogs/openocd]
Licensed under GNU GPL v2
libusb1 09e75e98b4d9ea7909e8837b7a3f00dda4589dc3
For bug reports, read
        http://openocd.org/doc/doxygen/bugs.html
WARNING: interface/stlink-v2.cfg is deprecated, please switch to interface/stlin
k.cfg
Info : The selected transport took over low-level target control. The results mi
ght differ compared to plain JTAG/SWD
Info : clock speed 1000 kHz
Error: open failed
in procedure 'program'
** OpenOCD init failed **
shutdown command invoked

求一个不会出错的.cfg文件，谢谢

sparrowhe, 2021-07-10:
try：https://community.platformio.org/t/openocd-init-failed/12689

Asensio-ai, 2021-07-22:
您好，请问问题解决了吗？我也遇到了相同的问题

ab1324ab, 2022-06-11:
我的能下载 但不能调试

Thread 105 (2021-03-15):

关于五维按键

Yinke7, 2021-03-15:
请问五维按键在哪里可以买啊？
我怎么在淘宝上一搜，全是大疆遥控器的配件，有没有类似电子元器件网站，在买这个东东的？

wherehazy, 2021-08-10:
9！u7MkXOPoOrr信 https://m.tb.cn/h.fZ9JqUQ?sm=83c6bc  大头拨轮 三脚/6脚 开关 复位开关 拨动开关 MP3/MP4 换曲按键
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

TripleEarth, 2021-08-15:
> 请问五维按键在哪里可以买啊？
> 我怎么在淘宝上一搜，全是大疆遥控器的配件，有没有类似电子元器件网站，在买这个东东的？

搜***五向开关***，淘宝有家店叫***温州一键***（不是广告），里面有个7*7的，我看了一下pcb图，好像就是那个，你看好孔位，别买错了。（我本来想找魔改版的那个大佬讨个BOM单的，找不到联系方式:sob:）

sanshui-jpg, 2021-12-27:
这个改版的有人做出来吗，我做了一个电源都没通，我都怀疑人生了

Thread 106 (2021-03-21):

NFC与手机通信失败

gaowangchen, 2021-03-21:
大佬们  我是一步一步测试焊接的  目前STM32L0可以   电源可以   单独焊接UID芯片用拨轮控制在手机上也可以检测到   然后焊接好ST25与手机通信一直没有动静  可能是什么原因呢

gaowangchen, 2021-03-22:
> 大佬们我是一步一步测试焊接的目前STM32L0可以电源可以单独焊接UID芯片用拨轮控制在手机上也可以检测到然后焊接好ST25与手机通信一直没有动静可能是什么原因呢

我又来了  目前NFC通信可以了  但是屏幕死活点不亮  就差最后一步了   不想放弃啊

916315265, 2021-04-09:
我也是这样的问题，手机app也会显示传输成功，但是屏幕就是不显示图案，电池也是新的。

gaowangchen, 2021-04-11:
> 我也是这样的问题，手机app也会显示传输成功，但是屏幕就是不显示图案，电池也是新的。

怎么样  找到问题了吗

qinzhongle, 2024-01-17:
> > 我也是这样的问题，手机app也会显示传输成功，但是屏幕就是不显示图案，电池也是新的。
>
> 怎么样 找到问题了吗

你现在是什么情况？我是一名大一学生 现在已经放寒假了 想请教你一下 怎么完成这个项目 尤其是加密卡读写那一方面 如果你看到了这个留言 我很期待你能给我一个回复！

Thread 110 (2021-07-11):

ST-Link在sw模式下不识别板子，JTAG模式又有

Gradec, 2021-07-11:
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
SW模式报错
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
这是JTAG模式的显示，芯片的话应该是焊好了，挺干净的，有没有大佬能解决这个问题

Somebodyunsimple, 2022-01-09:
我也遇到了相同的情况，但是在那个JTAG模式也检测不到芯片，我反复检查板子有没有元件短路，前前后后焊了三块板子，最后都检测不到。迷茫

Somebodyunsimple, 2022-01-09:
之前那个NC电阻焊上去，会导致板子短路，接上ST-LNIK没反应，3.3v和GND反接就直接烧坏ST-LINK

zxg12333, 2024-04-26:
我也是，但是我改了一下传输速率就行了

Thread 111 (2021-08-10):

请问这个LED的限流电阻R8为什么这么大？

wherehazy, 2021-08-10:
静态电流20mA的情况下，3.0V的分压，引脚输出电平不也就是3.3V吗，为啥要用这么大的限流电阻，一般不就几十欧姆吗？
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

wherehazy, 2021-08-23:
解决了，原来是用的这个LED
这里买的https://item.taobao.com/item.htm?spm=a1z09.2.0.0.4f7d2e8dZxsMrT&id=591307353157&_u=n2qgj3d9a15e
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

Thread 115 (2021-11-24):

关于TP6122

xiaokamikami, 2021-11-24:
TI的TP6122没货了可以换成SX1308 B628 升压芯片吗

netube99, 2022-01-24:
很明显不行，1308在小电流输出时效率很低的

netube99, 2022-01-24:
> TI的TP6122没货了可以换成SX1308 B628 升压芯片吗

很明显不行，1308小电流输出时效率太低，不符合低功耗要求

jiuchegnbanxia, 2022-03-21:
> > TI的TP6122没货了可以换成SX1308 B628 升压芯片吗
>
> 直接把TPS61221去掉吧，还有升压电感，直接把输入和输出用导线连接起来，通过电池供电就行了。可以把电池电压用到二伏多一点。你看原理图会发现升压电路是错的，没有了输入和输出电容，所以无法完成升压的，另外电源部分的PCB布局也有些问题。可能是当初设计时没仔细看文档吧，上面明明说的很清楚的。

原理图没错啊，这个芯片就是固定升压输出3.3V，干电池作为输入端，而且电路中没有放大器、振荡器，输入端和输出端的滤波电容是可以不加的

Libaididi, 2022-04-12:
tps61221有没有替代方案，这个芯片淘宝卖60根本买不起。

GYSS1204, 2022-04-12:
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

可是这并不是基于电荷泵的升压电路，而是开关直流升压电路，你可以看下boost升压电路原理，电容和电感是升压的关键元件。

Libaididi, 2022-04-12:
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这是典型应用电路。

GYSS1204, 2022-04-12:
> 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这是典型应用电路。
>

是的，作者的原理图里缺少了电容，所以导致不能正常升压。你可以去除这个芯片，并且把pcb上芯片vin和vout的焊盘短接，l-ink是可以正常工作的，这是最方便的一种解决办法。

jiuchegnbanxia, 2022-04-12:
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
开关直流升压电路电感给电容充电实现升压，确实都是关键器件。输入电容为了抗干扰、改善瞬态响应，应该也能去，输出端的电容按理说是升压电容，但是我按他的电路试了是可以输出3.3V的（空载），我回头把输出电容接上对比下带载的时候是啥样

jiuchegnbanxia, 2022-04-12:
> tps61221有没有替代方案，这个芯片淘宝卖60根本买不起。

可替代的太多了，我用的RT9193-33GB

GYSS1204, 2022-04-12:
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

额，那你可以测量下新的纽扣电池电压，是在3.3v左右。或者你有示波器的话测量电感，看下是否有开关电压波形。

GYSS1204, 2022-04-12:
> > tps61221有没有替代方案，这个芯片淘宝卖60根本买不起。
>
> 可替代的太多了，我用的RT9193-33GB

RT9193-33GB是线性降压稳压芯片，没法升压，所以不适合用在这里。

GYSS1204, 2022-04-12:
> tps61221有没有替代方案，这个芯片淘宝卖60根本买不起。

具体你可以看下电荷泵升压的芯片xa2320b和hx4002b，不过需要你重新设计电路修改pcb板，不能直接在作者的pcb上使用。

jiuchegnbanxia, 2022-04-12:
> > tps61221有没有替代方案，这个芯片淘宝卖60根本买不起。
>
> 具体你可以看下电荷泵升压的芯片xa2320b和hx4002b，不过需要你重新设计电路修改pcb板，不能直接在作者的pcb上使用。

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

嗯嗯，这个知道，我没说清楚，我是换了3.7V的锂电

jiuchegnbanxia, 2022-04-12:
> > tps61221有没有替代方案，这个芯片淘宝卖60根本买不起。
>
> 具体你可以看下电荷泵升压的芯片xa2320b和hx4002b，不过需要你重新设计电路修改pcb板，不能直接在作者的pcb上使用。

好的，我回头瞅瞅看好不好买

jiuchegnbanxia, 2022-04-13:
> tps61221有没有替代方案，这个芯片淘宝卖60根本买不起。

原方案的话，我又找了下，可以用航天民芯的MT3540

Libaididi, 2022-04-13:
> > tps61221有没有替代方案，这个芯片淘宝卖60根本买不起。
>
> 原方案的话，我又找了下，可以用航天民芯的MT3540
你好，把这个芯片直接焊到tps6122的位置就可以了吗？

jiuchegnbanxia, 2022-04-13:
>
不可以，需要按手册重新设计电路

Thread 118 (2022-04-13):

pcb板子

GuoYuchen2007, 2022-04-13:
pcb板子的尺寸是多少啊

JH0220, 2022-04-30:
同问

Rulsion, 2022-04-30:
已收到，放心

JH0220, 2022-04-30:
> pcb板子的尺寸是多少啊

哈喽 请问您问到尺寸了嘛

JH0220, 2022-04-30:
> 已收到，放心

您好 请问一下您这边知道这个板子的尺寸吗 嘉立创打板不知道尺寸

michaelyu0906, 2022-05-25:
同问

TPAXcc, 2022-06-07:
传 Gerbar 的时候别加文件夹。

UNIONDONG, 2022-06-12:
板子的尺寸，生成gerbar时，不是有吗？

UNIONDONG, 2022-06-12:
或者将gerbar上传到嘉立创上，会自动出现的呀

sanellno, 2022-10-05:
不会生成garbar哎，怎么看尺寸

sanellno, 2022-10-05:
不会生成gerbar哎，请问怎么看尺寸

TPAXcc, 2022-10-08:
直接上传压缩包就行，不要加文件夹会自动识别。

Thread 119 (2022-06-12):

关于便捷调试

UNIONDONG, 2022-06-12:
Dear All：

>  目前正在发板子，提前买的模组已经回来了，想看大家都是怎么调试的

    **目前的规划，按模组进行调试**：

- 对于`STM32L051`这个芯片，只能在设计的硬件上进行调试；
- 对于`ST25DV`，可以将其焊接到废旧的板子上，找到对应的封装，然后直接焊接线出来调试；
- 对于墨水屏，买回来24pin插座，接n根调试线吗？

**想咨询大家，有没有好的调试手法**？

> 总不能所有的都等到板子回来，在板子上调试吧？定位问题也不好定位......

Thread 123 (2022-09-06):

一个纯小白想请教下各位大佬

G1kl, 2022-09-06:
刚用github，如果这个内容不属于issue的话我把他关掉（如果可以的话）
其实B站的视频我看下来感觉稚晖君在说他的设计思路，我想要搞懂几个主要原件的作用
元器件的焊接好像可以在打板子的时候一起焊？自己焊的话对技术要求高吗？我自己以前用过电烙铁也焊过一点点东西，但是技术自认为挺差的
我看到板子中间挖了两个孔，相当于这个设计并没有把卡里面的数据复制下来，而是需要自己把卡里面的芯片取出之后焊上去吗？
关于烧录，烧录指的就是把那些源代码写入芯片里面的步骤吗？自己在电脑上烧录的话除了需要在淘宝购买相关烧录的软件（我看有些issue下面是这么说的）还需要什么东西吗？感觉看github上的过程也有点蒙

Rulsion, 2022-09-06:
已收到，放心

Mahaochen11, 2022-10-27:
我也想问，卡多的话咋办

bicohuang, 2023-02-26:
> 刚用github，如果这个内容不属于issue的话我把他关掉（如果可以的话） 其实B站的视频我看下来感觉稚晖君在说他的设计思路，我想要搞懂几个主要原件的作用 元器件的焊接好像可以在打板子的时候一起焊？自己焊的话对技术要求高吗？我自己以前用过电烙铁也焊过一点点东西，但是技术自认为挺差的 我看到板子中间挖了两个孔，相当于这个设计并没有把卡里面的数据复制下来，而是需要自己把卡里面的芯片取出之后焊上去吗？ 关于烧录，烧录指的就是把那些源代码写入芯片里面的步骤吗？自己在电脑上烧录的话除了需要在淘宝购买相关烧录的软件（我看有些issue下面是这么说的）还需要什么东西吗？感觉看github上的过程也有点蒙

中间两个孔是用来放芯片。稚晖君他自己放是网上买的空白芯片，理论上是可以剪卡取芯片放上去，所谓烧录，是指把程序写入指定的芯片的，在这里是指把编译好的程序写入的stm32L0芯片的过程，一般情况下需要一个烧录专用的设备就行了，很多ide都集成烧录指令

Rulsion, 2023-02-26:
已收到，放心

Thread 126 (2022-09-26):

有人知道如何刷卡入L-ink_Card嘛？

leokwsw, 2022-09-26:
看了無數次稚暉君L-ink_Card的片 但一直無說如何刷卡入L-ink_Card和管理在L-ink_Card的卡片，請問有誰知道嘛？

Wangshuanghu, 2024-07-18:
IC卡的模拟功能这一版中实现得比较简单，就是直接集成了多颗UID芯片（很便宜，1~2元一片），然后和ST25DV共用NFC天线，卡片的切换是通过拨轮换挡实现的。好处在于，你可以把L-ink当作多张独立卡片的合集处理，复制和刷卡都是很直接的（使用PM3或者PN532等模块读取原卡信息并写入L-link）。当然缺点就是添加的卡片一多，按键的数量就要增加（因为每一档对应一张卡）。

**### readme.md中原文**

Rulsion, 2024-07-18:
已收到，放心

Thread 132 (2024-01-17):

请教请教！有没有已经完全做好了这个项目的？

qinzhongle, 2024-01-17:
我是一名大一学生 现在已经放寒假了 想请教一下 怎么完成这个项目 尤其是加密卡读写那一方面 如果你们看到了这个留言 我很期待你们能给我一个回复！

qinzhongle, 2024-01-19:
comecome!

Horldsence, 2024-02-10:
我也是大一新生，现在也在复刻，或许有机会可以交流下。
_刚买完所有器件（淘宝和立创商城），外壳3D打印的，板子嘉立创打。('ヮ')_

Rulsion, 2024-02-10:
已收到，放心

Horldsence, 2024-02-10:
> comecome!

我也是大一新生，现在也在复刻，或许有机会可以交流下。
_刚买完所有器件（淘宝和立创商城），外壳3D打印的，板子嘉立创打。('ヮ')_

jeremylee1, 2024-05-31:
> > comecome!
>
> 我也是大一新生，现在也在复刻，或许有机会可以交流下。 _刚买完所有器件（淘宝和立创商城），外壳3D打印的，板子嘉立创打。('ヮ')_

我找了下很多都买不到 能分享一下零件的购买链接么。我也是想拿这个项目练练手

Rulsion, 2024-05-31:
已收到，放心

Rulsion, 2024-11-18:
已收到，放心

Closed 2024-11-18.

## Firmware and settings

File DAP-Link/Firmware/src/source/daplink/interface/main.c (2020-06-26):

/**
 * @file    main.c
 * @brief   Entry point for interface program logic
 *
 * DAPLink Interface Firmware
 * Copyright (c) 2009-2019, ARM Limited, All Rights Reserved
 * SPDX-License-Identifier: Apache-2.0
 *
 * Licensed under the Apache License, Version 2.0 (the "License"); you may
 * not use this file except in compliance with the License.
 * You may obtain a copy of the License at
 *
 * http://www.apache.org/licenses/LICENSE-2.0
 *
 * Unless required by applicable law or agreed to in writing, software
 * distributed under the License is distributed on an "AS IS" BASIS, WITHOUT
 * WARRANTIES OR CONDITIONS OF ANY KIND, either express or implied.
 * See the License for the specific language governing permissions and
 * limitations under the License.
 */

#include <string.h>
#include <stdio.h>

#include "cmsis_os2.h"
#include "rl_usb.h"
#include "main.h"
#include "gpio.h"
#include "uart.h"
#include "tasks.h"
#include "swd_host.h"
#include "info.h"
#include "settings.h"
#include "daplink.h"
#include "util.h"
#include "DAP.h"
#include "bootloader.h"
#include "cortex_m.h"
#include "sdk.h"
#include "target_family.h"
#include "target_board.h"

#ifdef DRAG_N_DROP_SUPPORT
#include "vfs_manager.h"
#include "flash_intf.h"
#include "flash_manager.h"
#endif

// Event flags for main task
// Timers events
#define FLAGS_MAIN_90MS         (1 << 0)
#define FLAGS_MAIN_30MS         (1 << 1)
// Reset events
#define FLAGS_MAIN_RESET        (1 << 2)
// Other Events
#define FLAGS_MAIN_POWERDOWN    (1 << 4)
#define FLAGS_MAIN_DISABLEDEBUG (1 << 5)
#define FLAGS_MAIN_PROC_USB     (1 << 9)
// Used by cdc when an event occurs
#define FLAGS_MAIN_CDC_EVENT    (1 << 11)
// Used by msd when flashing a new binary
#define FLAGS_LED_BLINK_30MS    (1 << 6)

// Timing constants (in 90mS ticks)
// USB busy time (~3 sec)
#define USB_BUSY_TIME           (33)
// Delay before a USB device connect may occur (~1 sec)
#define USB_CONNECT_DELAY       (11)
// Timeout for USB being configured (~2 sec)
#define USB_CONFIGURE_TIMEOUT   (22)
// Delay before target may be taken out of reset or reprogrammed after startup
#define STARTUP_DELAY           (1)

// Decrement to zero
#define DECZERO(x)              (x ? --x : 0)

//default hid led settings
#ifndef HID_LED_DEF
#define HID_LED_DEF GPIO_LED_OFF
#endif

//default cdc led settings
#ifndef CDC_LED_DEF
#define CDC_LED_DEF GPIO_LED_OFF
#endif

//default msc led settings
#ifndef MSC_LED_DEF
#define MSC_LED_DEF GPIO_LED_OFF
#endif

// Reference to our main task
osThreadId_t main_task_id;

// USB busy LED state; when TRUE the LED will flash once using 30mS clock tick
static uint8_t hid_led_usb_activity = 0;
static uint8_t cdc_led_usb_activity = 0;
static uint8_t msc_led_usb_activity = 0;
static main_led_state_t hid_led_state = MAIN_LED_FLASH;
static main_led_state_t cdc_led_state = MAIN_LED_FLASH;
static main_led_state_t msc_led_state = MAIN_LED_FLASH;

// Global state of usb
main_usb_connect_t usb_state;
static bool usb_test_mode = false;

// Timer task, set flags every 30mS and 90mS
void timer_task_30mS(void * arg)
{
    static uint32_t i = 0;
    osThreadFlagsSet(main_task_id, FLAGS_MAIN_30MS);
    if (!(i++ % 3)) {
        osThreadFlagsSet(main_task_id, FLAGS_MAIN_90MS);
    }
}

// Functions called from other tasks to trigger events in the main task
// parameter should be reset type??
void main_reset_target(uint8_t send_unique_id)
{
    osThreadFlagsSet(main_task_id, FLAGS_MAIN_RESET);
    return;
}

// Flash HID LED using 30mS tick
void main_blink_hid_led(main_led_state_t state)
{
    hid_led_usb_activity = 1;
    hid_led_state = state;
    return;
}

// Flash CDC LED using 30mS tick
void main_blink_cdc_led(main_led_state_t state)
{
    cdc_led_usb_activity = 1;
    cdc_led_state = state;
    return;
}

// Flash MSC LED using 30mS tick
void main_blink_msc_led(main_led_state_t state)
{
    msc_led_usb_activity = 1;
    msc_led_state = state;
    return;
}

// Power down the interface
void main_powerdown_event(void)
{
    osThreadFlagsSet(main_task_id, FLAGS_MAIN_POWERDOWN);
    return;
}

// Disable debug on target
void main_disable_debug_event(void)
{
    osThreadFlagsSet(main_task_id, FLAGS_MAIN_DISABLEDEBUG);
    return;
}

// Start CDC processing
void main_cdc_send_event(void)
{
    osThreadFlagsSet(main_task_id, FLAGS_MAIN_CDC_EVENT);
    return;
}

void main_usb_set_test_mode(bool enabled)
{
    usb_test_mode = enabled;
}

void USBD_SignalHandler()
{
    osThreadFlagsSet(main_task_id, FLAGS_MAIN_PROC_USB);
}

extern void cdc_process_event(void);

void main_task(void * arg)
{
    // State processing
    uint16_t flags = 0;
    // LED
    gpio_led_state_t hid_led_value = HID_LED_DEF;
    gpio_led_state_t cdc_led_value = CDC_LED_DEF;
    gpio_led_state_t msc_led_value = MSC_LED_DEF;
    // USB
    uint32_t usb_state_count = USB_BUSY_TIME;
    uint32_t usb_no_config_count = USB_CONFIGURE_TIMEOUT;
    // button state
    uint8_t reset_pressed = 0;
#ifdef PBON_BUTTON
    uint8_t power_on = 1;
#endif

    // Initialize settings - required for asserts to work
    config_init();
    // Update bootloader if it is out of date
    bootloader_check_and_update();
    // Get a reference to this task
    main_task_id = osThreadGetId();
    // leds
    gpio_init();
    // Turn to LED default settings
    gpio_set_hid_led(hid_led_value);
    gpio_set_cdc_led(cdc_led_value);
    gpio_set_msc_led(msc_led_value);
    // Initialize the DAP
    DAP_Setup();

    // make sure we have a valid board info structure.
    util_assert(g_board_info.info_version == kBoardInfoVersion);

    // do some init with the target before USB and files are configured
    if (g_board_info.prerun_board_config) {
        g_board_info.prerun_board_config();
    }

    //initialize the family
    init_family();

    if (g_target_family && g_target_family->prerun_target_config) {
        g_target_family->prerun_target_config();
    }

    //setup some flags
    if (g_board_info.flags & kEnableUnderResetConnect) {
        swd_set_reset_connect(CONNECT_UNDER_RESET);
    }
    if (g_board_info.flags & kEnablePageErase) {
#ifdef DRAG_N_DROP_SUPPORT
        flash_manager_set_page_erase(true);
#endif
    }

    // Update versions and IDs
    info_init();
    // USB
    usbd_init();
#ifdef DRAG_N_DROP_SUPPORT
    vfs_mngr_fs_enable((config_ram_get_disable_msd()==0));
#endif
    usbd_connect(0);
    usb_state = USB_CONNECTING;
    usb_state_count = USB_CONNECT_DELAY;

    // Start timer tasks
    osTimerId_t tmr_id = osTimerNew(timer_task_30mS, osTimerPeriodic, NULL, NULL);
    osTimerStart(tmr_id, 3);
    while (1) {
        flags = osThreadFlagsWait(FLAGS_MAIN_RESET             // Put target in reset state
                       | FLAGS_MAIN_90MS            // 90mS tick
                       | FLAGS_MAIN_30MS            // 30mS tick
                       | FLAGS_MAIN_POWERDOWN       // Power down interface
                       | FLAGS_MAIN_DISABLEDEBUG    // Disable target debug
                       | FLAGS_MAIN_PROC_USB        // process usb events
                       | FLAGS_MAIN_CDC_EVENT       // cdc event
                       , osFlagsWaitAny
                       , osWaitForever);

        if (flags & FLAGS_MAIN_PROC_USB) {
            if (usb_test_mode) {
                // When in USB test mode Insert a delay to
                // simulate worst-case behavior.
                osDelay(1);
            }
            USBD_Handler();
        }

        if (flags & FLAGS_MAIN_RESET) {
            target_set_state(RESET_RUN);
        }

        if (flags & FLAGS_MAIN_POWERDOWN) {
            // Disable debug
            target_set_state(NO_DEBUG);
            // Disable board power before USB is disconnected.
            gpio_set_board_power(false);
            // Disconnect USB
            usbd_connect(0);
            // Turn off LED
            gpio_set_hid_led(GPIO_LED_OFF);
            gpio_set_cdc_led(GPIO_LED_OFF);
            gpio_set_msc_led(GPIO_LED_OFF);

            // TODO: put the interface chip in sleep mode
            while (1);
        }

        if (flags & FLAGS_MAIN_DISABLEDEBUG) {
            // Disable debug
            target_set_state(NO_DEBUG);
        }

        if (flags & FLAGS_MAIN_CDC_EVENT) {
            cdc_process_event();
        }

        if (flags & FLAGS_MAIN_90MS) {
            // Update USB busy status
#ifdef DRAG_N_DROP_SUPPORT
            vfs_mngr_periodic(90); // FLAGS_MAIN_90MS
#endif
            // Update USB connect status
            switch (usb_state) {
                case USB_DISCONNECTING:
                    usb_state = USB_DISCONNECTED;
                    // Disable board power before USB is disconnected.
                    gpio_set_board_power(false);
                    usbd_connect(0);
                    break;

                case USB_CONNECTING:
                    // Wait before connecting
                    if (DECZERO(usb_state_count) == 0) {
                        usbd_connect(1);
                        usb_state = USB_CHECK_CONNECTED;
                        // Reset connect timeout
                        usb_no_config_count = USB_CONFIGURE_TIMEOUT;
                    }

                    break;

                case USB_CHECK_CONNECTED:
                    if (usbd_configured()) {
                        // Let the HIC enable power to the target now that high power has been negotiated.
                        gpio_set_board_power(true);

                        usb_state = USB_CONNECTED;
                    }
                    else if (DECZERO(usb_no_config_count) == 0) {
                        // USB configuration timed out, which most likely indicates that the HIC is
                        // powered by a USB wall wart or similar power source. Go ahead and enable
                        // board power.
                        gpio_set_board_power(true);
                    }

                    break;

                case USB_CONNECTED:
                case USB_DISCONNECTED:
                default:
                    break;
            }
        }

        // 30mS tick used for flashing LED when USB is busy
        if (flags & FLAGS_MAIN_30MS) {

            // handle reset button without eventing
            if (!reset_pressed && gpio_get_reset_btn_fwrd()) {
#ifdef DRAG_N_DROP_SUPPORT
               if (!flash_intf_target->flash_busy()) //added checking if flashing on target is in progress
#endif
                {
                    // Reset button pressed
                    target_set_state(RESET_HOLD);
                    reset_pressed = 1;
                }
            } else if (reset_pressed && !gpio_get_reset_btn_fwrd()) {
                // Reset button released
                target_set_state(RESET_RUN);
                reset_pressed = 0;
            }

#ifdef PBON_BUTTON
            // handle PBON pressed
            if(gpio_get_pbon_btn())
            {
                if(power_on)
                {
                    // Loop till PBON is pressed
                    while (gpio_get_pbon_btn()) {;}
                    // Power button released when target was running
                    target_set_state(SHUTDOWN);
                    power_on = 0;
                }
                else
                {
                    // Loop till PBON is pressed
                    while (gpio_get_pbon_btn()) {;}
                    // Power button released when target was already powered off
                    target_set_state(POWER_ON);
                    power_on = 1;
                }
            }
#endif

            // DAP LED
            if (hid_led_usb_activity) {

                if ((hid_led_state == MAIN_LED_FLASH) || (hid_led_state == MAIN_LED_FLASH_PERMANENT)) {
                    // Toggle LED value
                    hid_led_value = GPIO_LED_ON == hid_led_value ? GPIO_LED_OFF : GPIO_LED_ON;

                    // If in flash mode stop after one cycle
                    if ((HID_LED_DEF == hid_led_value) && (MAIN_LED_FLASH == hid_led_state)) {
                        hid_led_usb_activity = 0;
                        hid_led_state = MAIN_LED_DEF;
                    }
                } else {
                    //LED next state is MAIN_LED_DEF
                    hid_led_value = HID_LED_DEF;
                    hid_led_usb_activity = 0;
                }

                // Update hardware
                gpio_set_hid_led(hid_led_value);
            }

            // MSD LED
            if (msc_led_usb_activity) {

                if ((msc_led_state == MAIN_LED_FLASH) || (msc_led_state == MAIN_LED_FLASH_PERMANENT)) {
                    // Toggle LED value
                    msc_led_value = GPIO_LED_ON == msc_led_value ? GPIO_LED_OFF : GPIO_LED_ON;

                    // If in flash mode stop after one cycle
                    if ((MSC_LED_DEF == msc_led_value) && (MAIN_LED_FLASH == msc_led_state)) {
                        msc_led_usb_activity = 0;
                        msc_led_state = MAIN_LED_DEF;
                    }
                } else {
                    //LED next state is MAIN_LED_DEF
                    msc_led_value = MSC_LED_DEF;
                    msc_led_usb_activity = 0;
                }

                // Update hardware
                gpio_set_msc_led(msc_led_value);
            }

            // CDC LED
            if (cdc_led_usb_activity) {

                if ((cdc_led_state == MAIN_LED_FLASH) || (cdc_led_state == MAIN_LED_FLASH_PERMANENT)){
                    // Toggle LED value
                    cdc_led_value = GPIO_LED_ON == cdc_led_value ? GPIO_LED_OFF : GPIO_LED_ON;

                    // If in flash mode stop after one cycle
                    if ((CDC_LED_DEF == cdc_led_value) && (MAIN_LED_FLASH == cdc_led_state)) {
                        cdc_led_usb_activity = 0;
                        cdc_led_state = MAIN_LED_DEF;
                    }
                }else{
                    //LED next state is MAIN_LED_DEF
                    cdc_led_value = CDC_LED_DEF;
                    cdc_led_usb_activity = 0;
                }

                // Update hardware
                gpio_set_cdc_led(cdc_led_value);
            }
        }
    }
}

int main(void)
{
    // Explicitly set the vector table since the bootloader might not set
    // it to what we expect.
#if DAPLINK_ROM_BL_SIZE > 0
    SCB->VTOR = SCB_VTOR_TBLOFF_Msk & DAPLINK_ROM_IF_START;
#endif
    // initialize vendor sdk
    sdk_init();

    osKernelInitialize();                 // Initialize CMSIS-RTOS
    osThreadNew(main_task, NULL, NULL);    // Create application main thread
    osKernelStart();                      // Start thread execution
    for (;;) {}
}

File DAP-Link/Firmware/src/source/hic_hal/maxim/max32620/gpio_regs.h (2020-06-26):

/*******************************************************************************
 * Copyright (C) 2016 Maxim Integrated Products, Inc., All Rights Reserved.
 *
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
 * Except as contained in this notice, the name of Maxim Integrated
 * Products, Inc. shall not be used except as stated in the Maxim Integrated
 * Products, Inc. Branding Policy.
 *
 * The mere transfer of this software does not imply any licenses
 * of trade secrets, proprietary technology, copyrights, patents,
 * trademarks, maskwork rights, or any other form of intellectual
 * property whatsoever. Maxim Integrated Products, Inc. retains all
 * ownership rights.
 *
 ******************************************************************************/

#ifndef _MXC_GPIO_REGS_H_
#define _MXC_GPIO_REGS_H_

#ifdef __cplusplus
extern "C" {
#endif

#include <stdint.h>

/*
    If types are not defined elsewhere (CMSIS) define them here
*/
#ifndef __IO
#define __IO volatile
#endif
#ifndef __I
#define __I  volatile const
#endif
#ifndef __O
#define __O  volatile
#endif
#ifndef __R
#define __R  volatile const
#endif


/*
   Typedefed structure(s) for module registers (per instance or section) with direct 32-bit
   access to each register in module.
*/

/*                                                          Offset          Register Description
                                                            =============   ============================================================================ */
typedef struct {
    __IO uint32_t rst_mode[16];                          /*  0x0000-0x003C   Port P[0..15] Default (Power-On Reset) Output Drive Mode                      */
    __IO uint32_t free[16];                              /*  0x0040-0x007C   Port P[0..15] Free for GPIO Operation Flags                                   */
    __IO uint32_t out_mode[16];                          /*  0x0080-0x00BC   Port P[0..15] Output Drive Mode                                               */
    __IO uint32_t out_val[16];                           /*  0x00C0-0x00FC   Port P[0..15] GPIO Output Value                                               */
    __IO uint32_t func_sel[16];                          /*  0x0100-0x013C   Port P[0..15] GPIO Function Select                                            */
    __IO uint32_t in_mode[16];                           /*  0x0140-0x017C   Port P[0..15] GPIO Input Monitoring Mode                                      */
    __IO uint32_t in_val[16];                            /*  0x0180-0x01BC   Port P[0..15] GPIO Input Value                                                */
    __IO uint32_t int_mode[16];                          /*  0x01C0-0x01FC   Port P[0..15] Interrupt Detection Mode                                        */
    __IO uint32_t intfl[16];                             /*  0x0200-0x023C   Port P[0..15] Interrupt Flags                                                 */
    __IO uint32_t inten[16];                             /*  0x0240-0x027C   Port P[0..15] Interrupt Enables                                               */
} mxc_gpio_regs_t;


/*
   Register offsets for module GPIO.
*/
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

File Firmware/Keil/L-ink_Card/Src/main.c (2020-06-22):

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

/* Includes ------------------------------------------------------------------*/
#include "main.h"
#include "usart.h"
#include "gpio.h"

/* USER CODE BEGIN Includes */
#include "stdio.h"
#include "app_nfc.h"
#include "epd_w21.h"
/* USER CODE END Includes */

/* USER CODE BEGIN PTD */

unsigned char nfcBuffer[] =
        {
                0XFF, 0XFF, 0XFF, 0XFF, 0XFF, 0XFF, 0XFF, 0XFF, 0XFF, 0XFF, 0XFF, 0XFF, 0XFF, 0XFF, 0XFF, 0XFF,
                0XFF, 0XFF, 0XFF, 0XFF, 0XFF, 0XFF, 0XFF, 0XFF, 0XFF, 0XFF, 0XFF, 0XFF, 0XFF, 0XFF, 0XFF, 0XFF,
                0XFF, 0XFF, 0XFF, 0XFF, 0XFF, 0XFF, 0XFF, 0XFF, 0XFF, 0XFF, 0XFF, 0XFF, 0XFF, 0XFF, 0XFF, 0XFF,
                0XFF, 0XFF, 0XFF, 0XFF, 0XFF, 0XFF, 0XFF, 0XFF, 0XFF, 0XFF, 0XFF, 0XFF, 0XFF, 0XFF, 0XFF, 0XFF,
                0XFF, 0XFF, 0XFF, 0XFF, 0XFF, 0XFF, 0XFF, 0XFF, 0XFF, 0XFF, 0XFF, 0XFF, 0XFF, 0XFF, 0XFF, 0XFF,
                0XFF, 0XFF, 0XFF, 0XFF, 0XFF, 0XFF, 0XFF, 0XFF, 0XFF, 0XFF, 0XFF, 0XFF, 0XFF, 0XFF, 0XFF, 0XFF,
                0XFF, 0XFF, 0XFF, 0XFF, 0XFF, 0XFF, 0XFF, 0XFF, 0XFF, 0XFF, 0XFF, 0XFF, 0XFF, 0XFF, 0XFF, 0XFF,
                0XFF, 0XFF, 0XFF, 0XFF, 0XFF, 0XFF, 0XFF, 0XFF, 0XFF, 0XFF, 0XFF, 0XFF, 0XFF, 0XFF, 0XFF, 0XFF,
                0XFF, 0XFF, 0XFF, 0XFF, 0XFF, 0XFF, 0XFF, 0XFF, 0XFF, 0XFF, 0XFF, 0XFF, 0XFF, 0XFF, 0XFF, 0XFF,
                0XFF, 0XFF, 0XFF, 0XFF, 0XFF, 0XFF, 0XFF, 0XFF, 0XFF, 0XFF, 0XFF, 0XFF, 0XFF, 0XFF, 0XFF, 0XFF,
                0XFF, 0XFF, 0XFF, 0XFF, 0XFF, 0XFF, 0XFF, 0XFF, 0XFF, 0XFF, 0XFF, 0XFF, 0XFF, 0XFF, 0XFF, 0XFF,
                0XFF, 0XFF, 0XFF, 0XFF, 0XFF, 0XFF, 0XFF, 0XFF, 0XFF, 0XFF, 0XFF, 0XFF, 0XFF, 0XFF, 0XFF, 0XFF,
                0XFF, 0XFF, 0XFF, 0XFF, 0XFF, 0XFF, 0XFF, 0XFF, 0XFF, 0XFF, 0XFF, 0XFF, 0XFF, 0XFF, 0XFF, 0XFF,
                0XFF, 0XFF, 0XFF, 0XFF, 0XFF, 0XFF, 0XFF, 0XFF, 0XFF, 0XFF, 0XFF, 0XFF, 0XFF, 0XFF, 0XFF, 0XFF,
                0XFF, 0XFF, 0XFF, 0XFF, 0XFF, 0XFF, 0XFF, 0XFF, 0XFF, 0XFF, 0XFF, 0XFF, 0XFF, 0XFF, 0XFF, 0XFF,
                0XFF, 0XFF, 0XFF, 0XFF, 0XFF, 0XFF, 0XFF, 0XFF, 0XFF, 0XFF, 0XFF, 0XFF, 0XFF, 0XFF, 0XFF, 0XFF,
                0XFF, 0XFF, 0XFF, 0XFF, 0XFF, 0XFF, 0XFF, 0XFF, 0XFF, 0XFF, 0XFF, 0XFF, 0XFF, 0XFF, 0XFF, 0XFF,
                0XFF, 0XFF, 0XFF, 0XFF, 0XFF, 0XFF, 0XFF, 0XFF, 0XFF, 0XFF, 0XFF, 0XFF, 0XFF, 0XFF, 0XFF, 0XFF,
                0XFF, 0XFF, 0XFF, 0XFF, 0XFF, 0XFF, 0XFF, 0XFF, 0XFF, 0XFF, 0XFF, 0XFF, 0XFF, 0XFF, 0XFF, 0XFF,
                0XFF, 0XFF, 0XFF, 0XFF, 0XFF, 0XFF, 0XFF, 0XFF, 0XFF, 0XFF, 0XFF, 0XFF, 0XFF, 0XFF, 0XFF, 0XFF,
                0XFF, 0XFF, 0XFF, 0XFF, 0XFF, 0XFF, 0XFF, 0XFF, 0XFF, 0XFF, 0XFF, 0XFF, 0XFF, 0XFF, 0XFF, 0XFF,
                0XFF, 0XFF, 0XFF, 0XFF, 0XFF, 0XFF, 0XFF, 0XFF, 0XFF, 0XFF, 0XFF, 0XFF, 0XFF, 0XFF, 0XFF, 0XFF,
                0XFF, 0XFF, 0XFF, 0XFF, 0XFF, 0XFF, 0XFF, 0XFF, 0XFF, 0XFF, 0XFF, 0XFF, 0XFF, 0XFF, 0XFF, 0XFF,
                0XFF, 0XFF, 0XFF, 0XFF, 0XFF, 0XFF, 0XFF, 0XFF, 0XFF, 0XFF, 0XFF, 0XFF, 0XFF, 0XFF, 0XFF, 0XFF,
                0XFF, 0XFF, 0XFF, 0XFF, 0XFF, 0XFF, 0XFF, 0XFF, 0XFF, 0XFF, 0XFF, 0XFF, 0XFF, 0XFF, 0XFF, 0XFF,
                0XFF, 0XFF, 0XFF, 0XFF, 0XFF, 0XFF, 0XFF, 0XFF, 0XFF, 0XFF, 0XFF, 0XFF, 0XFF, 0XFF, 0XFF, 0XFF,
                0XFF, 0XFF, 0XFF, 0XFF, 0XFF, 0XFF, 0XFF, 0XFF, 0XFF, 0XFF, 0XFF, 0XFF, 0XFF, 0XFF, 0XFF, 0XFF,
                0XFF, 0XFF, 0XFF, 0XFF, 0XFF, 0XFF, 0XFF, 0XFF, 0XFF, 0XFF, 0XFF, 0XFF, 0XFF, 0XFF, 0XFF, 0XFF,
                0XFF, 0XFF, 0XFF, 0XFF, 0XFF, 0XFF, 0XFF, 0XFF, 0XFF, 0XFF, 0XFF, 0XFF, 0XFF, 0XFF, 0XFF, 0XFF,
                0XFF, 0XFF, 0XFF, 0XFF, 0XFF, 0XFF, 0XFF, 0XFF, 0XFF, 0XFF, 0XFF, 0XFF, 0XFF, 0XFF, 0XFF, 0XFF,
                0XFF, 0XFF, 0XFF, 0XFF, 0XFF, 0XFF, 0XFF, 0XFF, 0XFF, 0XFF, 0XFF, 0XFF, 0XFF, 0XFF, 0XFF, 0XFF,
                0XFF, 0XFF, 0XFF, 0XFF, 0XFF, 0XFF, 0XFF, 0XFF, 0XFF, 0XFF, 0XFF, 0XFF, 0XFF, 0XFF, 0XFF, 0XFF,
                0XFF, 0XFF, 0XFF, 0XFF, 0XFF, 0XFF, 0XFF, 0XFF, 0XFF, 0XFF, 0XFF, 0XFF, 0XFF, 0XFF, 0XFF, 0XFF,
                0XFF, 0XFF, 0XFF, 0XFF, 0XFF, 0XFF, 0XFF, 0XFF, 0XFF, 0XFF, 0XFF, 0XFF, 0XFF, 0XFF, 0XFF, 0XFF,
                0XFF, 0XFF, 0XFF, 0XFF, 0XFF, 0XFF, 0XFF, 0XFF, 0XFF, 0XFF, 0XFF, 0XFF, 0XFF, 0XFF, 0XFF, 0XFF,
                0XFF, 0XFF, 0XFF, 0XFF, 0XFF, 0XFF, 0XFF, 0XFF, 0XFF, 0XFF, 0XFF, 0XFF, 0XFF, 0XFF, 0XFF, 0XFF,
                0XFF, 0XFF, 0XFF, 0XFF, 0XFF, 0XFF, 0XFF, 0XFF, 0XFF, 0XFF, 0XFF, 0XFF, 0XFF, 0XFF, 0XFF, 0XFF,
                0XFF, 0XFF, 0XFF, 0XFF, 0XFF, 0XFF, 0XFF, 0XFF, 0XFF, 0XFF, 0XFF, 0XFF, 0XFF, 0XFF, 0XFF, 0XFF,
                0XFF, 0XFF, 0XFF, 0XFF, 0XFF, 0XFF, 0XFF, 0XFF, 0XFF, 0XFF, 0XFF, 0XFF, 0XFF, 0XFF, 0XFF, 0XFF,
                0XFF, 0XFF, 0XFF, 0XFF, 0XFF, 0XFF, 0XFF, 0XFF, 0XFF, 0XFF, 0XFF, 0XFF, 0XFF, 0XFF, 0XFF, 0XFF,
                0XFF, 0XFF, 0XFF, 0XFF, 0XFF, 0XFF, 0XFF, 0XFF, 0XFF, 0XFF, 0XFF, 0XFF, 0XFF, 0XFF, 0XFF, 0XFF,
                0XFF, 0XFF, 0XFF, 0XFF, 0XFF, 0XFF, 0XFF, 0XFF, 0XFF, 0XFF, 0XFF, 0XFF, 0XFF, 0XFF, 0XFF, 0XFF,
                0XFF, 0XFF, 0XFF, 0XFF, 0XFF, 0XFF, 0XFF, 0XFF, 0XFF, 0XFF, 0XFF, 0XFF, 0XFF, 0XFF, 0XFF, 0XFF,
                0XFF, 0XFF, 0XFF, 0XFF, 0XFF, 0XFF, 0XFF, 0XFF, 0XFF, 0XFF, 0XFF, 0XFF, 0XFF, 0XFF, 0XFF, 0XFF,
                0XFF, 0XFF, 0XFF, 0XFF, 0XFF, 0XFF, 0XFF, 0XFF, 0XFF, 0XFF, 0XFF, 0XFF, 0XFF, 0XFF, 0XFF, 0XFF,
                0XFF, 0XFF, 0XFF, 0XFF, 0XFF, 0XFF, 0XFF, 0XFF, 0XFF, 0XFF, 0XFF, 0XFF, 0XFF, 0XFF, 0XFF, 0XFF,
                0XFF, 0XFF, 0XFF, 0XFF, 0XFF, 0XFF, 0XFF, 0XFF, 0XFF, 0XFF, 0XFF, 0XFF, 0XFF, 0XFF, 0XFF, 0XFF,
                0XFF, 0XFF, 0XFF, 0XFF, 0XFF, 0XFF, 0XFF, 0XFF, 0XFF, 0XFF, 0XFF, 0XFF, 0XFF, 0XFF, 0XFF, 0XFF,
                0XFF, 0XFF, 0XFF, 0XFF, 0XFF, 0XFF, 0XFF, 0XFF, 0XFF, 0XFF, 0XFF, 0XFF, 0XFF, 0XFF, 0XFF, 0XFF,
                0XFF, 0XFF, 0XFF, 0XFF, 0XFF, 0XFF, 0XFF, 0XFF, 0XFF, 0XFF, 0XFF, 0XFF, 0XFF, 0XFF, 0XFF, 0XFF,
                0XFF, 0XFF, 0XFF, 0XFF, 0XFF, 0XFF, 0XFF, 0XFF, 0XFF, 0XFF, 0XFF, 0XFF, 0XFF, 0XFF, 0XFF, 0XFF,
                0XFF, 0XFF, 0XFF, 0XFF, 0XFF, 0XFF, 0XFF, 0XFF, 0XFF, 0XFF, 0XFF, 0XFF, 0XFF, 0XFF, 0XFF, 0XFF,
                0XFF, 0XFF, 0XFF, 0XFF, 0XFF, 0XFF, 0XFF, 0XFF, 0XFF, 0XFF, 0XFF, 0XFF, 0XFF, 0XFF, 0XFF, 0XFF,
                0XFF, 0XFF, 0XFF, 0XFF, 0XFF, 0XFF, 0XFF, 0XFF, 0XFF, 0XFF, 0XFF, 0XFF, 0XFF, 0XFF, 0XFF, 0XFF,
                0XFF, 0XFF, 0XFF, 0XFF, 0XFF, 0XFF, 0XFF, 0XFF, 0XFF, 0XFF, 0XFF, 0XFF, 0XFF, 0XFF, 0XFF, 0XFF,
                0XFF, 0XFF, 0XFF, 0XFF, 0XFF, 0XFF, 0XFF, 0XFF, 0XFF, 0XFF, 0XFF, 0XFF, 0XFF, 0XFF, 0XFF, 0XFF,
                0XFF, 0XFF, 0XFF, 0XFF, 0XFF, 0XFF, 0XFF, 0XFF, 0XFF, 0XFF, 0XFF, 0XFF, 0XFF, 0XFF, 0XFF, 0XFF,
                0XFF, 0XFF, 0XFF, 0XFF, 0XFF, 0XFF, 0XFF, 0XFF, 0XFF, 0XFF, 0XFF, 0XFF, 0XFF, 0XFF, 0XFF, 0XFF,
                0XFF, 0XFF, 0XFF, 0XFF, 0XFF, 0XFF, 0XFF, 0XFF, 0XFF, 0XFF, 0XFF, 0XFF, 0XFF, 0XFF, 0XFF, 0XFF,
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

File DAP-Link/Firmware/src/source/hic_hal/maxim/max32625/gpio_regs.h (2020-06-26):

/* ****************************************************************************
 * Copyright (C) 2016 Maxim Integrated Products, Inc., All Rights Reserved.
 *
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
 * Except as contained in this notice, the name of Maxim Integrated
 * Products, Inc. shall not be used except as stated in the Maxim Integrated
 * Products, Inc. Branding Policy.
 *
 * The mere transfer of this software does not imply any licenses
 * of trade secrets, proprietary technology, copyrights, patents,
 * trademarks, maskwork rights, or any other form of intellectual
 * property whatsoever. Maxim Integrated Products, Inc. retains all
 * ownership rights.
 *
*************************************************************************** */

/* Define to prevent redundant inclusion */
#ifndef _MXC_GPIO_REGS_H_
#define _MXC_GPIO_REGS_H_

/* **** Includes **** */
#include <stdint.h>

#ifdef __cplusplus
extern "C" {
#endif

///@cond
/*
    If types are not defined elsewhere (CMSIS) define them here
*/
#ifndef __IO
#define __IO volatile
#endif
#ifndef __I
#define __I  volatile const
#endif
#ifndef __O
#define __O  volatile
#endif
#ifndef __R
#define __R  volatile const
#endif
///@endcond

/* **** Definitions **** */

/**
 * @defgroup    gpio_registers Registers
 * @ingroup     gpio
 * @brief       Registers, Bit Masks and Bit Positions for the GPIO Peripheral Module.
 * @{
 */

/*
   Typedefed structure(s) for module registers (per instance or section) with direct 32-bit
   access to each register in module.
*/

/**
 * Structure type to access the GPIO Registers
 */
typedef struct {
    __IO uint32_t rst_mode[16];                          /**< <tt>\b 0x0000-0x003C</tt> GPIO_RST_MODE_P[0..15] Registers - Power-On Reset Output Drive Mode     */
    __IO uint32_t free[16];                              /**< <tt>\b 0x0040-0x007C</tt> GPIO_FREE_P[0..15] Registers - Free for GPIO Operation Flags            */
    __IO uint32_t out_mode[16];                          /**< <tt>\b 0x0080-0x00BC</tt> GPIO_OUT_MODE_P[0..15] Registers - Output Drive Mode                    */
    __IO uint32_t out_val[16];                           /**< <tt>\b 0x00C0-0x00FC</tt> GPIO_OUT_VAL_P[0..15] Registers - GPIO Output Value                     */
    __IO uint32_t func_sel[16];                          /**< <tt>\b 0x0100-0x013C</tt> GPIO_FUNC_SEL_P[0..15] Registers - GPIO Function Select                 */
    __IO uint32_t in_mode[16];                           /**< <tt>\b 0x0140-0x017C</tt> GPIO_IN_MODE_P[0..15] Registers - GPIO Input Monitoring Mode            */
    __IO uint32_t in_val[16];                            /**< <tt>\b 0x0180-0x01BC</tt> GPIO_IN_VAL_P[0..15] Registers - GPIO Input Value                       */
    __IO uint32_t int_mode[16];                          /**< <tt>\b 0x01C0-0x01FC</tt> GPIO_INT_MODE_P[0..15] Registers - Interrupt Detection Mode             */
    __IO uint32_t intfl[16];                             /**< <tt>\b 0x0200-0x023C</tt> GPIO_INTFL_P[0..15] Registers - Interrupt Flags                         */
    __IO uint32_t inten[16];                             /**< <tt>\b 0x0240-0x027C</tt> GPIO_INTEN_P[0..15] Registers - Interrupt Enables                       */
} mxc_gpio_regs_t;
/**@} end of gpio_registers group */
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

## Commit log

2020-06-22 [3D Model] Add step files.
    [L-ink.PrjPCB, L-ink.SchDoc, case.step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]
2020-06-22 [Hardware] Add release files.
    [BOM.xlsx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]
2020-06-26 [Debugger] Add DAP-Link hardware and firmware.
    [daplink_pzh.PcbDoc, daplink_pzh.PrjPCB, daplink_pzh.SchDoc]
2020-07-24 [Model] Add unibody version case model.
    [L-ink-up.STL.stl, case with hook.stl, case.step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]
2021-01-10 Add 5-Axis button version by @simonire.

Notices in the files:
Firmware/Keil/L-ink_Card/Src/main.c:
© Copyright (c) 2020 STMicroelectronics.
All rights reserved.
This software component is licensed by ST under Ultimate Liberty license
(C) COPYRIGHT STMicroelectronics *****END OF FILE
